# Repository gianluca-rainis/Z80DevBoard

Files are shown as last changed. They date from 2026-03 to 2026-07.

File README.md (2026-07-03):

# Z80DevBoard








The Z80DevBoard is an advanced development board for the Z80 microprocessor, based on the RP2040.

This board is meant to be a practical educational tool, to help students learn how the Z80, one of the first CPUs and the foundation of all modern ones, works, and how to develop software for it.

To the Z80 is combined a modern RP2040, a powerful microcontroller designed by Raspberry Pi.
It allows easy interaction with the board's components: you can load a program for the Z80 into RAM; or establish a serial connection with the computer to perform live operations, such as reading and writing to RAM.

The most educational components of the board are the LED matrices, which provide real-time visual feedback on the Z80's activity.
Thanks to these LEDs, you can see which address of the RAM the Z80 is accessing, the byte it's reading or writing, whether it is answering to a BUSREQ with a BUSACK, and essentially all the operations the Z80 is executing.

The board mounts five buttons: the four on the right allow the student to save a Z80 program to flash, load a custom firmware for the RP2040, reset the Z80, and put the Z80 into a wait state.
The button on the left sends a manual clock signal to the Z80, in fact, the board mounts a *Z84C00* (the *CMOS* version of the Z80) specifically to allow it to work even with a manual clock.

The board can be connected to a computer through a *USB-C* port, which provides both power and data transmission.
On the bottom-right of the board, are mounted two pin sockets, to support expansion boards or to be used in more advanced projects that require additional hardware.

For more advanced debugging, when testing custom firmware, the *SWD* and *SWCLK* pins of the RP2040 are accessible on the top-right of the board.

Front view of the dev board
Front view of the dev board

---

Z80DevBoard Picture

## Author
The author of the whole project is: 
**Gianluca Rainis** - [gianluca-rainis](https://github.com/gianluca-rainis) on GitHub.

## Sponsor
The PCB prototyping for this project is sponsored by **[PCBWay](https://www.pcbway.com)**.

The *boards* were manufactured with **high precision**, faithfully **following the PCB design down to the smallest details**.
The *silkscreen* is **crisp and perfectly readable**, with **no errors or misalignments**.
The *board edges* and corner's holes were **cut cleanly and accurately**.
The *drill holes* **match the component footprints exactly**, making placement and soldering straightforward.
The *SMD pads* are **precise and clean**, even for the most challenging footprints, and solder beautifully.

The *PCBWay website* is **intuitive, even for first-time users**.
**Placing an order is simple**, and before proceeding to payment **the design is reviewed by their technical staff**, who catch and communicate **any potential manufacturing issues** promptly and professionally, avoiding problems before production even begins.

> If you are looking for a reliable, high-quality PCB manufacturer for your own projects, **[PCBWay](https://www.pcbway.com)** is highly recommended!

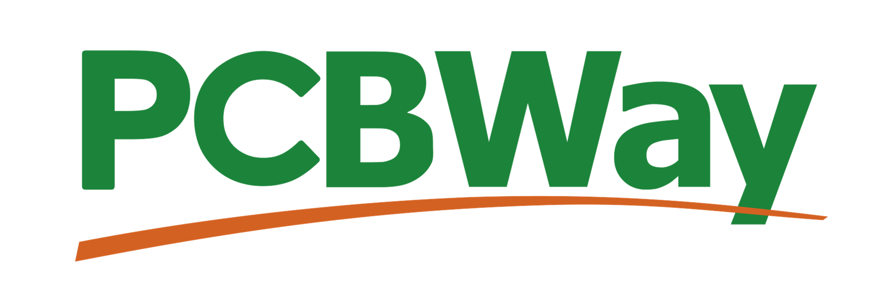
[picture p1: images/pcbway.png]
PCBWay (https://www.pcbway.com)


## License
### Hardware design files (schematics, PCB, BOM):
Licensed under [CERN-OHL-S v2.0](LICENSE-CERN-OHL-S.md)

### Software, firmware and documentation:
Licensed under the [MIT License](LICENSE-MIT.md)

## AI Disclaimer
**No AI was used in the conception, design, engineering, or development of this project**.
Every circuit and every design decision is the original work of the author.

*AI tools* were used solely as a **writing assistant** for **parts of the documentation**, to help refine and organize technical explanations.
**All content has been reviewed, verified, and edited by the author.**

## Documentation
The full documentation is available in the [`docs/`](docs/index.md) folder.

## Development Tools
- **PCB Design:** KiCad
- **Documentation and code:** Visual Studio Code

## PCB Manufacturing
The Gerber files for PCB manufacturing are available in the [`gerber/`](gerber/) directory.

## Project Structure
```
Z80DevBoard/
├── customFootprints.pretty/  # Custom footprints
├── docs/                     # The documentation and the guides
├── firmware/                 # The RP2040 firmware
├── gerber/                   # PCB manufacturing files (Gerber format)
├── images/                   # Documentation images and KiCad symbols
├── .gitattributes            # Gitattributes file
├── .gitignore                # Gitignore file
├── gerber.zip                # Zip folder with all the gerber files
├── Z80DevBoard.kicad_pcb     # PCB layout file
├── Z80DevBoard.kicad_pro     # KiCad project file
├── Z80DevBoard.kicad_sch     # Schematic file
├── Z80DevBoard.step          # 3D model
├── BOM.csv                   # Bill Of Materials
├── CHANGELOG.md              # Change log of the project
├── JOURNAL.md                # Journal of the project
├── LICENSE-CERN-OHL-S.md     # CERN-OHL-S License
├── LICENSE-MIT.md            # MIT License
└── README.md                 # This file
```

## Images
### Schematic Diagrams
#### Complete Schematic (A2 format)
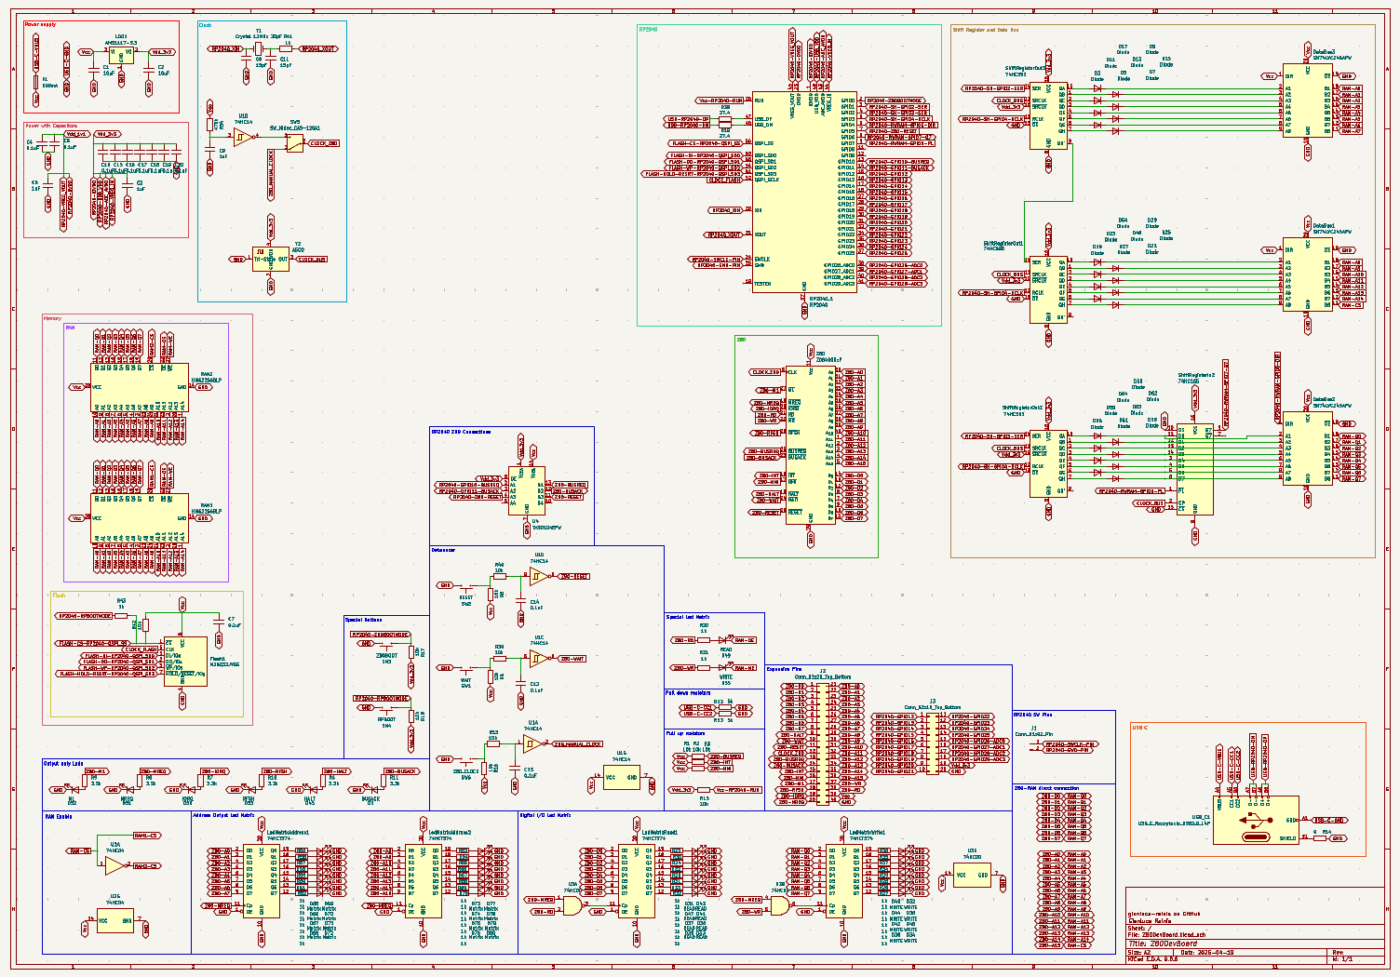
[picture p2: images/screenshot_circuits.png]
Complete schematic


#### Z80 Section
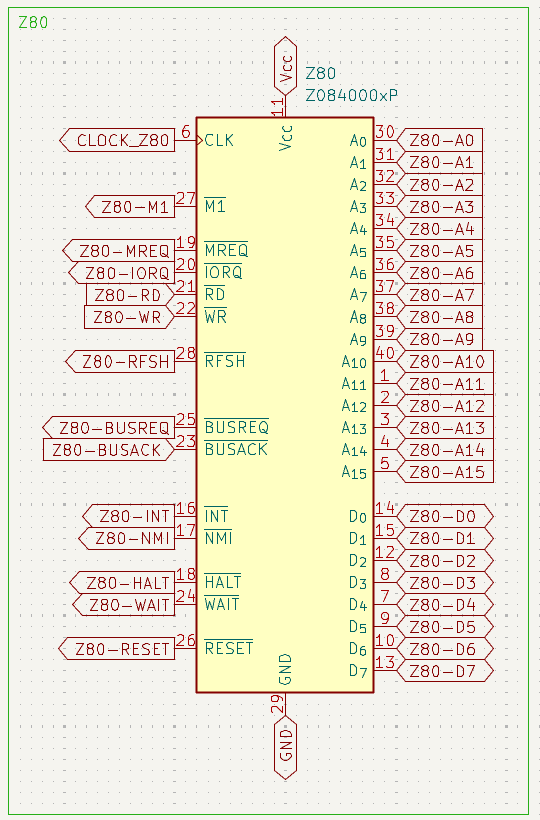
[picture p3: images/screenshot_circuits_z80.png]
Z80 subsystem schematic


#### RP2040 Section
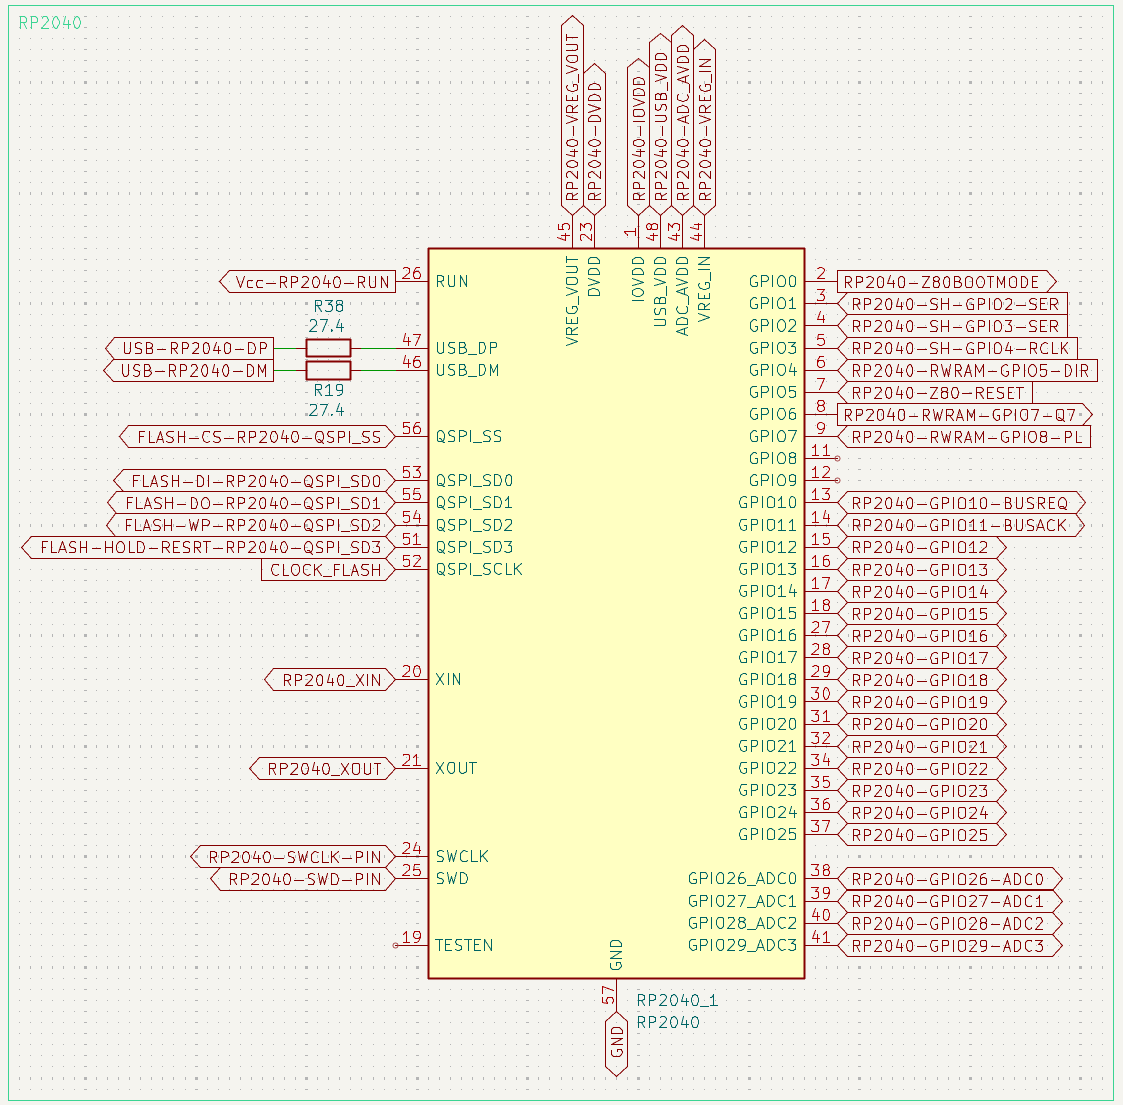
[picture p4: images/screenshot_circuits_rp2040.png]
RP2040 subsystem schematic


### PCB Layout
#### Without Silkscreen
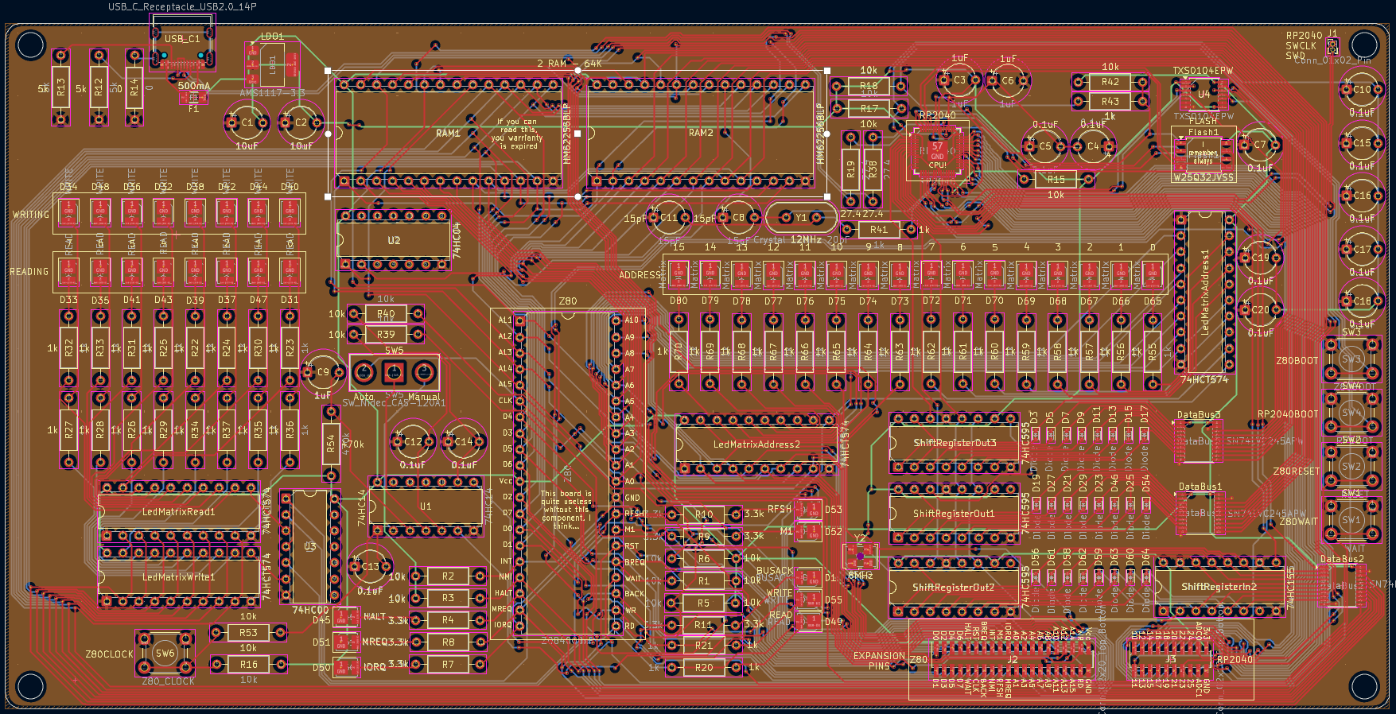
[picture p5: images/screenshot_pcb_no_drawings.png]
PCB layout without silkscreen


#### With Silkscreen
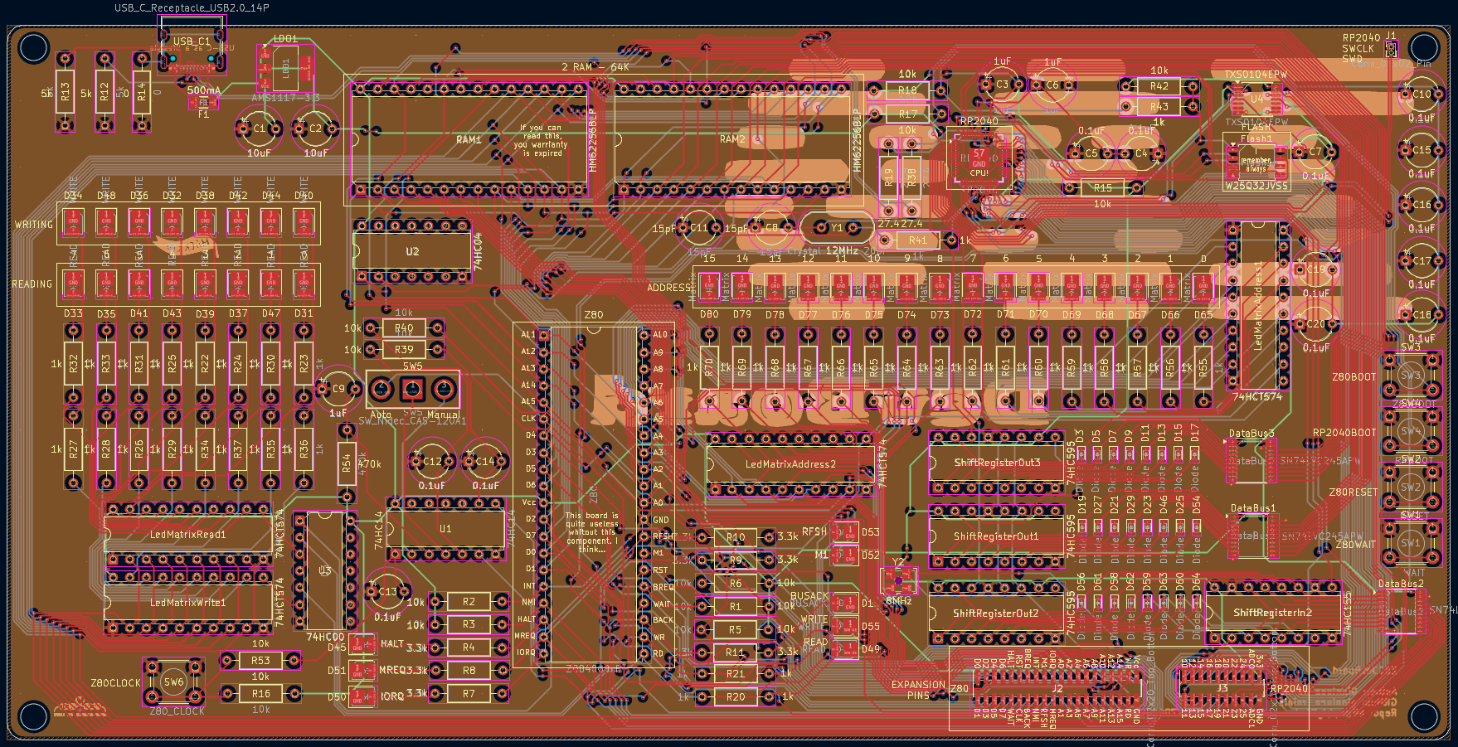
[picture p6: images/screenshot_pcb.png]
PCB layout with silkscreen


### 3D Renders
#### Front View
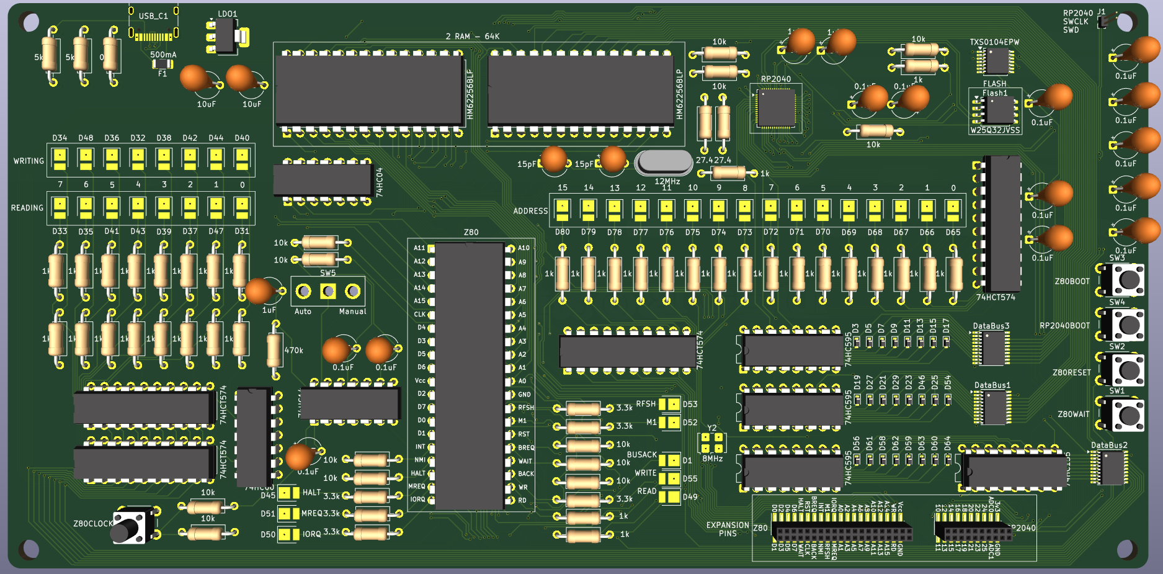
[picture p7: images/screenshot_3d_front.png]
3D render - front view


#### Back View
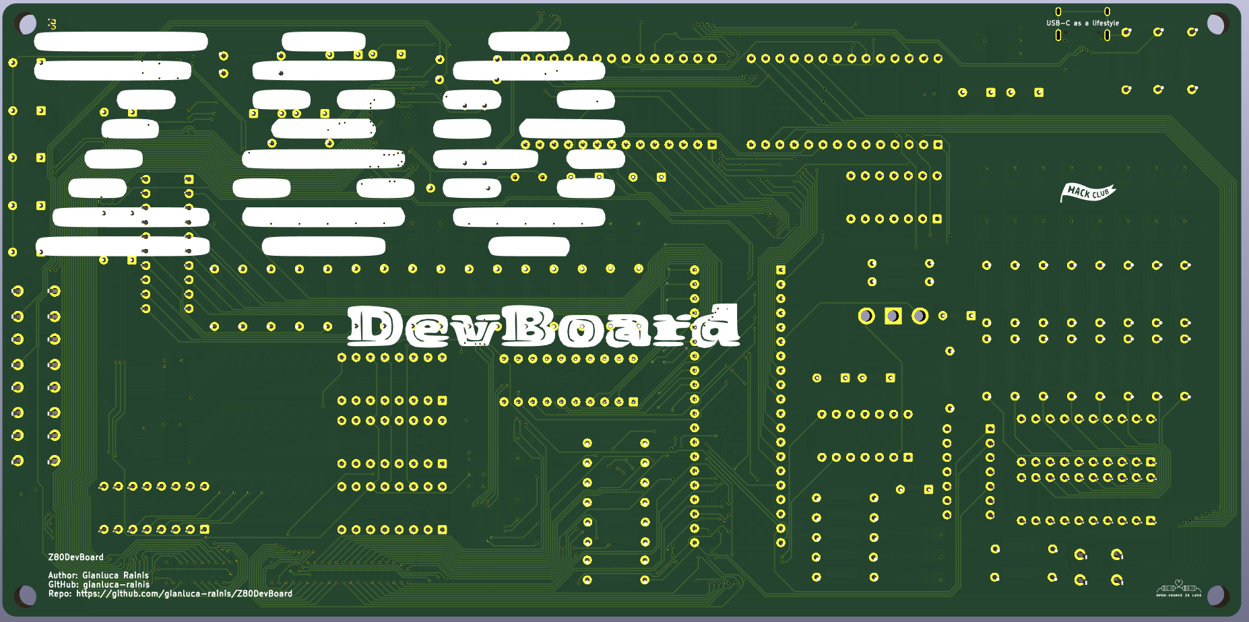
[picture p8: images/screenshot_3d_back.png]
3D render - back view


## Technical Details
- **Size**: 219mm x 108.5mm
- **Layers**: 4
- **Supply Voltage**: 5V, 3v3

## Components Table
|Name|Quantity|Class|Type|
|--|--|--|--|
|Z84C00|1|Microprocessor|Through Holes|
|RP2040|1|Microprocessor|SMD|
|||||
|HM62256BLP|2|Memory|Through Holes|
|W25Q32JVSS|1|Memory|SMD|
|||||
|AMS1117-3.3|1|Power Management|SMD|
|||||
|USB C 2.0 port|1|Data Bus|Through Holes|
|74HC595|3|Data Bus|Through Holes|
|74HC155|1|Data Bus|Through Holes|
|74HCT574|4|Data Bus|Through Holes|
|SN74LVC245APW|3|Data Bus|SMD|
|TXS0104EPW|1|Data Bus|SMD|
|Connector 2 pins|1|Data Bus|Through Holes|
|Connector 2×20 pins|1|Data Bus|Through Holes|
|Connector 2×10 pins|1|Data Bus|Through Holes|
|||||
|Crystal 12MHz 20pF|1|Clock|Through Holes|
|Oscillator 8MHz|1|Clock|SMD|
|||||
|74HC14|1|Support components|Through Holes|
|74HC04|1|Support components|Through Holes|
|74HC00|1|Support components|Through Holes|
|||||
|Resistor 0 ohm|1|Resistor|Through Holes|
|Resistor 27.4 ohm|2|Resistor|Through Holes|
|Resistor 1k ohm|36|Resistor|Through Holes|
|Resistor 3.3k ohm|6|Resistor|Through Holes|
|Resistor 5k ohm|2|Resistor|Through Holes|
|Resistor 10k ohm|13|Resistor|Through Holes|
|Resistor 470k ohm|1|Resistor|Through Holes|
|||||
|Capacitors 15pF|2|Capacitor|Through Holes|
|Capacitors 0.1uF|13|Capacitor|Through Holes|
|Capacitors 1uF|4|Capacitor|Through Holes|
|Capacitors 10uF|2|Capacitor|Through Holes|
|||||
|Button|5|Other|Through Holes|
|Switch|1|Other|Through Holes|
|LED|40|Other|SMD|
|Diodes|24|Other|SMD|
|Fuse 500mA|1|Other|SMD|

## Firmware
### Firmware Video Presentation
https://github.com/user-attachments/assets/ee6d8d69-4003-4e21-8f2b-2f08ad0c8d81

### Build
From the project root, make sure CMake and the ARM GNU toolchain (arm-none-eabi-gcc) are installed.

If the toolchain is not in your PATH, provide it explicitly with PICO_TOOLCHAIN_PATH:

```bash
cmake -S firmware -B firmware/build -DPICO_TOOLCHAIN_PATH=/path/to/arm-gnu-toolchain
cmake --build firmware/build --parallel
```

If the toolchain is already in your PATH, you can omit PICO_TOOLCHAIN_PATH.

#### Output file
The file to load in the RP2040's memory after the build is `Z80DevBoard.uf2`.
You can find it in the `/firmware/build` folder.

> You can find more informations about the firmware, including how to write a custom one, in the [documentation](docs/index.md).

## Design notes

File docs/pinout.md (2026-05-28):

# Chapter 3 - Pinout & Connectors

## 3.1 Z80 Pinout
The *Z84C00* is available in a **40-pin DIP package**.
The pinout below reflects the official Zilog datasheet.

```
              ┌───────────────────┐
       A11 ⬅ │  1             40 │ ⮕ A10
       A12 ⬅ │  2     Z80     39 │ ⮕ A9
       A13 ⬅ │  3             38 │ ⮕ A8
       A14 ⬅ │  4             37 │ ⮕ A7
       A15 ⬅ │  5             36 │ ⮕ A6
       CLK ⮕ │  6             35 │ ⮕ A5
        D4 ⬌ │  7             34 │ ⮕ A4
        D3 ⬌ │  8             33 │ ⮕ A3
        D5 ⬌ │  9             32 │ ⮕ A2
        D6 ⬌ │ 10             31 │ ⮕ A1
       Vcc ⮕ │ 11             30 │ ⮕ A0
        D2 ⬌ │ 12             29 │ ⬅ GND
        D7 ⬌ │ 13             28 │ ⮕ /RFSH
        D0 ⬌ │ 14             27 │ ⮕ /M1
        D1 ⬌ │ 15             26 │ ⬅ /RESET
      /INT ⮕ │ 16             25 │ ⬅ /BUSRQ
      /NMI ⮕ │ 17             24 │ ⬅ /WAIT
     /HALT ⬅ │ 18             23 │ ⮕ /BUSACK
     /MREQ ⬅ │ 19             22 │ ⮕ /WR
     /IORQ ⬅ │ 20             21 │ ⮕ /RD
              └───────────────────┘
```

|Symbol|Pin|Direction|Description|
|---|---|---|---|
|A0–A15|30-40, 1–5|Output|16-bit address bus|
|D0–D7|14, 15, 12, 8, 7, 9, 10, 13|Bidirectional|8-bit data bus|
|CLK|6|Input|System clock|
|/MREQ|19|Output|Memory request (active low)|
|/IORQ|20|Output|I/O request (active low)|
|/RD|21|Output|Read operation indicator (active low)|
|/WR|22|Output|Write operation indicator (active low)|
|/M1|27|Output|With /MREQ indicates opcode fetch cycle, with /IORQ indicates interrupt acknowledge cycle (active low)|
|/RFSH|28|Output|DRAM refresh cycle (active low)|
|/HALT|18|Output|CPU halted (active low)|
|/WAIT|24|Input|Insert wait states (active low)|
|/INT|16|Input|Maskable interrupt request (active low)|
|/NMI|17|Input|Non-maskable interrupt request (active low)|
|/RESET|26|Input|Reset (active low)|
|/BUSRQ|25|Input|Bus request (active low)|
|/BUSACK|23|Output|Bus acknowledge (active low)|
|Vcc|11|Power|+5V supply|
|GND|29|Power|Ground|

## 3.2 RP2040 Pinout
The *RP2040* is available in a **56-pin QFN package**.
The pinout below reflects the official Raspberry Pi datasheet.

```
QSPI_SS_N QSPI_SD1 QSPI_SD2 QSPI_SD0 QSPI_SCLK QSPI_SD3 DVDD IOVDD USB_VDD USB_DP USB_DM VREG_VIN VREG_VOUT ADC_AVDD
       ┌───────────────────────────────────────────────┐
       │   56 55 54 53 52 51 50 49 48 47 46 45 44 43   │
       │                                               │
 IOVDD │  1                                         42 │ IOVDD
 GPIO0 │  2                                         41 │ GPIO29/ADC3
 GPIO1 │  3                                         40 │ GPIO28/ADC2
 GPIO2 │  4                                         39 │ GPIO27/ADC1
 GPIO3 │  5              ┌───────────┐              38 │ GPIO26/ADC0
 GPIO4 │  6              │           │              37 │ GPIO25
 GPIO5 │  7              │    GND    │              36 │ GPIO24
 GPIO6 │  8              │           │              35 │ GPIO23
 GPIO7 │  9              └───────────┘              34 │ GPIO22
 IOVDD │ 10                                         33 │ IOVDD
 GPIO8 │ 11                                         32 │ GPIO21
 GPIO9 │ 12                                         31 │ GPIO20
GPIO10 │ 13                                         30 │ GPIO19
GPIO11 │ 14                                         29 │ GPIO18
       │                                               │
       │   15 16 17 18 19 20 21 22 23 24 25 26 27 28   │
       └───────────────────────────────────────────────┘
GPIO12 GPIO13 GPIO14 GPIO15 TESTEN XIN XOUT IOVDD DVDD SWCLK SWDIO RUN GPIO16 GPIO17
```

|Symbol|Pin|Direction|Description|
|---|---|---|---|
|GPIO0–GPIO25|2-9, 11-18, 27-32, 34-37|Configurable|General purpose I/O|
|GPIO26/ADC0|38|Configurable|GPIO or ADC (Analog to Digital Converter) channel 0|
|GPIO27/ADC1|39|Configurable|GPIO or ADC (Analog to Digital Converter) channel 1|
|GPIO28/ADC2|40|Configurable|GPIO or ADC (Analog to Digital Converter) channel 2|
|GPIO29/ADC3|41|Configurable|GPIO or ADC (Analog to Digital Converter) channel 3|
|XIN|20|Input|Crystal oscillator input (12 MHz)|
|XOUT|21|Output|Crystal oscillator output|
|USB_DP|47|Bidirectional|USB D+ (27Ω resistor required)|
|USB_DM|46|Bidirectional|USB D− (27Ω resistor required)|
|SWCLK|24|Input|SWD clock (debug)|
|SWDIO|25|Bidirectional|SWD data (debug)|
|RUN|26|Input|Reset (active low)|
|VREG_VIN|45|Power|Voltage regulator input (1.8V to 3.3V) (1uF capacitor required)|
|VREG_VOUT|44|Power|Voltage regulator output (1.1V core) (1uF capacitor required)|
|IOVDD|1, 10, 22, 33, 42, 49|Power|GPIO supply (1.8V to 3.3V)|
|DVDD|23, 50|Power|Digital core supply (1.1V)|
|ADC_AVDD|43|Power|ADC analog supply (3.3V)|
|USB_VDD|48|Power|USB PHY supply (3.3V)|
|GND|Center Pad|Power|Ground|
|QSPI_*|51–56|Bidirectional|Interface to a SPI flash (Usable also as GPIO)|

## 3.3 Expansion Connector 2×20 (Z80 Bus)
The *Expansion Connector (Z80 Bus)* is a **2×20 pin connector** located on the bottom-right of the Z80DevBoard.
It exposes all **Z80 bus signals**, providing direct access to the CPU interface for daughter boards and external hardware.

```
 D0 D2 D4 D6 HALT RST BREQ INT M1 IORQ A0 A2 A4 A6 A8 A10 A12 A14 WR Vcc
  1  3  5  7  9 11 13 15 17 19 21 23 25 27 29 31 33 35 37 39
┌────────────────────────────────────────────────────────────┐
│ ●  ●  ●  ●  ●  ●  ●  ●  ●  ●  ●  ●  ●  ●  ●  ●  ●  ●  ●  ● │
│ ●  ●  ●  ●  ●  ●  ●  ●  ●  ●  ●  ●  ●  ●  ●  ●  ●  ●  ●  ● │
└────────────────────────────────────────────────────────────┘
  2  4  6  8 10 12 14 16 18 20 22 24 26 28 30 32 34 36 38 40
 D1 D3 D5 D7 WAIT CLK BACK NMI RFSH MREQ A1 A3 A5 A7 A9 A11 A13 A15 RD GND
```

|Symbol|Pin|Direction|Description|
|---|---|---|---|
|D0–D7|1-8|Bidirectional|8-bit data bus|
|HALT|9|Output|CPU halted (active low)|
|WAIT|10|Input|Insert wait states (active low)|
|RST|11|Input|Reset (active low)|
|CLK|12|Input|System clock|
|BREQ|13|Input|Bus request (active low)|
|BACK|14|Output|Bus acknowledge (active low)|
|INT|15|Input|Maskable interrupt request (active low)|
|NMI|16|Input|Non-maskable interrupt request (active low)|
|M1|17|Output|With MREQ indicates opcode fetch cycle, with IORQ indicates interrupt acknowledge cycle (active low)|
|RFSH|18|Output|DRAM refresh cycle (active low)|
|IORQ|19|Output|I/O request (active low)|
|MREQ|20|Output|Memory request (active low)|
|A0–A15|21-36|Output|16-bit address bus|
|WR|37|Output|Write operation indicator (active low)|
|RD|38|Output|Read operation indicator (active low)|
|Vcc|39|Power|+5V supply|
|GND|40|Power|Ground|

## 3.4 Expansion Connector 2×10 (RP2040)
The *Expansion Connector (RP2040)* is a **2×10 pin connector** located on the bottom-right of the Z80DevBoard.
It exposes GPIO pins 10 through 25, two ADC pins, and the 3v3 power rail, allowing the development of more advanced projects on expansion boards with custom firmware.

```
 GPIO10 GPIO12 GPIO14 GPIO16 GPIO18 GPIO20 GPIO22 GPIO24 ADC0 3v3
  1  3  5  7  9 11 13 15 17 19
┌──────────────────────────────┐
│ ●  ●  ●  ●  ●  ●  ●  ●  ●  ● │
│ ●  ●  ●  ●  ●  ●  ●  ●  ●  ● │
└──────────────────────────────┘
  2  4  6  8 10 12 14 16 18 20
 GPIO11 GPIO13 GPIO15 GPIO17 GPIO19 GPIO21 GPIO23 GPIO25 ADC1 GND
```

|Symbol|Pin|Direction|Description|
|---|---|---|---|
|GPIO10-GPIO25|1-16|Configurable|General purpose I/O|
|ADC0-ADC1|17-18|Configurable|GPIO or ADC (Analog to Digital Converter) channel 0 and 1|
|3v3|19|Power|+3.3V supply|
|GND|20|Power|Ground|

## 3.5 SWD Debug Connector
The SWD (*Serial Wire Debug*) interface is exposed through two dedicated pins located in the top-right corner of the Z80DevBoard.
It provides a direct connection to the RP2040's debug port, allowing firmware to be flashed and debugged using any SWD-compatible adapter, such as a *Raspberry Pi Debug Probe*.

```
 SWCLK
  1
┌───┐
│ ● │
│ ● │
└───┘
  2
 SWD
```

|Symbol|Pin|Direction|Description|
|---|---|---|---|
|SWCLK|1|Input|SWD clock (debug)|
|SWD|2|Bidirectional|SWD data (debug)|

> A ground reference is available on the *GND* pins of the *Expansion connector*.

---

<div>
  <p align="left">
    <em>
      <b>
        <a href="/docs/hardware.md">
          ← Back
        </a>
      </b>
    </em>
  </p>

  <p align="right">
    <em>
      <b>
        <a href="/docs/quickstart.md">
          Next Section →
        </a>
      </b>
    </em>
  </p>
</div>

---

<p align="center">
    <em>Open source, Open Education - Z80DevBoard</em>
</p>

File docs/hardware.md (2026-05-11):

# Chapter 2 - Hardware Architecture

## 2.1 System Overview
The Z80DevBoard is a **4-layer PCB** measuring *219 × 108.5 mm*, designed around two central processing units: the **Z84C00** (Z80) and the **RP2040**.
The board operates at **5V** via USB-C, with an onboard *AMS1117-3.3* regulator supplying the **3.3V** rail to the RP2040 and the supporting logic.

The Z80 is the execution core: it runs assembly programs stored in the two onboard *HM62256BLP* SRAM chips, which together provide **64 KB of addressable memory**.

The RP2040 acts as the interface layer **between the developer and the board**: it reads the compiled program from the *W25Q32JVSS* flash memory and loads it into SRAM before releasing the Z80.

The data bus is managed by a set of *SN74LVC245APW* bus transceivers, which handle the **voltage difference** between the **Z80's 5V logic** and the **RP2040's 3.3V logic**.

Three *74HC595* shift registers allow the RP2040 to drive the bus over a serial interface, while the *74HC165* reads it back. A dedicated oscillator drives the Z80 clock, selectable between manual and automatic mode via an onboard switch; the RP2040 runs off a **12 MHz crystal**.

Forty LEDs, organized in matrices and driven by *74HCT574* buffers, provide **real-time visual feedback** of Z80 bus activity.

Two expansion connectors expose additional signals for daughter boards and custom projects.

## 2.2 The Z80 CPU
The Z80 is an **8-bit microprocessor** designed by ***Zilog*** and first introduced in 1976.
Despite its age, it remains one of the **most studied and documented CPU** architectures ever produced, and its influence can still be traced in modern instruction set designs.

The specific model used on the Z80DevBoard is the *Z84C00*: the ***CMOS* variant** of the original Z80.
Compared to the original *NMOS* version, the *Z84C00* offers several practical advantages: significantly **lower power consumption**, **full static operation** (meaning the clock can be slowed down to DC without losing register contents), and better **noise immunity** thanks to the wider logic voltage margins typical of *CMOS* technology.
It is also considerably easier to source today than original *NMOS* parts.

The *Z84C00* operates with a **5V supply** and communicates with the rest of the board through three buses: a **16-bit address bus**, an **8-bit bidirectional data bus**, and a set of control signals that coordinate every memory and I/O operation.
With 16 address lines, the CPU can directly address **up to 64 KB** of memory: exactly the amount provided by the onboard SRAM.

## 2.3 The RP2040
The RP2040 is a dual-core ARM Cortex-M0+ **microcontroller** developed by ***Raspberry Pi*** and released in 2021.
It runs at up to *133MHz*, integrates *264KB of SRAM*, and includes a rich set of peripherals, among which the most relevant is the *Programmable I/O* (*PIO*): a set of small, deterministic state machines capable of handling **GPIO pins** with cycle-accurate timing.

On the Z80DevBoard, the RP2040 serves as the primary interface between **the developer and the hardware**.
At boot, it **reads the compiled Z80 program** from the onboard flash memory and **transfers it into SRAM**, where the Z80 will execute it.
During execution, it monitors the Z80 control signals in real time, handles I/O bus cycles, and maintains the serial connection with the host computer over USB.

The RP2040 runs at **3.3V**, while the Z80 operates at **5V**.
All signals exchanged between the two pass through *level shifters* and *bus transceivers* that **handle the voltage difference** transparently.
Communication with the *shift registers*, used to **extend the RP2040's effective GPIO count**, happens over a **fast serial interface**, keeping the pin usage manageable without sacrificing bus performance.

The RP2040 also exposes its ***SWD* debug interface** on dedicated pins, allowing firmware to be **developed and debugged with standard tools** such as a ***Raspberry Pi Debug Probe*** or **any compatible SWD adapter**.

## 2.4 The SRAM
The Z80DevBoard mount two *HM62256BLP* chips as its main memory: a classic **32KB × 8-bit Asynchronous Static RAM**.
Mounted **in parallel**, the two chips provide **a combined address space** of *64KB*, which is **the maximum the Z80 can directly address** with its 16-bit address bus.

Unlike Dynamic RAM (*DRAM*), Static RAM **does not require periodic refresh cycles** to retain its contents.
This **simplifies the board design** considerably: there is **no need for a dedicated refresh controller**, and the Z80's `/RFSH` pin, which would normally **trigger DRAM refresh**, is simply **left unused**.
As long as the board is powered, the memory contents remain intact.

The *HM62256BLP* is an **asynchronous device**, meaning **it does not rely on a shared clock** signal to coordinate read and write operations.
Instead, timing is governed entirely by the Z80's control signals: `/MREQ`, `/RD`, and `/WR`, which the SRAM monitors directly.
A **read cycle** completes as soon as **the address has been stable** for the chip's access time; a **write cycle** latches the data **on the rising edge of `/WR`**.

At boot, the **RP2040 takes control of the bus** and **writes the compiled Z80 program** into *SRAM* before releasing the CPU from reset.
From that point on, the Z80 reads instructions and data, and writes results back, to these two chips for the entire duration of program execution.

## 2.5 The Flash Memory
The *W25Q32JVSS* is a *32Mbit* (*4MB*) ***SPI* *NOR* flash memory** chip, used on the Z80DevBoard as **persistent storage for the RP2040 firmware and the Z80 program**.
Unlike *SRAM*, flash memory **retains its contents** when the board is powered off, making it the natural choice for **storing code** that needs to survive **between sessions**.

The RP2040 communicates with the flash chip over **a dedicated *SPI* bus**.
At boot, it **reads the compiled Z80 program from flash** and transfers it into *SRAM* before releasing the Z80 from reset.
The RP2040's own firmware is also stored on the same chip, following the standard *Raspberry Pi Pico* architecture where the **RP2040 boots directly from an *external SPI flash***.

From the Z80's perspective, **the flash memory is completely invisible**: the CPU only ever interacts with the *SRAM*.
The flash is **exclusively managed by the RP2040**, which handles all read and write operations transparently in the background.

## 2.6 The LED Matrices
The Z80DevBoard features ***40 LEDs* organized in matrices**, one of the most distinctive and educationally valuable aspects of the board.
Each LED reflects **the real-time state of a specific signal or data line**, giving an **immediate visual representation** of **what the Z80 is doing** at any given moment, without the need for an oscilloscope or a logic analyzer.

The LEDs are driven by *74HCT574* *octal D-type flip-flop buffers*, which latch the current state of the bus.
Without buffering, the signals on a running Z80 bus change far too rapidly to be perceived directly, at even a modest clock frequency, individual bus cycles last only a few hundred nanoseconds.
The buffers solve this by capturing a snapshot of the bus state and holding it stable until the next update.

This is where the **manual clock mode becomes particularly powerful**: by stepping through the program one clock cycle at a time, **the LEDs update with each step**, allowing you to **follow the execution of every instruction in real time** and **observe exactly how the Z80 reads from and writes to memory**.
Combined with the serial connection to the RP2040, this makes the Z80DevBoard a **genuinely transparent system**: one where **the internal state of the CPU is always visible** and never hidden.

## 2.7 The Expansion Pins
The Z80DevBoard exposes **two expansion connectors** designed to make the board the foundation of a larger system, rather than a closed, self-contained unit.

The first is a *2×20 pin connector* that breaks out **all 40 pins of the Z80**: address bus, data bus, and control signals; giving direct access to the full CPU interface.
This connector is intended for daughter boards that **extend the Z80's environment**: additional memory, custom peripherals, or any hardware that needs to interact directly with the Z80 bus.

The second is a *2×10 pin connector* that exposes **a selection of RP2040** signals: the **3.3V and GND power** rails, the **two *ADC*** inputs (*ADC0* and *ADC1*), and *GPIO10* through *GPIO25*.
This connector is oriented towards **more advanced projects** where the **RP2040 itself needs to interact with external hardware**: sensors, displays, communication modules, or custom firmware **experiments that go beyond the standard board functionality**.

Together, the two connectors cover **both sides of the system**: the **Z80's classic parallel bus interface** and the **RP2040's modern programmable I/O**, making it possible to build virtually **any extension imaginable** on top of the Z80DevBoard.

## 2.8 The USB-C
The board **is powered and connected to the host computer** through a single *USB-C 2.0* connector.
It serves two distinct purposes simultaneously: **delivering the 5V supply voltage to the board**, and **providing a full-speed USB data connection to the RP2040**.

On the power side, the **5V** rail feeds the Z80 directly and passes through the onboard *AMS1117-3.3* regulator to generate the **3.3V** rail for the RP2040 and the supporting logic.
A *500mA* fuse protects the board from overcurrent conditions.

On the data side, the RP2040 enumerates as a *USB CDC* (*Communications Device Class*) serial device, appearing as a virtual *COM* port on the host computer.
This connection is used to **upload compiled Z80 programs** to the board, **interact with the RP2040** firmware, and **read any output the Z80 program produces** at runtime.
No special driver is required on Linux or macOS; on Windows, the board appears as a standard *COM* port in Device Manager.

The choice of *USB-C* makes the board **compatible with modern laptops and workstations** without the need for adapters, while keeping the connector **robust enough for repeated use in an educational environment**.

## 2.9 How It All Connects
The center of the board is the Z80, connected to the two *SRAM* chips through its full *16-bit* address bus and *8-bit* data bus.
Every memory access the Z80 performs (fetching an instruction, reading a variable, writing a result) travels directly across these buses to and from the *SRAM*.

The RP2040 sits **alongside the Z80**, connected to the same data and control buses through a set of *SN74LVC245APW* bus transceivers and *74HC595* - *74HC165* shift registers.
The transceivers **handle the voltage difference** between the Z80's 5V logic and the RP2040's 3.3V logic, while the shift registers allow the RP2040 to **read and drive the bus over a compact serial interface**, keeping GPIO usage under control.
A *TXS0104EPW* level shifter handles the `BUSREQ` and `BUSACK` signals specifically, which coordinate bus ownership between the two chips.

The *W25Q32JVSS* flash memory is connected exclusively to the RP2040 over *SPI*.
The Z80 has no direct access to it, the flash is managed only by the RP2040, which uses it to store firmware and the Z80 program persistently between sessions.

The LED matrices, driven by *74HCT574* buffers, display the state of data and address buses in real time.
The buffers stay between the bus and the LEDs, ensuring that the display logic **never interferes with bus** timing.

The *USB-C* connector provides 5V to the board and connects it directly to the RP2040's USB pins, establishing the serial link with the host computer.
The *AMS1117-3.3* regulator is positioned between the 5V input and the 3.3V rail, supplying the RP2040 and all the 3.3V logic on the board.

Finally, the two expansion connectors provide the Z80 bus and the RP2040 GPIO pins, making every relevant signal accessible to external hardware without interfering with the rest of the board.

The board is laid out on a 4-layer PCB.
The front copper layer (*F.Cu*) and the back copper layer (*B.Cu*) are used for the **general signal routing**.
The inner layer *In1.Cu* is dedicated to the **power distribution network**, carrying **both the 5V and 3.3V rails** across the board.
The inner layer *In2.Cu* is a **solid ground plane**, providing a **clean reference for all signals** and **reducing electromagnetic interference**.

---

<div>
  <p align="left">
    <em>
      <b>
        <a href="/docs/introduction.md">
          ← Back
        </a>
      </b>
    </em>
  </p>

  <p align="right">
    <em>
      <b>
        <a href="/docs/pinout.md">
          Next Section →
        </a>
      </b>
    </em>
  </p>
</div>

---

<p align="center">
    <em>Open source, Open Education - Z80DevBoard</em>
</p>

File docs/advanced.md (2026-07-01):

# Chapter 5 - Advanced Guide

## 5.1 Flashing the Firmware
To flash a new firmware onto the RP2040:
1. Hold the *RP2040BOOT* button while connecting the board to your computer through the USB-C port.
2. The RP2040 will expose a **mass storage device** on your computer: it will appear as a USB drive.
3. Copy your **compiled UF2 firmware** file onto the drive.
4. The RP2040 will reset automatically and boot with the new firmware.

> The latest official firmware for the Z80DevBoard is available in the firmware folder of the repository.

## 5.2 Serial Communication with the RP2040
The RP2040 exposes a **USB CDC (Communications Device Class) serial interface** over the USB-C connector, which appears as a virtual COM port on the host computer.
This interface allows sending commands to the board and receiving output in real time, without any additional hardware.

To connect, open a serial terminal at ***115200* baud, *8N1*** (8 bit of data for each byte, No parity, 1 bit of stop) on the port assigned to the board by your operating system.

### Available Commands
`read <addrstart> [addrend]`

Reads one or more bytes from RAM and returns them as space-separated hexadecimal values.

```
read 0x0000        -> FF
read 0x0000 0x0004 -> FF A1 00 33 00
```

---

`write <addr> <value>`

Writes a single byte to the specified RAM address.
Returns the value read back from that address after the write: if it matches the value sent, the write was successful.

```
write 0x0FFF FF -> FF
```

If the readback differs from the written value, it indicates that an issue happened while writing that memory cell.

### Error Responses
All commands return an error message prefixed with ERROR: if the input is malformed:

```
read              -> ERROR: missing address
read 0xGGGG       -> ERROR: invalid address '0xGGGG'
write 0x0000      -> ERROR: missing value
unknowncmd        -> ERROR: unknown command 'unknowncmd'
```

## 5.3 Writing Custom RP2040 Firmware
The Z80DevBoard's official firmware is open source and built with the **Raspberry Pi Pico SDK**, written in **C**.
This section covers how to set up a development environment, build firmware from source, and extend it with your own functionality.

### 5.3.1 Setting Up the Development Environment
You will need:
- **CMake** (3.13 or later)
- **GCC ARM toolchain** (arm-none-eabi-gcc)
- **Pico SDK** (cloned from the official Raspberry Pi repository)
- **Git**

Clone the Z80DevBoard repository and move in the project's folder:
```bash
git clone https://github.com/gianluca-rainis/Z80DevBoard.git

cd Z80DevBoard
```

---

#### Linux (Debian/Ubuntu-based)
```bash
sudo apt update
sudo apt install cmake gcc-arm-none-eabi libnewlib-arm-none-eabi build-essential git

cd firmware
git clone -b master https://github.com/raspberrypi/pico-sdk.git
cd pico-sdk
git submodule update --init
export PICO_SDK_PATH=$(pwd)
```

#### macOS
```bash
brew install cmake arm-none-eabi-gcc git

cd firmware
git clone -b master https://github.com/raspberrypi/pico-sdk.git
cd pico-sdk
git submodule update --init
export PICO_SDK_PATH=$(pwd)
```

#### Windows
The simplest approach is to use the official **Raspberry Pi Pico Setup Windows installer**, which configures CMake, the ARM toolchain, and the Pico SDK automatically.
Alternatively, install the prerequisites manually via MSYS2 or the ARM GNU Toolchain installer, then clone the Pico SDK as shown above.

On all platforms, make sure the `PICO_SDK_PATH` environment variable points to your Pico SDK directory, this is required by the build system.

### 5.3.2 Building the Firmware
Build the firmware repository with CMake:
```bash
mkdir build
cmake --build build --parallel
```

If the build succeeds, a `.uf2` file will be produced in the `build/` directory, this is the file you flash onto the board.

### 5.3.3 Flashing Custom Firmware
Custom firmware is flashed the same way as official releases, using the *RP2040BOOT* button described in section [5.1 Flashing the Firmware](advanced.md#51-flashing-the-firmware):
1. Hold *RP2040BOOT* while connecting the board via USB-C.
2. The RP2040 exposes itself as a mass storage device.
3. Copy your compiled `.uf2` file onto the drive.
4. The board resets automatically and boots into your custom firmware.

> Always keep a copy of the latest official `.uf2` firmware on hand, so you can restore the board to its default behavior if your custom firmware doesn't work as expected.

> Remember that you can always use the *SWD* and *SWCLK* pins on the board to live debug your firmware.

### 5.3.4 Adding a New UART Command
The UART command parser, implemented in `uart.c`, dispatches incoming commands by comparing the first word of the input line.
Adding a new command means adding a new branch to this dispatch logic and writing a handler function for it.

As an example, here's how to add a `version` command that reports the firmware version:
```c
// In uart.c

#define FIRMWARE_VERSION "1.0.0"

// Handle command: version
static void cmdVersion(char *args) {
    printf("Z80DevBoard firmware v%s\n", FIRMWARE_VERSION);
}

// Dispatch a command string to the appropriate handler.
void uartProcessCommand(const char *cmd) {
    // ... existing code ...

    if (strcmp(verb, "read") == 0) {
        cmdRead(args);
    }
    else if (strcmp(verb, "write") == 0) {
        cmdWrite(args);
    }
    else if (strcmp(verb, "version") == 0) {
        cmdVersion(args);
    }
    else {
        printf("ERROR: unknown command '%s'\n", verb);
    }
}
```

Any handler function follows the same pattern: it receives the remainder of the command line as a string (`args`), parses whatever parameters it needs, performs its operation, and writes a response using `printf`.

### 5.3.5 Using the Expansion GPIO Pins
The expansion pins exposed on the 2×10 connector (`GPIO10-GPIO25`, `ADC0`, `ADC1`) are defined in `firmware.h` but left uninitialised by default, since their use depends entirely on your project.

To use them, uncomment and adapt the relevant `gpio_init` calls in `setup()`:
```c
gpio_init(GPIO_EXPANSION_1);
gpio_set_dir(GPIO_EXPANSION_1, GPIO_OUT);
```

For analog input via the ADC-capable pins, initialise the RP2040 ADC peripheral instead of treating the pin as a digital GPIO:
```c
#include "hardware/adc.h"

adc_init();
adc_gpio_init(GPIO_EXPANSION_ADC0);
adc_select_input(0);

uint16_t result = adc_read();
```

Once initialised, you can read or drive these pins anywhere in your firmware: inside `loop()`, inside a UART command handler, or inside an interrupt handler if you configure one.

### 5.3.6 A Note on the Z80 Bus
Any custom firmware that interacts with the Z80 bus (reading or writing SRAM, monitoring control signals) must respect the bus arbitration protocol.
Always call `sendBusReqAndWaitBusAck()` before accessing the bus directly, and `releaseBusReq()` once finished, to avoid bus contention with the Z80.

## 5.4 Using an Expansion Board
The Z80DevBoard exposes **two expansion connectors** described in detail in [Chapter 3 - Pinout & Connectors](pinout.md).
Both are **dual-row SMD female** connectors with ***1.27 mm* pitch**.

To use a *third-part* or *community-designed* expansion board, check that it has matching **dual-row *1.27 mm* pitch male pin headers** on its **underside** and that it is **designed for the Z80DevBoard pinout**.
Plug it directly into the connectors.
**No soldering required**.

Before powering on, verify the following:
- Check the **voltage levels** of the expansion board. Signals on the 2×20 connector are at *5V* (Z80 bus), while signals on the 2×10 connector are at *3.3V* (RP2040 GPIO). Make sure the expansion board **is designed for the correct voltage** on each connector, and use a **level shifter** if interfacing between the two.
- Check the expansion board's power requirements. The *5V* pin (pin 39 on the 2×20) and the *3.3V* pin (pin 19 on the 2×10) can supply power, but the 3.3V rail is limited by the RP2040's onboard LDO. Power-hungry boards **should be supplied independently**.
- The ADC pins are analog inputs. **Do not exceed 3.3V on these pins**.
- If the expansion board requires custom RP2040 firmware, refer to section [5.3 Writing Custom RP2040 Firmware](advanced.md#53-writing-custom-rp2040-firmware) and **flash it before use**.

## 5.5 Developing an Expansion Board
Designing an expansion board for the Z80DevBoard requires attention to both **mechanical and electrical compatibility**.

### Mechanical Requirements
The two expansion connectors on the Z80DevBoard are **dual-row SMD female** connectors with ***1.27 mm* pitch**.
Your expansion board must use matching **dual-row *1.27 mm* pitch male pin headers on its underside**, aligned to the Z80DevBoard pinout as described in [Chapter 3 - Pinout & Connectors](pinout.md).
When designing the PCB, make sure the connector footprints are **placed on the bottom layer** of the expansion board, so that the board sits flat on top of the Z80DevBoard when plugged in.

### Electrical Considerations
Signals on the 2×20 connector are at **5V** (Z80 bus).
Design any circuit connected to these pins for **5V logic**, or add a **level shifter** if interfacing with **3.3V components**.

Signals on the 2×10 connector are at **3.3V** (RP2040 GPIO).
**Do not exceed 3.3V on any of these pins**.

The *ADC* pins (*ADC0*, *ADC1*) are analog inputs with a **maximum of 3.3V**.
Keep analog signals clean and **away from noisy** digital traces on your PCB.
If your board requires **more power** than the onboard rails can provide, add an **independent power input** rather than relying on the Z80DevBoard's LDO.

### PCB Design in KiCad
The Z80DevBoard is **designed in *KiCad***, and using the same tool for your expansion board ensures **full compatibility**.

The connector footprints to use are **standard *2×20* and *2×10* male pin headers with 1.27 mm pitch**: these are available in the *KiCad standard library*.

To verify alignment, import the Z80DevBoard PCB as a reference layer in your KiCad project and check that the **connector positions match** before ordering.

### RP2040 Firmware
If your expansion board uses GPIO pins from the 2×10 connector, those pins must be initialised in the RP2040 firmware.
The expansion GPIO definitions are already present in `firmware.h`:

```c
#define GPIO_EXPANSION_1  12
#define GPIO_EXPANSION_2  13
// ...
#define GPIO_EXPANSION_ADC1 27
#define GPIO_EXPANSION_ADC2 28
#define GPIO_EXPANSION_ADC3 29
```

**Uncomment** the corresponding `gpio_init` and `gpio_set_dir` calls in `setup()`, then add your logic to `loop()` or dedicated handler functions.
Refer to section [5.3 Writing Custom RP2040 Firmware](advanced.md#53-writing-custom-rp2040-firmware) for further guidance.

## 5.6 Debugging with SWD
The Z80DevBoard exposes the **RP2040's *SWD*** (*Serial Wire Debug*) interface through **two dedicated pins** located in the top-right corner of the board, as described in [Chapter 3 - Pinout & Connectors](pinout.md).

*SWD* allows **full debugging of the RP2040 firmware**: setting breakpoints, stepping through code, inspecting memory and registers, and flashing new firmware: all without pressing the *RP2040BOOT* button.

### What You Need
- A **SWD-compatible debug probe**: the official *Raspberry Pi Debug Probe* is recommended, but any *CMSIS-DAP* compatible adapter works.
- *OpenOCD* or other tools **supporting *CMSIS-DAP*** as the debug backend.
- An *IDE* with **debugging support**: *VS Code* with the *Cortex-Debug* extension is the most common choice for *Pico SDK* projects.

### Connecting the Probe
Connect the debug probe to the **two *SWD* pins** on the board:

|SWD Pin|Signal|
|---|---|
|1|*SWCLK*|
|2|*SWDIO*|

Use a **GND reference** from the **nearest GND pin on the expansion connector**.

### OpenOCD Configuration
A basic *OpenOCD* configuration for the RP2040:

```bash
sudo openocd -f interface/cmsis-dap.cfg -f target/rp2040.cfg
```

Once connected, you can attach *GDB*:

```bash
gdb firmware/build/Z80DevBoard.elf
(gdb) target remote localhost:3333
(gdb) monitor reset init
(gdb) continue
```

For a more comfortable experience, use the *Cortex-Debug* extension in *VS Code*, which wraps *OpenOCD* and *GDB* in a **graphical interface** with breakpoints, variable inspection, and call stack view.

---

<div>
  <p align="left">
    <em>
      <b>
        <a href="/docs/quickstart.md">
          ← Back
        </a>
      </b>
    </em>
  </p>

  <p align="right">
    <em>
      <b>
        <a href="/docs/z80Assembly.md">
          Next Section ->
        </a>
      </b>
    </em>
  </p>
</div>

---

<p align="center">
    <em>Open source, Open Education - Z80DevBoard</em>
</p>

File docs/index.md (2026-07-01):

# Z80DevBoard

## Official Documentation
- **Version:** 1.8.0
- **Author:** Gianluca Rainis
- **License:** *CERN OHL S v2.0*, *MIT License*
- **Repository:** [github.com/gianluca-rainis/Z80DevBoard](https://github.com/gianluca-rainis/Z80DevBoard)
- **Sponsor:** [PCBWay](https://www.pcbway.com/)

---

> *A bridge between the golden age of 8-bit computing and modern embedded systems.*

---

## Table of Contents
1. [Introduction & Project History](introduction.md)
2. [Hardware Architecture](hardware.md)
3. [Pinout & Connectors](pinout.md)
4. [Quick Start Guide](quickstart.md)
5. [Advanced Projects](advanced.md)
6. [Z80 Assembly Programming](z80Assembly.md)
7. [Schematics & KiCad Reference](technicalInfo.md)
8. [Conclusions](conclusions.md)

## About This Document
This documentation is designed for use in educational kits. Each chapter is self-contained and can be read independently, though following the order is recommended for beginners.

The document is structured in two layers:
- **Introductory sections** at the start of each chapter, suitable for anyone with basic electronics curiosity
- **Technical deep-dives** for those who want to understand every signal, register, and timing detail

---

<div>
  <p align="right">
    <em>
      <b>
        <a href="/docs/introduction.md">
          Next Section →
        </a>
      </b>
    </em>
  </p>
</div>

---

<p align="center">
    <em>Open source, Open Education - Z80DevBoard</em>
</p>

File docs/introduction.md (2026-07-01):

# Chapter 1 - Introduction & Project History

## 1.1 What Is the Z80DevBoard?
The **Z80DevBoard** is an open-source single-board computer that pairs a **Zilog Z80 CPU**, one of the most iconic and revolutionary 8-bit processors ever built, with an **RP2040 microcontroller**, the modern dual-core chip designed by *Raspberry Pi* that powers most of the most modern projects.

The idea is simple: the Z80 operates as it would in **its original environment**, while the RP2040 handles all interaction between the developer and the board.
The Z80 still **runs real code**, asserts real signal lines, and *behaves exactly as it did in 1976*, but the world it communicates with is managed by a modern chip running firmware that enables advanced features: loading programs over USB-C, serial communication, real-time RAM access, and the flexibility to deploy custom firmware for more complex projects.

This makes the Z80DevBoard both a **retrocomputing gem** and a **powerful educational tool**: you can study Z80 bus cycles firsthand, write and run real assembly code, and observe authentic hardware behavior, all without the complexity of building the surrounding support circuitry from scratch. Whether you are a *student* exploring **how computers truly work** at the lowest level, or an *enthusiast* who simply appreciates the **elegance of classic 8-bit architecture**, this board was built with you in mind.

## 1.2 Why Z80 + RP2040?
### The Z80: A Processor Worth Knowing
The **Zilog Z80** was developed in 1976 by **Federico Faggin** (the same engineer who designed the *Intel 4004* and *8080*). It later powered the *ZX Spectrum*, the *MSX family*, countless embedded systems, and even the *Game Boy*, which used a specially modified version of the Z80.

Despite being 50 years old, the Z80 remains an **excellent architecture to study**:
- Its instruction set is *rich yet regular*, making it *accessible*.
- Its bus protocol is *well documented* and *easy to observe* with a logic analyzer.
- It has influenced virtually *every modern CPU architecture*, including *x86* and *ARM*.
- Writing Z80 assembly code teaches you exactly *what a processor does*, without layers of abstraction.

In short, the Z80 is a museum piece today, but its impact on the history of computing was profound, and its assembly language remains one of the best windows into the real workings of a CPU.

### The RP2040: a modern microcontroller
The RP2040 is a *dual-core ARM Cortex-M0+* microcontroller developed by **Raspberry Pi** and released in 2021.
Despite its low cost, it packs a number of features that make it exceptionally well suited for this project, most notably its Programmable I/O (*PIO*) subsystem: a set of small, deterministic state machines capable of handling **GPIO** pins with precision.

In the Z80DevBoard, the RP2040 takes on the role of the primary interface between **the developer** and **the hardware**: it stores the assembled program in flash, loads it into the onboard 64K asynchronous *SRAM* at boot, handles I/O bus cycles in real time, and exposes a USB serial interface for communication with the host computer.
The expansion header additionally makes the board ready for more advanced use cases, from custom peripherals to deeper firmware experimentation.

## 1.3 Project Goals
The Z80DevBoard was designed with **three goals** in mind.

### Education first
Every **design decision is documented and explainable**. There are no obscure components: every chip on the board exists for a clear, teachable reason.
The Z80DevBoard was born as an **educational tool first**: the LED matrices and the serial connection with the RP2040 allow you to **observe Z80 operations in real time**, making it possible to **learn**, **debug**, and **truly understand** what your program is doing at every step.
The board is designed to **grow with the student**: starting from basic *Z80 assembly*, which maps directly onto topics covered in *computer architecture* and *systems* courses, all the way up to *writing custom RP2040 firmware* for **more complex, ambitious and independent projects**.

### Real hardware, real behavior
**The Z80 is not simulated.** It receives a real clock, drives real address and data buses, and asserts real control signals. You can watch *your code* execute on a *real processor*, in *real time* and *physically interact* with it.

### Open source
All *KiCad design* files are published under the **CERN OHL S v2.0** license; the *firmware* source code and this *documentation* are published under the **MIT License**.
Anyone can *manufacture the board*, *modify it*, or use it as a *starting point for their own project*, provided derivative works comply with the respective license terms. For **students** who want to *go deeper*, having access to the **full sources**, **schematics**, and **documentation** is itself a **powerful learning resource**.

## 1.4 Project History
The Z80DevBoard started from a simple desire: to **learn Z80 assembly** and **truly understand how a CPU works**.
Existing **emulators were not enough**: while functionally accurate, they could **never replicate the feeling of watching real code execute on real silicon**.
The goal became building a board that would make that possible: not just a personal learning tool, but something that could make the **study of computer architecture** more *tangible*, more *immediate*, and ultimately more *rewarding* for anyone who picks it up.

### Version 0.1.0 (Pre-release)
- Added the main components.
- Started working on the connections.
- Connected the Z80 to the RAM module.
- Created some led matrix to see the live activity of the Z80.
- Added some leds to see the bits the Z80 are writing or reading.
- Added the Wait and the Reset buttons.

### Version 0.9.0 (Pre-release)
- Fixed the connections.
- Finished all the scematics.
- Finished the pcb.
- Added the 2 layers connections on the pcb.
- Added the graphics to the pcb.
- Fixed the pcb for the 3D view.

### Version 1.0.0
- Fixed all the clocks.
- Added the manual clock for the Z80.
- Added the SWCLK and SWD pins for debug.
- Added other 2 layers.
- Added the GND layer.
- Added the Vcc and 3v3 layer.
- Fixed the borders of the board.
- Fixed some connections.

### Version 1.2.0
- Added debouncer.
- Fixed board size.
- Added the info about the leds on the front silkscreen.
- Updated the back silkscreen.
- Changed the capacitors footprint.
- Changed the switch (manual - auto clock selector).
- Fixed SWD and SCLK pins.
- Fixed the crystal and the capacitors for the RP2040 clock.
- Fixed the data bus clock.
- Made a new automatic slow clock generator for the Z80.
- Fixed some connections.

### Version 1.5.0
- Added second SRAM to have 64Kb instead of 32Kb.
- Remade the led matrix.
- Added 74HTC574 as buffers for the led matrix.
- Added one 74HC00.
- Added the components informations in the silkscreen.
- Optimized the space.
- Fixed some DRC rules violations.
- Updated the documentation.
- Updated the CERN license.

### Version 1.6.0
- Added two pin sockets for Expansion boards or more advanced progects.
- Fixed the bus clock.
- Fixed some resistors.
- Added the names of the expansion pins.
- Added the names of the Z80 pins.
- Added the debouncer for the Reset and for the Wait buttons.
- Added a TXS0102DCT for the connections between the RP2040 and the Z80 BUSREQ and BUSACK.
- Fixed some capacitors values.
- Fixed the footprint of the fuse.
- Made a custom footprint for the switch.
- Added some graphics and funny phrases.
- Fixed the sizes of the Expansion pin's names and of the Z80 pin's names.
- Changed the footprint of the capacitors.

### Version 1.7.0
- Fixed the alimentation of the RP2040.
- Fixed the footprints of the two pin extension's sockets.
- Fixed the size of the board.
- Now the project is sponsorized by PCBWay!

### Version 1.8.0 *(current)*
- Wrote the whole documentation.
- Created the CHANGELOG file.
- Created the JOURNAL file.
- Updated the firmware.
- Updated the README file.

## 1.5 What You Can Do With This Board
The Z80DevBoard lets you:
- **Run Z80 assembly programs** loaded over USB from a host computer
- **Study computer architecture** with a real, inspectable system rather than a textbook diagram
- **Observe bus activity** in real time through the onboard LED matrices, watching every read, write, and control signal as it happens
- **Step through your program manually** using the manual clock input, running the Z80 at your own pace, one cycle at a time if needed
- **Read and write RAM** in real time via the serial connection with the RP2040, inspecting and modifying memory while the Z80 is running
- **Expand the board** by connecting your own components to the expansion pin sockets, from simple peripherals to complete daughter boards
- **Write custom RP2040 firmware** to implement advanced features, experiment with the bus protocol, or build projects that go well beyond a standard development board

---

<div>
  <p align="left">
    <em>
      <b>
        <a href="/docs/index.md">
          ← Back
        </a>
      </b>
    </em>
  </p>

  <p align="right">
    <em>
      <b>
        <a href="/docs/hardware.md">
          Next Section →
        </a>
      </b>
    </em>
  </p>
</div>

---

<p align="center">
    <em>Open source, Open Education - Z80DevBoard</em>
</p>

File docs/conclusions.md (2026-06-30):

# Chapter 8 - Conclusions

## 8.1 What You Have Learned
If you have worked through this documentation and run your first programs on the Z80DevBoard, you have touched on a remarkable amount of **fundamental computer science and electronics**, knowledge that goes far beyond the Z80 itself.

### Computer Architecture
The *Z80* sits at the **root of decades of processor design**.

Understanding how it fetches instructions, manages its registers, and communicates over its buses gives you **a foundation that transfers directly to modern CPU architectures**: the same core concepts of instruction cycles, addressing modes, and bus protocols still underpin the processors running in today's computers and embedded systems.
Having worked with a real, observable Z80, you now have the conceptual tools to **understand how any computer actually works** beneath its layers of abstraction.

### Programming at the Lowest Level
You have **written, assembled, and executed real Z80 assembly**: moving data between registers and memory, implementing sorting algorithms, handling interrupts, and controlling I/O directly through hardware ports.
These are **the same fundamental operations every higher-level programming language** ultimately compiles down to: you have seen, firsthand, **what a computer is truly doing** when it runs a program.

### Electronics and PCB Design
By studying the **technical documentation** in depth (the schematics, the PCB layout, the design choices behind every component), you have also **gained insight into how the board itself was engineered**.
Concepts like voltage level shifting, bus arbitration, decoupling, and layer stack-up are not just abstract electronics theory here; they are the real reasons specific components were chosen and specific traces were routed the way they were on the board in front of you.

### The Educational Value of Hands-On Hardware
> *This is what the Z80DevBoard was built for: not just to run code, but to make the invisible visible.*

Watching a real address bus toggle on the LED matrices, stepping through a real clock cycle, and tracing a signal from its schematic symbol to its physical pin on the board **turns abstract textbook concepts into something you can see**, touch, and **understand at a level that no simulator alone could fully provide**.

## 8.2 Where to Go Next
The Z80DevBoard is a starting point, not a destination. Here are some directions worth exploring:

### On the software side:
- Implement a small operating system kernel, even a simple task switcher teaches a great deal
- Write a *BASIC* interpreter in Z80 assembly, the same approach *Microsoft* took for early 8-bit computers
- Write a custom interpreter in Z80 assembly, (more creative than a *BASIC* interpreter)
- Explore the *undocumented Z80 opcodes*, the processor has hidden instructions that most official documentation omits

### On the hardware side:
- Design and build your own expansion board, putting [5.5 Developing an Expansion Board](advanced.md#55-developing-an-expansion-board) into practice
- Write custom *RP2040 firmware* to implement new serial commands or virtual peripherals
- Add a real-time clock, a display, or an SD card interface via the expansion connectors
- Study the *KiCad* files in depth and propose your own improvements to the hardware design

### On the theory side:
- Study the Z80 machine cycle timing diagrams in the official datasheet: every nanosecond is specified
- Read about historical Z80-based systems: the *ZX Spectrum*, the *TRS-80*, the *Amstrad CPC*, the *MSX* standard
- Compare the Z80's architecture to a modern processor and identify what changed, and what didn't

## 8.3 Contributing
The Z80DevBoard is released under open licenses: the hardware under **CERN OHL S v2.0**, and the firmware and documentation under the **MIT License**.

This means:
- You are free to use, study, modify, and manufacture the hardware
- If you distribute modified versions of the hardware, you must release your changes under the same CERN OHL S v2.0 terms
- The firmware and documentation can be freely reused, modified, and redistributed under the MIT License
- Attribution to the original project is appreciated

Contributions are welcome via the GitHub repository:
- **Bug reports and corrections** - open an issue
- **Hardware improvements** - submit a pull request against the KiCad project
- **Firmware features** - submit a pull request against the firmware source
- **Documentation additions** - submit a pull request against the documentation

Repository: [github.com/gianluca-rainis/Z80DevBoard](https://github.com/gianluca-rainis/Z80DevBoard)

## 8.4 Acknowledgements
The Z80DevBoard draws on decades of publicly available documentation, open-source tooling, and community knowledge:

- **Zilog** - for producing and documenting the Z80 so thoroughly
- **Raspberry Pi Ltd** - for the RP2040 and the Pico SDK
- **The KiCad team** - truly excellent open-source PCB design software, free for everyone
- **Hack Club** - for fostering a community of young makers and giving projects like this a place to grow
- **Every student, teacher, and hobbyist** who kept 8-bit computing alive and worth caring about

> *A special thanks goes to* **[PCBWay](https://www.pcbway.com)***, whose sponsorship made the manufacturing of this board possible in the first place.*
> PCBWay (https://www.pcbway.com)
> *Their precision, reliability, and genuinely helpful technical staff turned a KiCad design file into a real, working board. Without them, this project would still be a set of schematics on a screen.*

This documentation, and the board it describes, would not exist in this form without all of the above.

---

<div>
  <p align="left">
    <em>
      <b>
        <a href="/docs/technicalInfo.md">
          ← Back
        </a>
      </b>
    </em>
  </p>
</div>

---

<p align="center">
    <em>Open source, Open Education - Z80DevBoard</em>
</p>

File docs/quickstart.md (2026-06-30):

# Chapter 4 - Quick Start Guide

## 4.1 What You Need
Before getting started, make sure you have the following:
- A fully assembled Z80DevBoard
- A USB-C cable (data-capable, not charge-only)
- A computer running Linux, Windows or macOS
- A Z80 assembler - z80asm is recommended
- A serial terminal - such as PuTTY (Windows), screen or minicom (Linux/macOS)

## 4.2 Powering the Board
Connect the USB-C cable between the board and your computer.
The LEDs light up immediately, confirming the board is receiving power.

The RP2040 initialises, requests the bus via BUSREQ, holds it while loading the program from flash into SRAM.
Once ready, the Z80 is released and begins executing.

## 4.3 Loading a Program
To load a program onto the Z80DevBoard:
1. Hold the *Z80BOOT* button while connecting the board to your computer through the USB-C port.
2. The RP2040 will expose a ***32KB* mass storage** device on your computer: it will look like a USB drive.
3. Copy your **assembled Z80 binary** onto the drive.
4. The RP2040 will **reset automatically**, load the program from flash into SRAM, and the board will be ready for execution.

The program must be a **raw Z80 binary**, not an Intel HEX file or any other format.

**Make sure to assemble your code before loading it onto the board.**

## 4.4 Running Your First Program
Once a program has been loaded, the Z80 begins executing automatically from address `0x0000`.
From this point, the board runs autonomously.
The RP2040 manages the bus in the background while the Z80 fetches instructions from SRAM and executes them in sequence.

The **LED matrices** will **immediately reflect the activity** on the address and data buses, updating in real time with every memory access.

The *Z80RESET* button restarts execution from `0x0000` **without reloading the program**, making it useful for **quick re-runs** during development.

The *Z80WAIT* button stops the execution **without reloading the program**, making it useful for **quick debug** during development.

An **onboard switch** allows toggling between *automatic clock mode* and *manual clock mode*:
- In *automatic mode*, the Z80 runs at a fixed low frequency generated by an onboard capacitors system.
- In *manual mode*, each press of the *Z80CLOCK* button **advances the clock by one cycle**, allowing you to step through your program one clock pulse at a time.

For examples and a complete guide to writing Z80 assembly programs, refer to [Chapter 6 - Z80 Assembly Programming](z80Assembly.md).

## 4.5 Using the Manual Clock
The **manual clock mode** is one of the **most powerful educational features** of the Z80DevBoard.

By stepping through the program one clock cycle at a time, you can observe **exactly what the Z80 is doing** at every stage of execution: **which address it is reading**, **what data is on the bus**, and **which control signals are active**.

To use the manual clock:
- Flip the onboard switch to **manual clock mode** (represented on the board by the label `Manual`).
- (*Optional*) Press *Z80RESET* to restart execution from `0x0000`.
- Press *Z80CLOCK* to **advance the clock by one cycle**.
- **Observe the LED matrices** after each press: the address bus, data bus, and control signals will update with every cycle.

Combined with the LED matrices, manual clock mode turns the Z80DevBoard into a **fully transparent system**: every internal state of the CPU becomes visible and inspectable, one step at a time.

## 4.6 Reading the LED Matrices
The Z80DevBoard features ***40 LEDs* organized in matrices** that display the **real-time state** of the Z80 buses.
Each LED corresponds to a specific signal line.

> When the LED is on, the line is *HIGH*; when it is off, the line is *LOW*.

The matrices are organized as follows:
|Matrix|Signals|Description|
|---|---|---|
|Address Bus|A0–A15|The *16-bit* memory address the Z80 is currently accessing|
|Data Bus (*WRITING*)|D0–D7|The *8-bit* value being written|
|Data Bus (*READING*)|D0–D7|The *8-bit* value being read|
|HALT|HALT|The CPU has executed a *HALT* instruction|
|MREQ|MREQ|The Z80 is performing a memory access|
|IORQ|IORQ|The Z80 is performing an I/O port access|
|RFSH|RFSH|The Z80 is performing a *DRAM* refresh cycle|
|M1|M1|The Z80 is fetching an opcode (with *MREQ*) or is acknowledging an interrupt (with *IORQ*)|
|BUSACK|BACK|The Z80 has released the bus in response to a BUSREQ|
|WRITE|WR|The Z80 is writing data to memory or an I/O port|
|READ|RD|The Z80 is reading data from memory or an I/O port|

The LEDs are most readable in *manual clock mode*: since the bus changes faster than the human eye can follow at normal clock speeds, stepping one cycle at a time allows you to read each matrix clearly after every press of *Z80CLOCK*.

In *automatic clock mode*, the low frequency of the onboard oscillator still makes the matrices partially readable, giving a general sense of program activity even without stepping manually.

---

<div>
  <p align="left">
    <em>
      <b>
        <a href="/docs/pinout.md">
          ← Back
        </a>
      </b>
    </em>
  </p>

  <p align="right">
    <em>
      <b>
        <a href="/docs/advanced.md">
          Next Section →
        </a>
      </b>
    </em>
  </p>
</div>

---

<p align="center">
    <em>Open source, Open Education - Z80DevBoard</em>
</p>

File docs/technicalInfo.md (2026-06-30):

# Chapter 7 - Schematics & KiCad Reference

## 7.1 PCB Overview
The Z80DevBoard is a **4-layer PCB** measuring *219 × 108.5 mm*, designed to be both functional and readable.

Component placement follows a logical layout: the Z80 occupies the center of the board, the RP2040 module sits to the top-right, and the two SRAM chips are placed directly above the Z80.
The USB-C connector is located in the top-left corner.
The LED matrices are distributed around the Z80: the data bus matrices (read and write) are to the left, the address bus matrices run along the right side, and the control signal LEDs (such as MREQ, M1, and HALT) are placed close to their respective Z80 pins for clarity.
The expansion connectors are located on the bottom-right, keeping them accessible for daughter boards.

Top view of the Z80DevBoard  
*Top view of the Z80DevBoard*

The silkscreen includes labels for every Z80 pin, every expansion pin, and all the onboard buttons and switches, making the board self-documenting and easy to use without referring to this manual.

Bottom view of the Z80DevBoard  
*Bottom view of the Z80DevBoard*

## 7.2 Schematic
The full schematic is available in `Z80DevBoard.kicad_sch` and can be opened with KiCad 10.0 or later.
The images below show the main sections of the schematic for reference.

Full schematic  
*Full schematic*

Z80 CPU  
*Z80 CPU*

RP2040  
*RP2040*

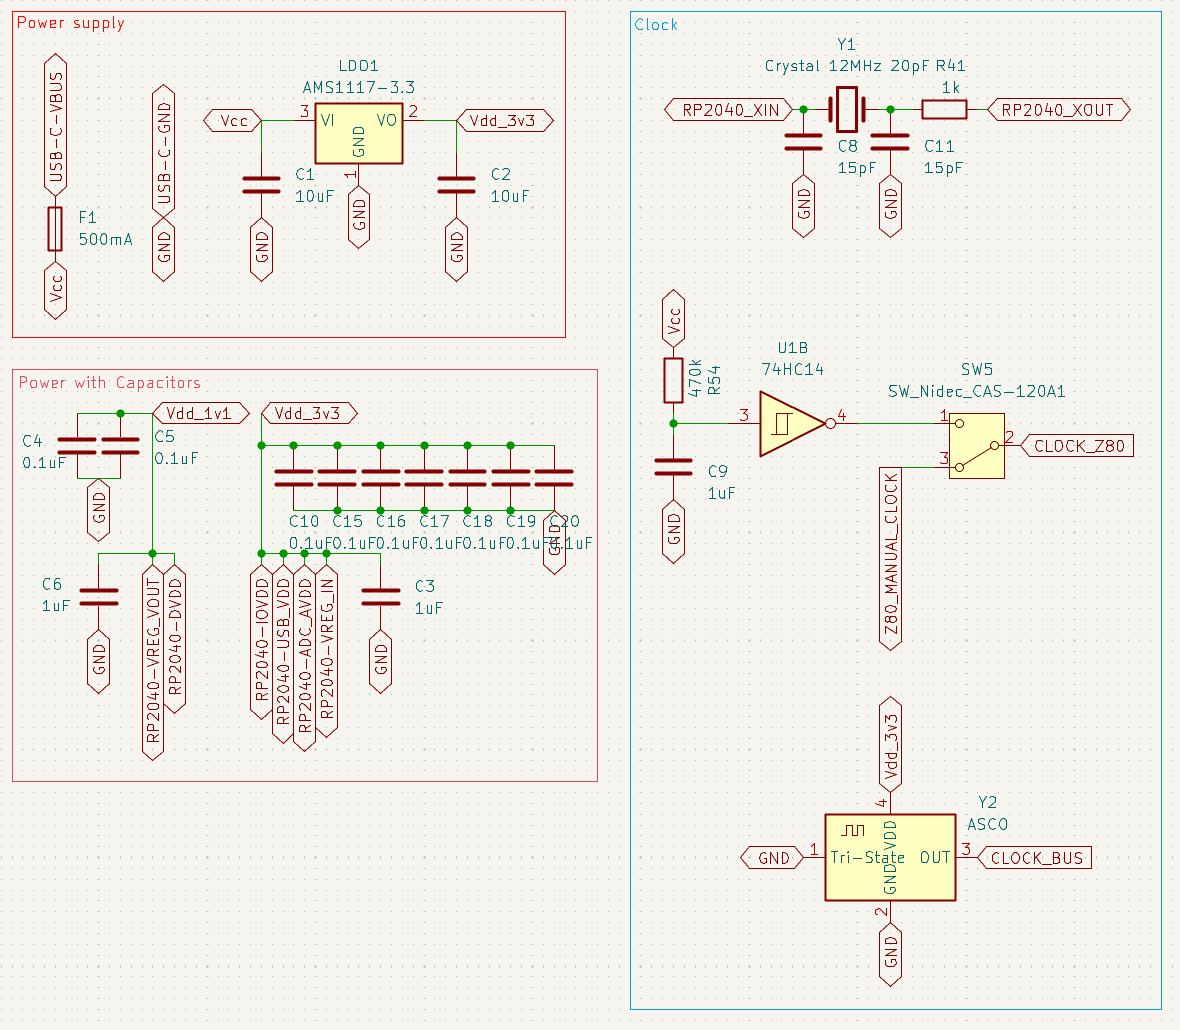
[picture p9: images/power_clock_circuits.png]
Power supply and clock
  
*Power supply and clock*

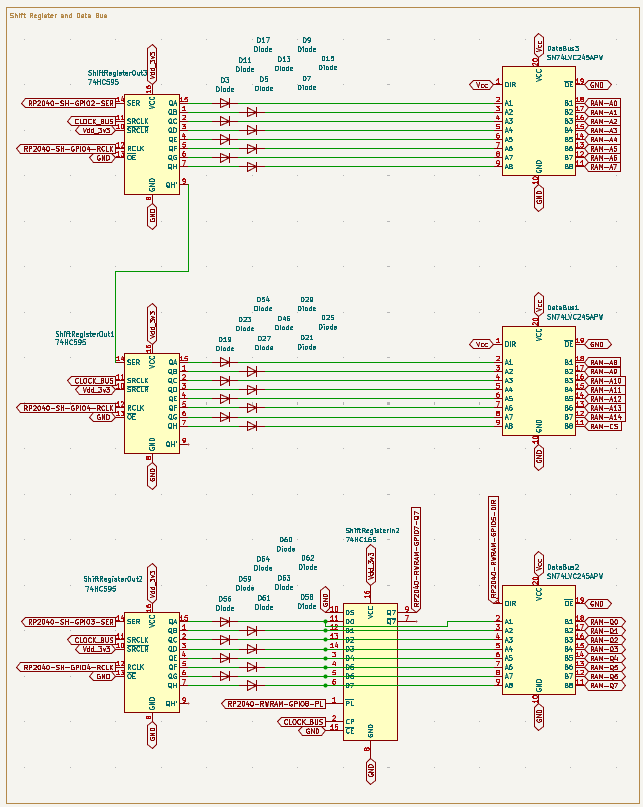
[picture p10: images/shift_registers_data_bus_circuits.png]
Shift registers and Data bus
  
*Shift registers and Data bus*

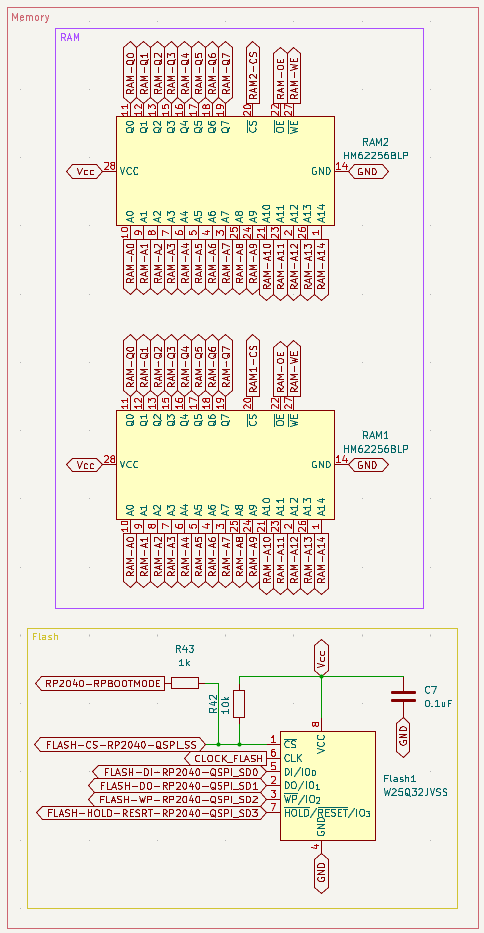
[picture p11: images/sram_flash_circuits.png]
SRAM and flash
  
*SRAM and flash*

## 7.3 PCB Layout
The PCB layout was designed in KiCad with attention to **signal integrity**, **routing clarity**, and **ease of hand-assembly**.
The board uses **4 layers**: *F.Cu* and *B.Cu* for general signal routing, *In1.Cu* for the power distribution network (5V and 3.3V), and *In2.Cu* as a solid ground plane.

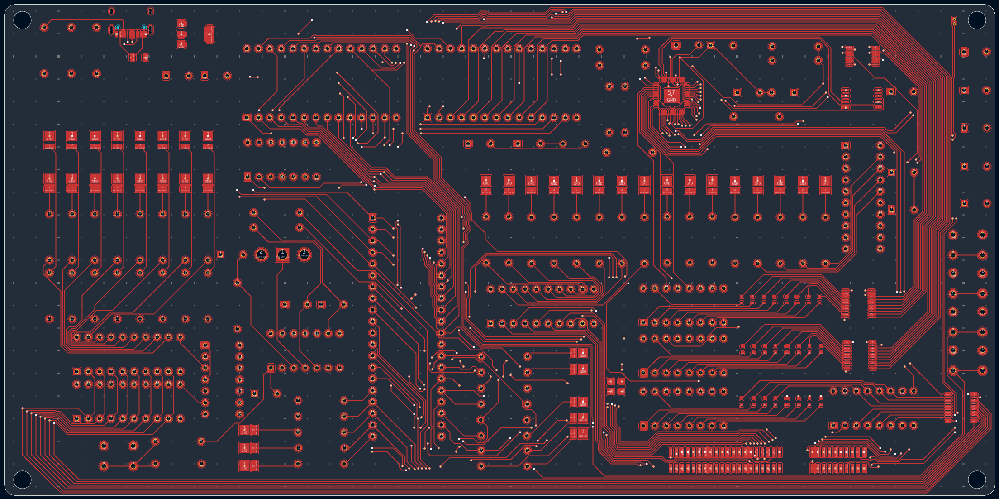
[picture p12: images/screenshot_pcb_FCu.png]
Front copper layer (F.Cu)
  
*Front copper layer (F.Cu)*

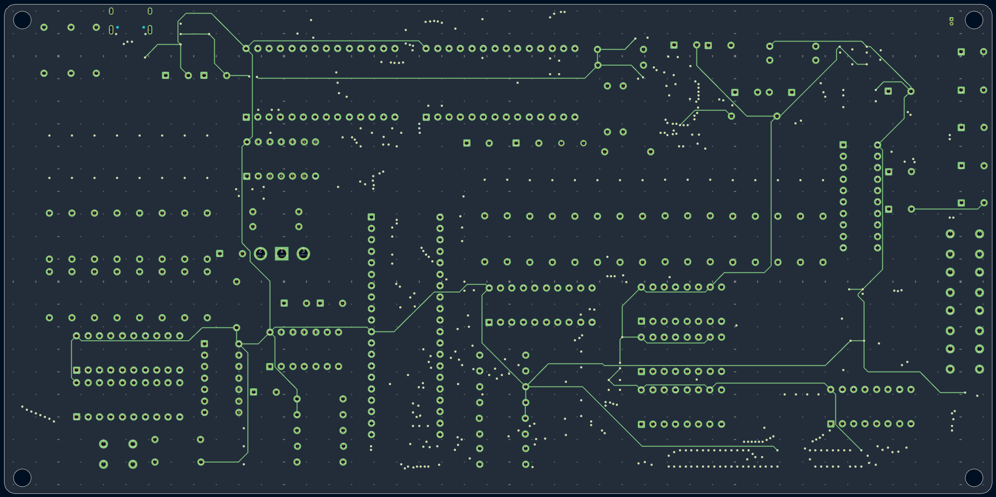
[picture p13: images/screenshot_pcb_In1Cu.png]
Inner layer In1.Cu
  
*Inner layer In1.Cu*

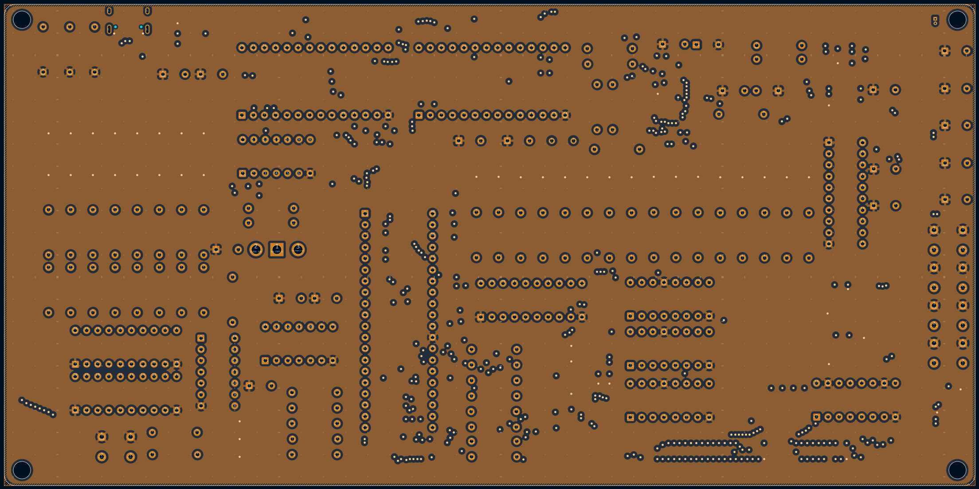
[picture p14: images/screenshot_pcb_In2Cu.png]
Inner layer In2.Cu
  
*Inner layer In2.Cu*

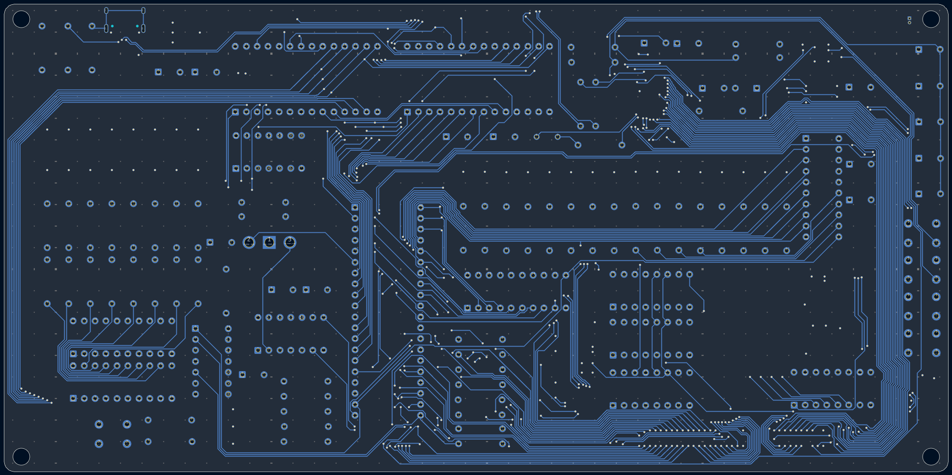
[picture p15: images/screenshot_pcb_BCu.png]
Back copper layer (B.Cu)
  
*Back copper layer (B.Cu)*

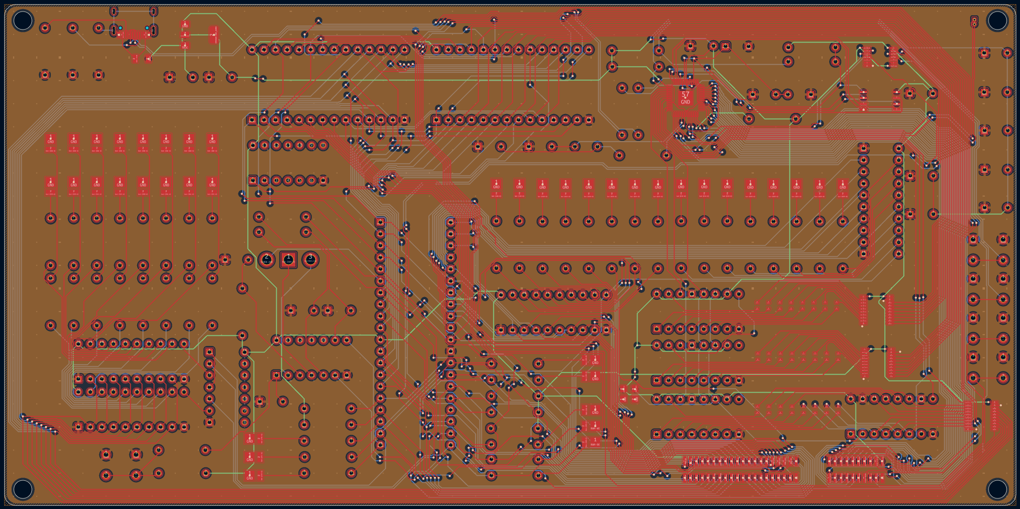
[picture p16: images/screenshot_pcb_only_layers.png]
All layers combined
  
*All layers combined*

## 7.4 3D Render
KiCad's built-in 3D viewer was used to generate a render of the assembled board, useful for previewing component placement before manufacturing and for visualizing the board without needing a physical unit on hand.

3D render - top view  
*3D render - top view*

3D render - bottom view  
*3D render - bottom view*

## 7.5 The Real Board
Photos of the assembled, manufactured Z80DevBoard, shown here for reference alongside the 3D render and schematics.

Assembled Z80DevBoard - top view  
*Assembled Z80DevBoard - top view*

Assembled Z80DevBoard - bottom view  
*Assembled Z80DevBoard - bottom view*

## 7.6 Design Choices
This section explains the reasoning behind some of the key hardware decisions made on the Z80DevBoard.

### Why the Z84C00?
The *CMOS* variant of the Z80 was chosen specifically because **it supports full static operation**, meaning **the clock can be slowed down** to DC without losing register state.
This is **what makes manual clocking possible**: stepping through a program one cycle at a time would simply **not work with the original *NMOS Z80***, which requires a **minimum clock frequency to function** correctly.

### Why asynchronous SRAM?
Asynchronous *SRAM* was chosen for **simpler, more direct memory access from both the Z80 and the RP2040**.
Since it doesn't rely on a shared clock to coordinate read and write operations, both processors can access it independently, each governed by its own timing: the Z80 through its native bus protocol, and the RP2040 through the shift registers.

### Why the RP2040?
The RP2040 was chosen as a **modern microcontroller** that offers a **rich set of advanced features** (PIO, dual cores, ample SRAM, USB) at a low cost, making it an ideal companion processor for managing the Z80 environment without requiring custom ASICs or excessive support circuitry.

### Why shift registers and bus transceivers?
**Shift registers** allow the RP2040 to control the full Z80 address bus and data bus **using only a handful of GPIO pins**, instead of dedicating 24 pins directly to bus signals.
**Bus transceivers** handle the **voltage difference between the Z80's *5V* logic and the RP2040's *3.3V* logic**, allowing the two to communicate safely.

### Why the LED matrices?
The LED matrices let you **observe the Z80's bus activity in real time**, without needing a computer, an oscilloscope, or a logic analyzer connected.
This was a deliberate choice to **keep the board self-contained and immediately readable**.

### Why the buttons?
- *Z80BOOT* - Enters mass storage mode to load a new Z80 program.
- *RP2040BOOT* - Enters mass storage mode to flash custom RP2040 firmware.
- *Z80RESET* - Manually resets the CPU without need to reload the program.
- *Z80WAIT* - Halts the Z80 mid-execution, useful when running on the automatic clock.
- *Z80CLOCK* - Manually advances the clock by one cycle, used in manual clock mode.

### Why SWD and SWCLK?
The ***SWD* debug interface** enables **advanced debugging of the RP2040** like setting breakpoints, inspecting memory and stepping through code, which becomes **essential for custom firmware development**.

### Why expansion pins?
The expansion connectors are there to **support advanced projects** beyond the board's default functionality: custom I/O handling, hardware actions triggered by interrupts, or entirely new peripherals built on top of the existing platform.

### Why USB-C?
USB-C is the modern standard, present on virtually every laptop and workstation today, eliminating the need for adapters or legacy cables.

---

<div>
  <p align="left">
    <em>
      <b>
        <a href="/docs/z80Assembly.md">
          ← Back
        </a>
      </b>
    </em>
  </p>

  <p align="right">
    <em>
      <b>
        <a href="/docs/conclusions.md">
          Next Section →
        </a>
      </b>
    </em>
  </p>
</div>

---

<p align="center">
    <em>Open source, Open Education - Z80DevBoard</em>
</p>

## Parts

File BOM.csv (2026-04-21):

Item | Quantity | Price | Link
Z84C00 | 1 | 5.44€ | https://it.aliexpress.com/item/1005009333955800.html
RP2040 | 1 | 4.05€ | https://www.melopero.com/shop/boards/pico/raspberrypirp2040lotto5pezzi/
HM62256BLP | 2 | 5.48€ | https://www.ebay.it/itm/404413365170
W25Q32JVSS | 1 | 4.93€ | https://it.aliexpress.com/item/1005007710572639.html
AMS1117-3.3 | 1 | 1.67€ | https://it.aliexpress.com/item/1005009941982629.html
USB C 2.0 port | 1 | 3.07€ | https://it.aliexpress.com/item/1005008805157100.html
74HC595 | 3 | 2.36€ | https://it.aliexpress.com/item/1005010401959630.html
74HC155 | 1 | 14.69€ | https://it.aliexpress.com/item/1005009894977656.html
74HCT574 | 4 | 2.49€ | https://it.aliexpress.com/item/1005007229463668.html
SN74LVC245APW | 3 | 1.05€ | https://it.aliexpress.com/item/1005008696175075.html
TXS0104EPW | 1 | 1.46€ | https://it.aliexpress.com/item/1005004668468003.html
Connector 2 pins | 1 | 1.59€ | https://it.aliexpress.com/item/4000979931385.html
Connector 2x20 pins | 1 | 8.07€ | https://it.aliexpress.com/item/1005007017658956.html
Connector 2x10 pins | 1 | 6.25€ | https://it.aliexpress.com/item/1005007017658956.html
Crystal 12MHz 20pF | 1 | 1.22€ | https://www.ebay.it/itm/263567429638
Oscillator 8MHz | 1 | 1.98€ | https://www.ebay.com/itm/364037958378
74HC14 | 1 | 5.05€ | https://it.aliexpress.com/item/1005007408238420.html
74HC04 | 1 | 2.27€ | https://it.aliexpress.com/item/1005008029271455.html
74HC00 | 1 | 3.65€ | https://it.aliexpress.com/item/1005007018312570.html
Resistor 0 ohm | 1 | 3.17€ | https://it.aliexpress.com/item/1005008084460988.html
Resistor 27.4 ohm | 2 | 2.74€ | https://it.aliexpress.com/item/1005007345052730.html
Resistor 1k ohm | 36 | 2.82€ | https://it.aliexpress.com/item/1005007345052730.html
Resistor 3.3k ohm | 6 | 2.70€ | https://it.aliexpress.com/item/1005007345052730.html
Resistor 5k ohm | 2 | 2.78€ | https://it.aliexpress.com/item/1005007345052730.html
Resistor 10k ohm | 13 | 2.73€ | https://it.aliexpress.com/item/1005007345052730.html
Resistor 470k ohm | 1 | 2.78€ | https://it.aliexpress.com/item/1005007345052730.html
Capacitors 15pF | 2 | 0.88€ | https://it.aliexpress.com/item/1005008596894135.html
Capacitors 0.1uF | 13 | 1.23€ | https://it.aliexpress.com/item/1005006925643424.html
Capacitors 1uF | 4 | 1.36€ | https://it.aliexpress.com/item/1005006925643424.html
Capacitors 10uF | 2 | 1.53€ | https://it.aliexpress.com/item/1005006925643424.html
Button | 5 | 1.46€ | https://it.aliexpress.com/item/1005007838995217.html
Switch | 1 | 3.94€ | https://it.aliexpress.com/item/1005010660243402.html
LED | 40 | 2.01€ | https://it.aliexpress.com/item/1005006235139318.html
Diodes | 24 | 1.23€ | https://it.aliexpress.com/item/1005003394917074.html
Fuse 500mA | 1 | 2.51€ | https://it.aliexpress.com/item/1005005406783769.html

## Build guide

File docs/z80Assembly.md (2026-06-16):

# Chapter 6 - Z80 Assembly Programming

## 6.1 Introduction to Z80 Assembly
**Assembly language** is the human-readable form of a **processor's machine code**.
Each line corresponds directly to **one instruction the CPU executes**, without compiler; runtime; or framework between you and the hardware.

Writing Z80 assembly means writing exactly **what the processor will do**, one operation at a time: load a value into a register, add two numbers, jump to a different part of the program.
There is **no abstraction**, **no hidden behavior**, and **no overhead**.

> *What you write is what runs.*

This directness is what makes assembly both **challenging** and deeply **educational**.
Understanding Z80 assembly means understanding **how any CPU works** at its most fundamental level: how instructions are fetched and decoded, how memory is addressed, how control flow is implemented in hardware.

These concepts underlie **every programming language** and **every processor architecture** in use today.
The Z80 is one of the **best architectures to learn assembly** on: its **instruction set is rich but regular**, its **documentation is thorough**, and its **behavior is entirely predictable**.

> *Once you understand the Z80, the principles transfer directly to other architectures.*

## 6.2 The Z80 Register Set
The *Z80 CPU* contains *208 bits* of **read/write memory**, configured as **eighteen *8-bit* registers** and **four *16-bit* registers**.
There are **two sets of six general-purpose registers**, **two sets of Accumulator and Flag registers**, and **six special-purpose registers**.

### Main Register Set
|Accumulator|Flags|
|---|---|
|A|F|
|B|C|
|D|E|
|H|L|

### Alternate Register Set
|Accumulator|Flags|
|---|---|
|A'|F'|
|B'|C'|
|D'|E'|
|H'|L'|

### Special Purpose Registers
|Use|Register|
|---|---|
|Interrupt Vector|I|
|Memory Refresh|R|
|||
|Index Register|IX|
|Index Register|IY|
|Stack Pointer|SP|
|Program Counter|PC|

## 6.3 The Flag Register
The **Flag Registers** (**F** and **F'**) are two *8-bit* registers automatically updated by the CPU after arithmetic and logic operations.
Each bit represents a specific condition, used by conditional instructions to decide whether to jump, call, or return.

|Bit|Flag|Name|Set when|
|---|---|---|---|
|7|S|Sign|Result is negative (bit 7 of result = 1)|
|6|Z|Zero|Result is zero|
|5|X|Not used|-|
|4|H|Half Carry|Carry from bit 3 to bit 4 (used by DAA)|
|3|X|Not used|-|
|2|P/V|Parity / Overflow|Even parity (logic ops) or signed overflow (> +128 or < -128)|
|1|N|Add / Subtract|Last operation was a subtraction (N = 1) or an addition (N = 0)|
|0|C|Carry|Result produced a carry or borrow|

The Flag Register cannot be written directly, it is only modified as a side effect of instructions.
It can however be saved and restored via the stack using `PUSH AF` and `POP AF`, or via the alternate register with `EX AF, AF'`.

## 6.4 Addressing Modes
Addressing modes define how an instruction locates its operands.
The Z80 supports the following addressing modes.

### Immediate
The byte immediately following the opcode in memory contains the operand.

```asm
LD A, 42          ; A <- 42
```

### Immediate Extended
The two bytes following the opcode are the operand, forming a 16-bit value.

```asm
LD HL, 0x8000     ; HL <- 0x8000
```

### Modified Page Zero
A single-byte `RST` instruction calls one of eight fixed locations in *Page 0* of memory, saving memory space for commonly-used subroutines.

```asm
RST 0x08          ; Call subroutine at 0x0008
```

### Relative
A signed 8-bit displacement is added to the address of the following instruction to form a jump target.
Allows relocatable code and saves memory space compared to extended jumps.

```asm
JR Z, LABEL       ; Relative jump to LABEL if Zero flag set
```

### Extended
Two bytes of address are included in the instruction, used as a pointer to a memory location or as a jump destination.

```asm
LD A, (0x4000)    ; A <- memory[0x4000]
JP 0x0100         ; Jump to 0x0100
```

### Indexed
A signed 8-bit displacement is added to an index register (IX or IY) to form a pointer to memory.
The index register itself is not modified.

```asm
LD A, (IX+5)      ; A <- memory[IX + 5]
LD (IY-2), B      ; Memory[IY - 2] <- B
```

### Register
The operand is a CPU register, specified by bits in the opcode.

```asm
LD A, B           ; A <- B
ADD A, C          ; A <- A + C
```

### Implied
The operand is implicitly defined by the opcode, no explicit address is needed.

```asm
RLCA              ; Rotate A left (A is implied)
DAA               ; Decimal adjust A (A is implied)
```

### Register Indirect
A 16-bit register pair is used as a pointer to a memory location.

```asm
LD A, (HL)      ; A <- memory[HL]
LD (HL), B      ; Memory[HL] <- B
```

### Bit Addressing
Used by bit set, reset, and test instructions.
Three bits in the opcode specify which of the eight bits to manipulate, while the operand is addressed via register, register indirect, or indexed modes.

```asm
BIT 3, A        ; Test bit 3 of A
SET 7, (HL)     ; Set bit 7 of memory[HL]
```

## 6.5 Instruction Set
### 6.5.1 Data Transfer
Data transfer instructions move data between registers, memory, and I/O ports.

```asm
; Register to register
LD A, B           ; A <- B
LD H, L           ; H <- L

; Immediate to register
LD A, 0x42        ; A <- 0x42
LD HL, 0x4000     ; HL <- 0x4000

; Register to memory
LD (HL), A        ; memory[HL] <- A
LD (0x4000), A    ; memory[0x4000] <- A

; Memory to register
LD A, (HL)        ; A <- memory[HL]
LD A, (0x4000)    ; A <- memory[0x4000]

; Stack
PUSH BC           ; Push BC onto stack (SP -= 2)
POP HL            ; Pop stack into HL (SP += 2)

; Exchange
EX DE, HL         ; Swap DE <-> HL
EX AF, AF'        ; Swap A,F <-> A',F'
EXX               ; Swap BC,DE,HL <-> BC',DE',HL'
```

### 6.5.2 Arithmetic
```asm
; 8-bit
ADD A, B          ; A <- A + B
ADD A, 0x10       ; A <- A + 0x10
ADC A, B          ; A <- A + B + Carry
SUB B             ; A <- A - B
SBC A, B          ; A <- A - B - Carry
INC A             ; A <- A + 1 (Carry not affected)
DEC B             ; B <- B - 1 (Carry not affected)

; 16-bit
ADD HL, BC        ; HL <- HL + BC
ADC HL, DE        ; HL <- HL + DE + Carry
SBC HL, DE        ; HL <- HL - DE - Carry
INC HL            ; HL <- HL + 1
DEC DE            ; DE <- DE - 1
```

### 6.5.3 Logic
```asm
AND B             ; A <- A AND B  (P/V = parity)
OR C              ; A <- A OR  C
XOR D             ; A <- A XOR D
CP E              ; Flags <- (A - E), A unchanged
CPL               ; A <- NOT A  (complement)
NEG               ; A <- 0 - A  (two's complement negate)
```

### 6.5.4 Bit Manipulation
```asm
BIT 3, A          ; Test bit 3 of A  -> sets Z flag
SET 7, B          ; Set bit 7 of B to 1
RES 0, C          ; Reset bit 0 of C to 0

; Rotate and shift
RLCA              ; Rotate A left  (bit 7 -> Carry -> bit 0)
RRCA              ; Rotate A right (bit 0 -> Carry -> bit 7)
RLA               ; Rotate A left  through Carry
RRA               ; Rotate A right through Carry
RLC r             ; Rotate register r left
RRC r             ; Rotate register r right
SLA r             ; Shift r left  arithmetic (LSB <- 0)
SRA r             ; Shift r right arithmetic (MSB preserved)
SRL r             ; Shift r right logical    (MSB <- 0)
RL r              ; Rotate register r left through Carry
RR r              ; Rotate register r right through Carry
RLD               ; Rotate left digit: high nibble of (HL) <-> low nibble of A
RRD               ; Rotate right digit: low nibble of A <-> high nibble of (HL)
```

### 6.5.5 Control Flow
```asm
; Unconditional
JP 0x0100         ; Jump to 0x0100
JR LABEL          ; Relative jump (-128 to +127 bytes)
DJNZ LABEL        ; B--; jump if B != 0 (loop counter)

; Conditional jumps (cc = Z, NZ, C, NC, PE, PO, M, P)
JP Z, LABEL       ; Jump if Zero flag set
JP NZ, LABEL      ; Jump if Zero flag clear
JP C, LABEL       ; Jump if Carry set
JP NC, LABEL      ; Jump if Carry clear
JR Z, LABEL       ; Relative jump if Zero
JR NZ, LABEL      ; Relative jump if Zero clear
JR C, LABEL       ; Relative jump if Carry
JR NC, LABEL      ; Relative jump if Carry clear

; Restart (Modified Page Zero)
RST 0x08          ; Call subroutine at 0x0008
```

### 6.5.6 Subroutines and the Stack
The Z80 uses a **descending stack**: it grows toward lower addresses.
`SP` always points to the last byte pushed.

`CALL` pushes the return address onto the stack and jumps to the subroutine.
`RET` pops the return address and jumps back.

```asm
    LD SP, 0xFFFF   ; Initialize stack pointer to top of RAM

MAIN:
    LD A, 0x41      ; 'A' in ASCII
    CALL PRINT      ; Call subroutine
    HALT

PRINT:
    OUT (0x00), A   ; Send character to UART TX
    RET             ; Return to caller
```

Conditional calls and returns are also supported:

```asm
CALL Z,  LABEL    ; Call if Zero flag set
CALL NZ, LABEL    ; Call if Zero flag clear
RET Z             ; Return if Zero flag set
RET C             ; Return if Carry set
```

### 6.5.7 Block Instructions
Block instructions operate on ranges of memory or I/O ports in a single instruction, replacing multi-instruction loops.

```asm
LDIR    ; Copy (HL)->(DE), HL++, DE++, BC--; repeat until BC=0
LDDR    ; Same but HL--, DE-- (copy backward)
CPIR    ; Compare A with (HL), HL++, BC--; stop on match or BC=0
CPDR    ; Same but HL-- (search backward)
INIR    ; Input from port C to (HL), HL++, B--; repeat until B=0
OTIR    ; Output (HL) to port C, HL++, B--; repeat until B=0
LDI     ; Copy (HL)->(DE), HL++, DE++, BC-- (single step, no repeat)
LDD     ; Copy (HL)->(DE), HL--, DE--, BC-- (single step, no repeat)
CPI     ; Compare A with (HL), HL++, BC-- (single step, no repeat)
CPD     ; Compare A with (HL), HL--, BC-- (single step, no repeat)
INI     ; Input from port C to (HL), HL++, B-- (single step)
IND     ; Input from port C to (HL), HL--, B-- (single step)
INDR    ; Same as IND but repeat until B=0
OUTI    ; Output (HL) to port C, HL++, B-- (single step)
OUTD    ; Output (HL) to port C, HL--, B-- (single step)
```

### 6.5.8 I/O Instructions
The Z80 has a dedicated I/O space of 256 ports, accessed with `IN` and `OUT` instructions, separate from the memory address space.

```asm
OUT (0x00), A     ; Output A to I/O port 0x00
IN A, (0x01)      ; Read I/O port 0x01 into A
OUT (C), B        ; Output B to port number in C
IN B, (C)         ; Read port in C into B
```

> On the Z80DevBoard, port `0x00` is the **UART TX** virtual peripheral.
> Writing to it sends a character to the USB serial console.

### 6.5.9 Interrupts
The Z80 supports two types of interrupt: **maskable** (`/INT`) and **non-maskable** (`/NMI`).

```asm
EI          ; Enable maskable interrupts
DI          ; Disable maskable interrupts
```

**Non-maskable interrupts** (`/NMI`) are always serviced, regardless of the `EI`/`DI` state.
The CPU saves the current PC on the stack and jumps to the fixed address `0x0066`.

**Maskable interrupts** (`/INT`) are only serviced when interrupts are enabled (`EI`).

The Z80 supports three interrupt modes:

| Mode | Instruction | Behaviour |
|---|---|---|
| 0 | `IM 0` | External device places an opcode on the data bus |
| 1 | `IM 1` | CPU always jumps to fixed address `0x0038` |
| 2 | `IM 2` | Vectored: address = `(I << 8) \| (data bus byte)` |

**IM 1** is the simplest and recommended for beginners:
```asm
    LD SP, 0xFFFF
    IM 1            ; Use interrupt mode 1
    EI              ; Enable maskable interrupts
    ; ... main code ...
    HALT

    ORG 0x0038      ; IM 1 interrupt service routine
ISR:
    ; Handle interrupt here
    EI              ; Re-enable interrupts
    RETI            ; Return from interrupt (restores IFF flags)
```

Return instructions for interrupts:
```asm
RETI    ; Return from maskable interrupt (signals I/O devices)
RETN    ; Return from non-maskable interrupt (restores IFF1 from IFF2)
```

### 6.5.10 Miscellaneous
```asm
NOP     ; No operation (4 cycles)
HALT    ; Stop execution, wait for interrupt
SCF     ; Set Carry flag
CCF     ; Complement Carry flag
DAA     ; Decimal adjust A after BCD arithmetic
```

## 6.6 Assembler Directives
Assembler directives are not Z80 instructions, they are commands to the assembler itself, controlling how the source code is translated into machine code.

Remember that the assembler directives may be different between different assemblers.

|Directive|Example|Description|
|---|---|---|
|`ORG`|`ORG 0x0000`|Set the address|
|`DEFB` / `DB`|`DEFB 0xFF, 0x00`|Emit one or more literal bytes|
|`DEFW` / `DW`|`DEFW 0x1234`|Emit a 16-bit word|
|`DEFS` / `DS`|`DEFS 16`|Reserve N zero-filled bytes|
|`DEFM` / `DM`|`DEFM "Hello"`|Emit a string as raw bytes|
|`EQU`|`UART_TX EQU 0x00`|Define a symbolic constant|
|`INCLUDE`|`INCLUDE "utils.asm"`|Include another source file|
|`END`|`END`|Mark the end of the source file|

## 6.7 Your First Program
### 6.7.1 Hello World
This program prints a greeting message over the UART, demonstrating basic data movement, the indirect addressing mode, and a simple loop with a string terminator.

```asm
ORG 0x0000

UART_TX EQU 0x00

START:
    LD HL, MSG          ; HL points to the start of the message

LOOP:
    LD A, (HL)          ; Load the next character into A
    OR A                ; Check if A is zero (string terminator)
    JR Z, DONE          ; If zero, the string is finished

    OUT (UART_TX), A    ; Send the character to the UART
    INC HL              ; Move to the next character
    JR LOOP             ; Repeat

DONE:
    HALT                ; Stop execution

MSG:    DEFM "Hello, World!", 0x0D, 0x0A, 0x00

    END
```

The program uses `HL` as a pointer that walks through the `MSG` string, one byte at a time.

Each character is loaded into `A` with `LD A, (HL)`, this is register indirect addressing: the address to read from is held inside `HL`, not written literally in the instruction.

The `OR A` instruction is a common check: ORing a register with itself doesn't change its value, but it updates the flags based on that value.
If `A` is `0x00`, the *Zero flag* is set, and `JR Z, DONE` jumps to the end of the program.

If the character isn't the terminator, it's sent to the *UART* with `OUT (UART_TX), A`, `HL` is incremented to point at the next character, and the loop repeats with `JR LOOP`.

The message itself is defined with `DEFM`, which emits each character as a raw byte, followed by `0x0D` (carriage return), `0x0A` (line feed), and `0x00` (the null terminator for the loop check).

### 6.7.2 Bubble Sort
This program sorts an array of bytes in ascending order using the bubble sort algorithm.
It repeatedly scans the array, swapping adjacent elements that are out of order, until a full pass produces no swaps.

```asm
ORG 0x0000

START:
    LD HL, TABLE          ; HL <- address of the first element
    LD A, TABLE_END - TABLE
    DEC A                 ; A <- number of comparisons per pass
    LD B, A

PASS:
    LD C, 0               ; C <- swap flag, 0 = no swaps this pass
    LD D, B               ; D <- save comparison count for this pass
    LD HL, TABLE          ; Reset HL to the start of the array

COMPARE:
    LD A, (HL)            ; A <- current element
    INC HL                ; HL -> next element
    CP (HL)               ; Compare A with next element

    JP C, NEXT            ; If A < next element, already in order

    CALL SWAP             ; Otherwise, swap the two elements
    LD C, 1               ; Mark that a swap occurred

NEXT:
    DEC D                 ; One comparison done
    JP NZ, COMPARE        ; Repeat until D = 0

    LD A, C
    OR A                  ; Check if any swap occurred this pass
    JP NZ, PASS           ; If yes, do another pass

    HALT                  ; Array is sorted

; --- Subroutine: swap (HL) with the element before it ---
SWAP:
    LD C, (HL)            ; C <- next element
    LD (HL), A            ; next element <- A (current element)
    DEC HL
    LD (HL), C            ; current element <- C (next element)
    INC HL
    RET

TABLE:      DEFB 10, 9, 8, 7, 6, 5, 4, 3, 2, 1
TABLE_END:

END
```

The algorithm performs repeated **passes** over the array.
In each pass, `HL` walks through the array comparing each element with the one immediately after it.
If the current element is greater than the next one, detected with `CP (HL)` (which sets the *Carry flag* if `A < (HL)`), the two are out of order and `SWAP` exchanges them.

The flag `C` tracks whether any swap happened during the current pass.
If a full pass completes with `C = 0`, the array is fully sorted and the program halts.
Otherwise, `PASS` resets `HL` and the comparison counter `D`, and runs another pass.

The number of comparisons per pass is computed as `TABLE_END - TABLE`, the size of the array in bytes, minus one, since comparing the last element with anything beyond it is meaningless.
Using labels instead of a hardcoded constant means the table size updates automatically if the array changes.

The `SWAP` subroutine exchanges `(HL)` with the byte before it, using `C` as a temporary register.
Note that `A` still holds the original value of `(HL-1)` at this point, which is why `LD (HL), A` writes it into the new position.

### 6.7.3 Selection Sort
This program sorts an array of bytes in ascending order using the selection sort algorithm.
For each position in the array, it finds the smallest element in the remaining unsorted portion and swaps it into place.

```asm
ORG 0x0000

START:
    LD SP, 0x01FF           ; Initialize stack pointer

    LD A, TABLE_END - TABLE
    DEC A                   ; A <- array length - 1
    LD B, A                 ; B <- outer loop counter

    LD IX, TABLE            ; IX <- outer pointer

OUTER:
    PUSH IX
    POP HL                  ; HL <- minimum pointer (starts at outer position)

    PUSH IX
    POP IY
    INC IY                  ; IY <- inner pointer (IX + 1)

    LD A, B                 ; Inner iterations = remaining outer passes
    PUSH BC                 ; Save outer counter
    LD B, A                 ; B <- inner loop counter

INNER:
    LD A, (IY+0)            ; A <- inner element
    CP (HL)                 ; Compare with current minimum
    JP NC, NEXT             ; If A >= minimum, skip

    PUSH IY
    POP HL                  ; HL <- new minimum pointer

NEXT:
    INC IY                  ; Advance inner pointer
    DJNZ INNER              ; Repeat inner loop

    ; Swap outer element with minimum
    LD A, (IX+0)            ; A <- outer element
    LD E, (HL)              ; E <- minimum element
    LD (IX+0), E            ; outer position <- minimum
    LD (HL), A              ; minimum position <- outer element

    POP BC                  ; Restore outer counter
    INC IX                  ; Advance outer pointer
    DJNZ OUTER              ; Repeat outer loop

    HALT                    ; Array is sorted

TABLE:      DEFB 10, 9, 8, 7, 6, 5, 4, 3, 2, 1
TABLE_END:

END
```

The algorithm uses two nested loops.
The **outer loop** advances a pointer `IX` through the array from the first element to the second-to-last.
At each position, `HL` is set to point to the current outer element, which is initially assumed to be the minimum of the unsorted portion.

The **inner loop** scans from the current outer position to the end of the array.
For each element, `CP (HL)` compares it against the current minimum: if a smaller value is found, `HL` is updated to point to it.
When the inner loop completes, `HL` holds the address of the true minimum of the unsorted portion.

The minimum is then swapped into the outer position using `IX` and `HL`: the outer element goes to the minimum's address and the minimum goes to the outer position.
After the swap, `IX` advances by one and `DJNZ` decrements `B`, repeating the outer loop until all positions have been processed.

The `IX` index register is used here instead of `HL` for the outer pointer, freeing `HL` to track the minimum position throughout the inner loop.

### 6.7.4 Interrupt-Driven Input
This program waits for characters sent by the host over the UART and echoes them back, using interrupt mode 1.
Instead of continuously polling the UART status in a loop, the Z80 halts and resumes only when the RP2040 asserts /INT, signaling that a character is available.

```asm
ORG 0x0000

UART_RX EQU 0x01            ; UART RX port
UART_TX EQU 0x00            ; UART TX port

START:
    LD SP, 0x01FF           ; Initialize stack pointer
    IM 1                    ; Set interrupt mode 1
    EI                      ; Enable maskable interrupts

WAIT:
    HALT                    ; Wait for interrupt
    JP WAIT                 ; Loop back after returning from ISR

; --- Interrupt Service Routine (IM 1) ---
ORG 0x0038

ISR:
    IN A, (UART_RX)         ; Read character from UART RX
    OUT (UART_TX), A        ; Echo it back to UART TX
    EI                      ; Re-enable interrupts
    RETI                    ; Return from interrupt

END
```

After initialising the stack and setting interrupt mode 1 with `IM 1`, the program enables maskable interrupts with `EI` and enters a `HALT` instruction.
`HALT` suspends execution and puts the Z80 into a low-power wait state: the CPU stops fetching instructions, but remains fully operational and ready to respond to interrupts.

When the host sends a character over the UART, the RP2040 asserts the `/INT` signal.
The Z80 detects the interrupt, pushes the current `PC` (Program Counter) onto the stack, disables interrupts, and jumps to the fixed address `0x0038`: the **IM 1 interrupt vector**.

The ISR reads the incoming character from the UART RX port with `IN A, (UART_RX)` and immediately sends it back with `OUT (UART_TX), A`.
`EI` re-enables interrupts before `RETI` returns, restoring the program counter from the stack and resuming execution at `HALT`.

Note that **interrupts are automatically disabled** when the Z80 enters an ISR, this prevents a second interrupt from interrupting the handler itself.
`EI` before `RETI` re-enables them, but the effect is delayed by one instruction, so RETI always executes before any new interrupt is serviced.

## 6.8 Recommended Resources
### Official Documentation
- [Z80 CPU User Manual](https://www.zilog.com/docs/z80/um0080.pdf) - Zilog Inc. (official reference, freely available as PDF at zilog.com)
- [Z84C00 Product Specification](https://www.zilog.com/docs/z80/ps0178.pdf) - Zilog Inc. (datasheet for the CMOS variant used on this board)

### Books
- [Z80 Assembly Language Programming](https://acpc.me/ACME/LITTERATURE/LIVRES/%5BENG%5DENGLISH/OSBORNE/Z80_Assembly_Language_programming(Lance_LEVENTHAL_1979).pdf) - Lance A. Leventhal (classic textbook, covers the instruction set in depth with practical examples)
- [The Undocumented Z80 Documented](http://www.z80.info/zip/z80-documented.pdf) - Sean Young (covers undocumented opcodes, flag behavior edge cases, and internal CPU behavior not described in the official manual)

### Online Resources
- [ClrHome Z80 Reference](https://clrhome.org/table/) - (interactive opcode table with cycle counts and flag effects)

### Tools
- [z80asm](https://www.nongnu.org/z80asm/) - assembler used in the examples in this chapter
- [Z80 Simulator IDE](https://www.oshonsoft.com/z80.php) - a cool simulator by *OshonSoft* that can be used to test the programs

---

<div>
  <p align="left">
    <em>
      <b>
        <a href="/docs/advanced.md">
          ← Back
        </a>
      </b>
    </em>
  </p>

  <p align="right">
    <em>
      <b>
        <a href="/docs/technicalInfo.md">
          Next Section →
        </a>
      </b>
    </em>
  </p>
</div>

---

<p align="center">
    <em>Open source, Open Education - Z80DevBoard</em>
</p>

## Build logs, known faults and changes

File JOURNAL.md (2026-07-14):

---
title: "Z80DevBoard"
author: "Gianluca Rainis"
description: "An advanced development board for the Z80 microprocessor, powered by an RP2040."
created_at: "2025-11-27"
---

# November 27th 2025: Project start
First commit.
Added the Z80 (Z84C00) to the schematic, the RAM, the first LEDs and some buttons.
Started thinking about how the Z80 would interact with a modern companion chip for program loading and debugging.

**Total time spent: ~3h**

# November 28th-29th 2025: Schematic progresses
Added the RP2040 and the flash memory.
Designed the first version of the LED matrix to visualize live bus activity.
Added shift registers (74HC595, 74HC165, SN74LVC245APW) to handle the large number of signals.
Started the footprints and the connections between components.

**Total time spent: ~12h**

# December 1st-5th 2025: First PCB layout
Finished the schematic connections and moved to the PCB layout.
Routed all connections on 2 layers, defined the board borders, added the Z80DevBoard logo and graphics to the silkscreen, and generated the first Gerber files.

Added component values to the silkscreen, button labels, author and GitHub info to the back.
Updated the README with the component list.

**Total time spent: ~10h**

# December 15th-16th 2025: License update
Updated the USB-C connector.
Fixed the board borders.
Updated the LICENSE to CERN OHL W.
Updated the README and regenerated the Gerber files.

**Total time spent: ~2h**

# December 19th 2025: Added two new layers
Upgraded the board from 2 to 4 layers.
Adding dedicated Vcc + 3v3, and GND layers.
This simplify power distribution and reduced the noise.

Fixed the oscillators, the crystal, and the connections between the RP2040 and the Flash.

**Total time spent: ~6h**

# December 21st-24th 2025: Clock, Debouncer and other generic fixes
Added the manual clock button for the Z80 and fixed all the components.
Replaced the old Z80 crystal oscillator with a new automatic slow clock generator, making it easier to switch between manual and automatic clocking.

Added a hardware debouncer to clean up button signals.
Updated the SWD and SCLK debug pins.
Fixed the RP2040 crystal capacitors, the data bus clock, and the GND layer.
Changed the capacitor footprints and updated the back silkscreen.
Fixed the size of the board.

**Total time spent: ~14h**

# February 6th 2026: Second SRAM
Added a second SRAM chip, doubling the available memory from 32KB to 64KB (the maximum amount the Z80 can directly index).
Fixed the connections to the first RAM and routed the connections to the second one.

**Total time spent: ~7h**

# March 1st-4th 2026: New LED matrix
Remade the LED matrix.
Added two 74HCT574 as output buffers and one 74HC00 NAND to solve signal issues, causing incorrect LED readings.
Finished all the address LED matrix connections and optimized the board space.

Fixed several DRC rule violations, updated the CERN license (CERN OHL S), regenerated the Gerber files.

**Total time spent: ~12h**

# March 5th 2026: Expansion Pins
Added two pin socket headers to support expansion boards and external devices.
Prepared the RP2040 pins for the socket connections.

**Total time spent: ~8h**

# March 10th 2026: Expansion pins completed
Finished the connections between the expansion pins and the Z80.
The board now exposes the Z80 bus signals on two pin headers, making it possible to connect external devices and future expansion boards, allowing also support to more advanced projects.

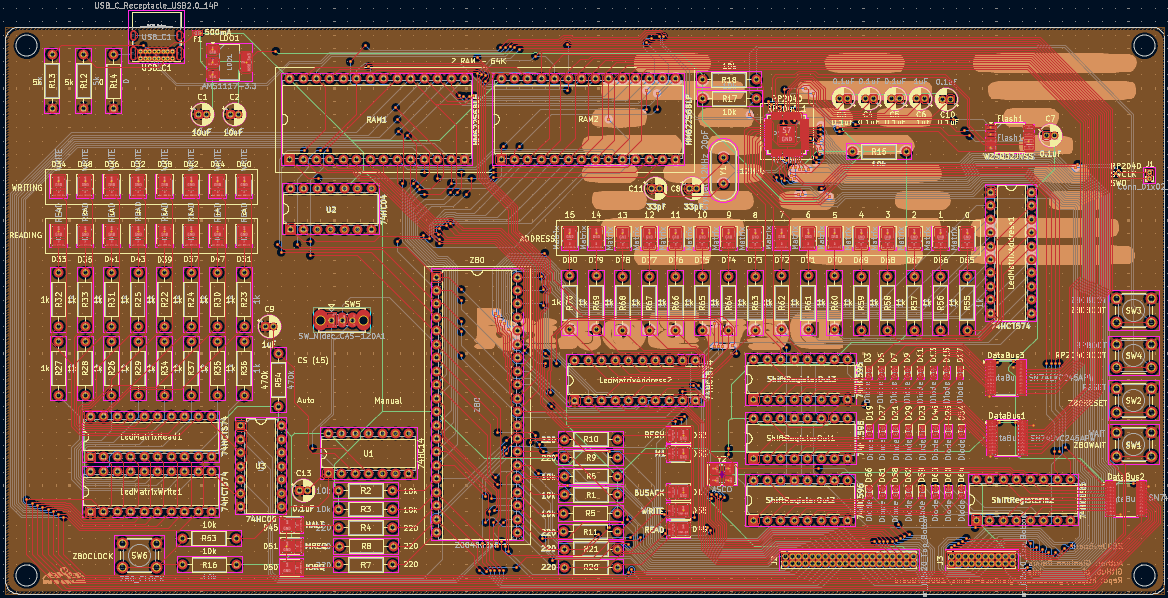
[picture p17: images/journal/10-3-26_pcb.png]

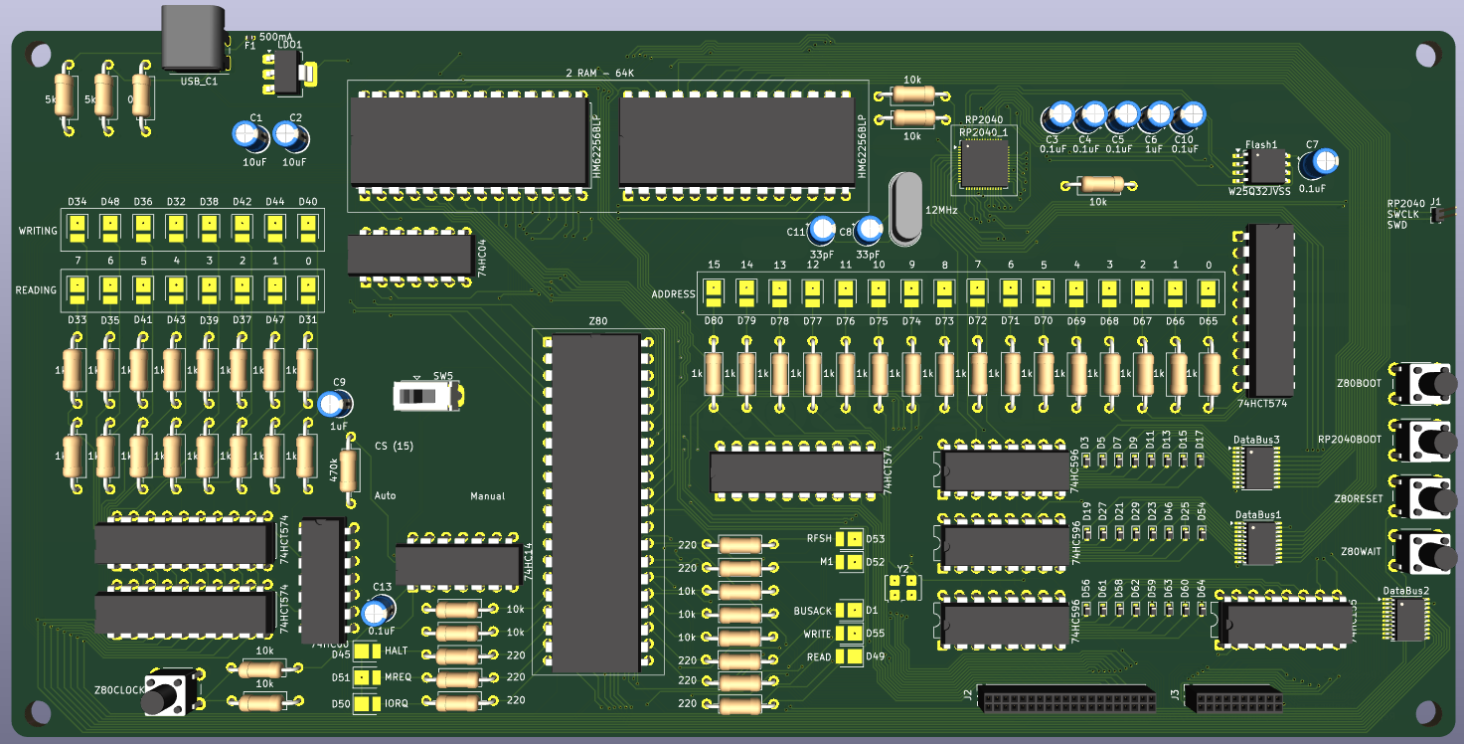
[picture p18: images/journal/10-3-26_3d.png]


**Total time spent: ~2h**

# March 11th 2026: Expansion pin labels and silkscreen
Added pin name labels to the expansion connector in the front silkscreen. Fixed several small details on the PCB.

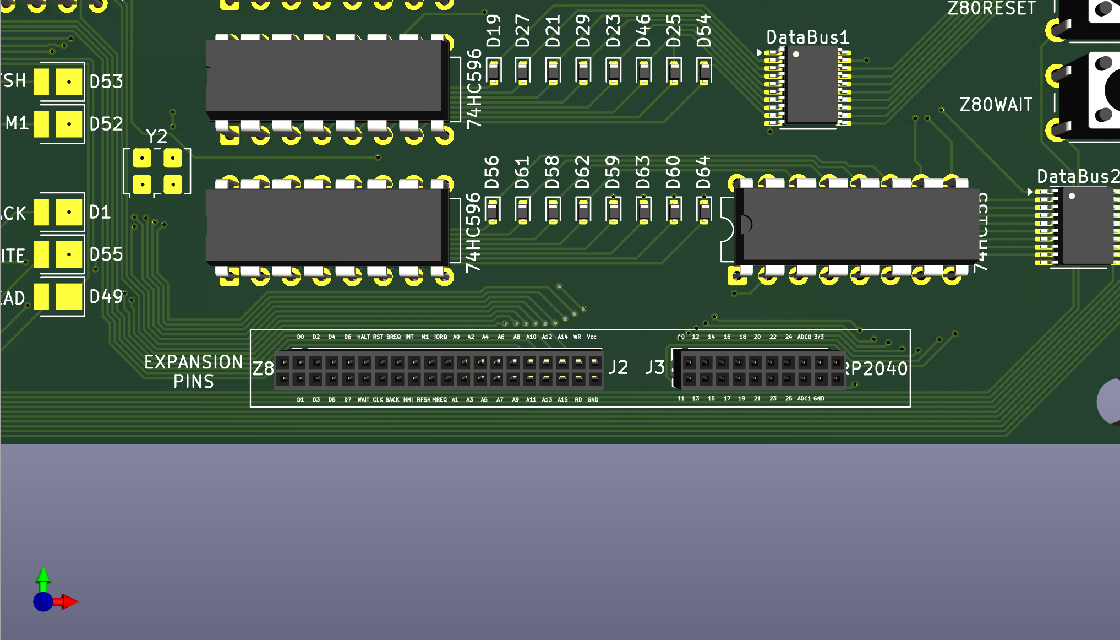
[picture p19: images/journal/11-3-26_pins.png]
expansion_pins


**Total time spent: ~1h**

# March 24th-26th 2026: Clock fix and generic updates
Fixed the RP2040 crystal load capacitors from 33pF to 15pF, following the RP2040 datasheet.
Added 27.4Ω resistors on the XIN and XOUT pins, as recommended by the official documentation.
Updated the bus clock frequency from 2MHz to 8MHz.
Fixed some resistors values, now the board hasn't resistors of 220 ohm anymore.
Added Z80 pin labels to the silkscreen.
Fixed expansion pin labels that were hidden under traces.
Added debouncers for the Reset and Wait buttons.
Added a TXS0102DCT 2-bit bidirectional level shifter between the RP2040 and the Z80 to handle BUSREQ and BUSACK.

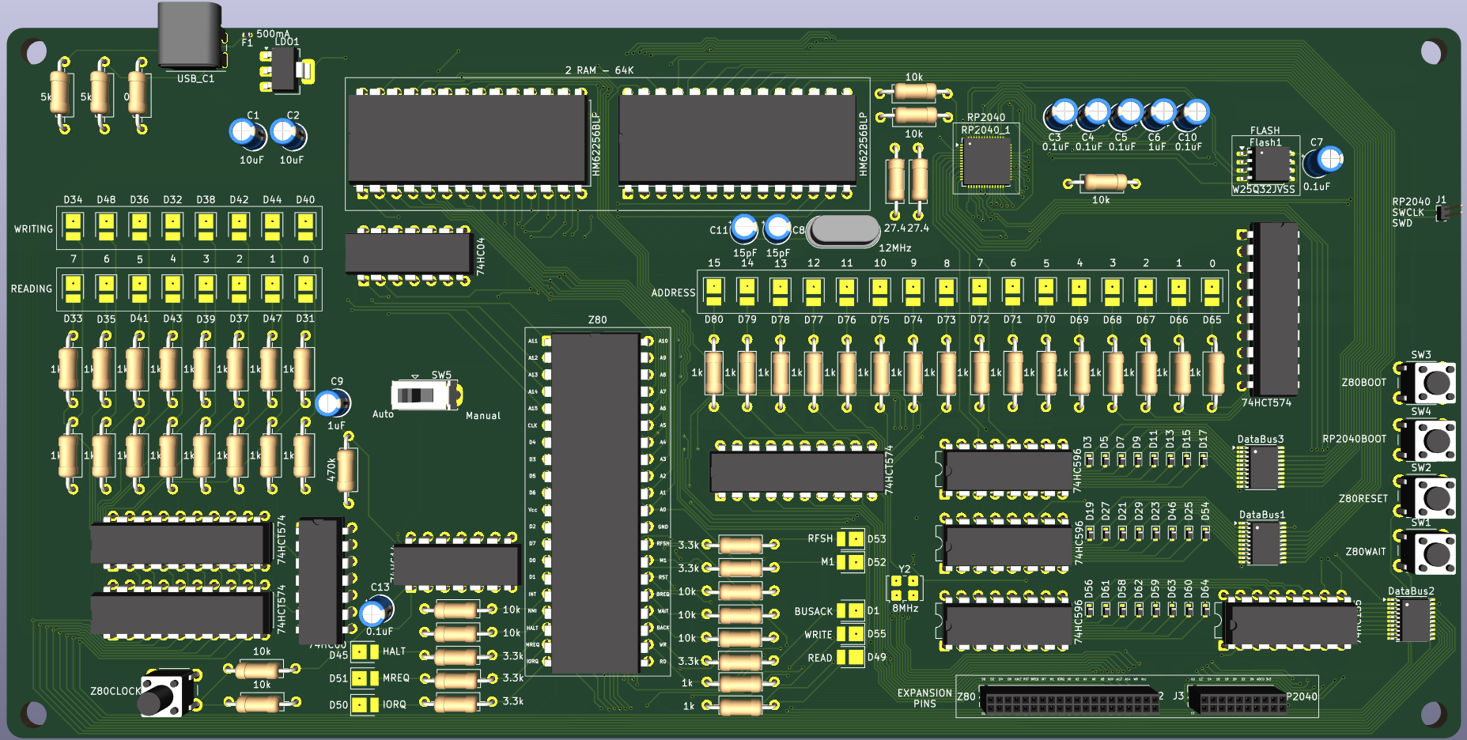
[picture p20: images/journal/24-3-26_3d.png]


**Total time spent: ~5h**

# March 30th 2026: Finished the TXS0102DCT connections
Added the Hack Club flag to the back silkscreen and some fun phrases to the front.
Created a custom footprint for the manual clock switch.
Fixed capacitor sizes and the fuse footprint.

Finished the connections between the TXS0102DCT, the RP2040, and the Z80.

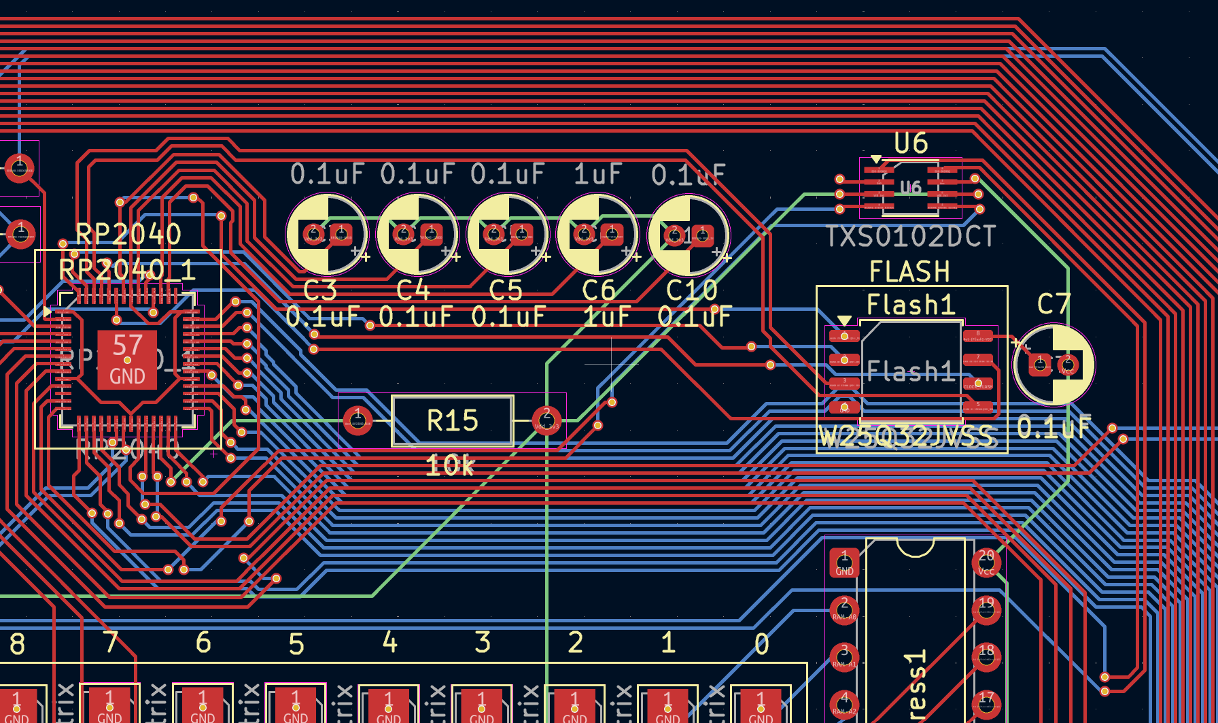
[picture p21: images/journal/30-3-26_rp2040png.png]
rp2040_flash_txs0102dct


**Total time spent: ~2h**

# March 31st 2026: Fixed the size of the text, started the firmware and prepaded the gerber files
Set minimum text height/width to 0.8mm and minimum line thickness to 0.15mm.
Fixed the Z80 and expansion pin label boxes dimensions.
Rotated the expansion pin names.
Fixed the distance between the four buttons.
Fixed capacitor and switch footprints.

Made the Bill Of Materials (BOM).
Updated the USB-C connector footprint.
Replaced the TXS0102DCT with a TXS0104EPW (4 pins).

Started writing the first version of the RP2040 firmware.

Prepared the STEP file.
Prepared the GERBER files.

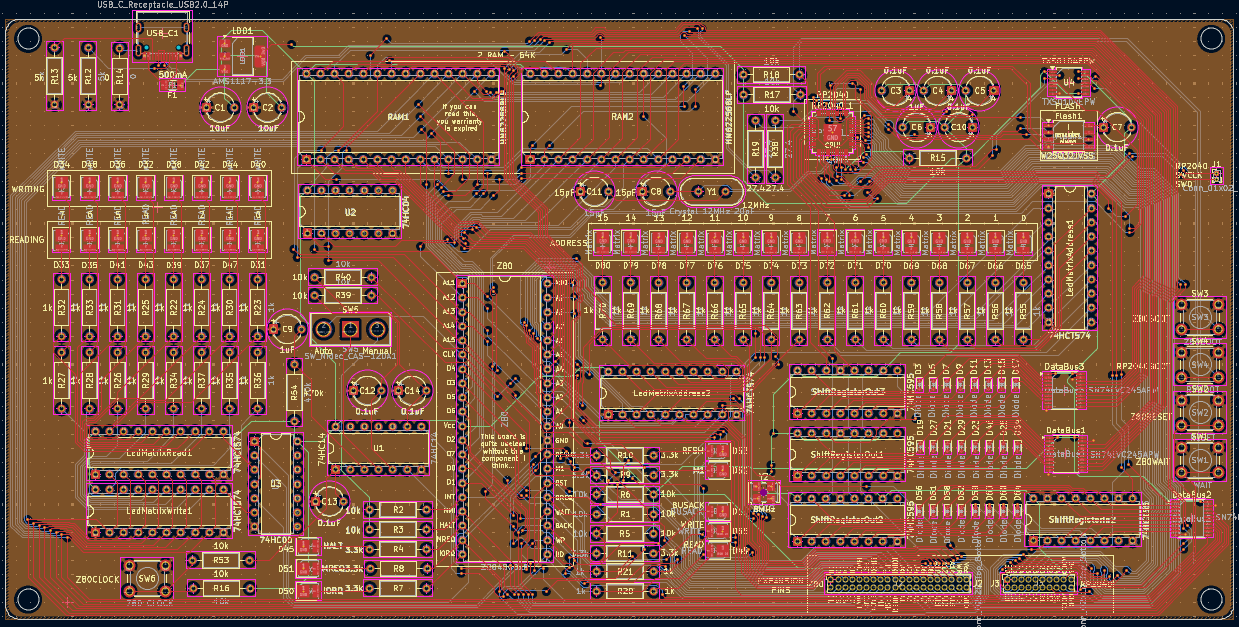
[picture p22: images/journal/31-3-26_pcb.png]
screenshot_pcb_no_drawings


**Total time spent: ~7h**

# April 13th-19th 2026: Hardware revision and PCB conclusions
Fixed the RP2040 power supply, the Flash alimentation, the firmware loading connections, and the crystal.
Updated the expansion pin footprints to be SMD.
Reconnected the RP2040, cleaned up all traces, and placed the remaining resistors and capacitors.

Finished all component placement and connections.
Updated the Gerber files.

**Total time spent: ~9h**

# April 21st 2026: PCBWay sponsorship
Updated the BOM prices and links.
Added the sponsor section to the README.

**[PCBWay](https://www.pcbway.com) became the official sponsor of the Z80DevBoard project!**

screenshot_pcb

pcbway (https://www.pcbway.com)

**Total time spent: ~5h**

# April 27th 2026: First firmware version
Wrote the firmware functions to access the RAM and the Flash from the RP2040.
Compiled the project successfully for the first time.

**Total time spent: ~3h**

# May 5th-8th 2026: Started the official documentation
Created the file structure for the official documentation.
Added navigation between pages.
Wrote the introduction.

**Total time spent: ~6h**

# May 11th-14th 2026: Hardware architecture and Quickstart guide
Finished the Z80 and RP2040 pinout chapters, including a full pinout scheme for the RP2040.
Wrote the Z80 and RP2040 expansion pins chapters and the SWD connector chapter.

Started the quickstart guide: wrote the first chapters covering board setup, loading a program, running it, using the manual clock, and reading the LED matrices.

Added an advanced guide structure with chapter titles.

**Total time spent: ~10h**

# May 19th-26th 2026: Quickstart, Advanced guide and serial communication
Finished the quickstart guide and wrote the "Flashing the firmware" chapter for the advanced guide.
Wrote the expansion board and "developing an expansion board" chapters.

Added serial communication support to the firmware.
Wrote the serial communication chapter in the documentation.

**Total time spent: ~7h**

# May 28th-29th 2026: Z80 assembly documentation
Started the Z80 assembly chapter.
Wrote the introduction to Z80 assembly, the Z80 register set chapter, and the flag register chapter.

**Total time spent: ~4h**

# June 7th 2026: Addressing modes chapter, changelog and journal
Wrote the addressing modes chapter for the Z80 assembly guide.

Created the `CHANGELOG.md` file.
Created the `JOURNAL.md` file.

**Total time spent: ~2h**

# June 8th-30th: Wrote the documentation
Finished the full documentation for the Z80DevBoard, structured as a multi-chapter book designed for educational kits.

Finished the *Chapter 6 - Z80 Assembly Programming*.
Wrote the *Chapter 7 - Schematics & KiCad Reference*.
Wrote the *Chapter 8 - Conclusions*.

Added Chapter *5.3 Writing Custom RP2040 Firmware*.

Implemented `uart.c` and `uart.h` for the firmware: *USB CDC* serial interface, *command parser*, `read` and `write` handlers.

**Total time spent: ~15h**

# July 9-13: Intensive Debugging and issue diagnostic
Created a pdf of the whole documentation in A5 format.

Added the option to force the execution of a command from serial.
Fixed several bugs in the firmware, like the somethimes never released BUSREQ.
Remade the whole send BUSREQ / await BUSACK / release BUSREQ logics.
Removed the force option from the serial commands.
Reorganized some comments.

Discovered some hardware issues after a lot of hardware debug, like the flash connected to 5V instead to 3v3, the wrong footprint for the switch and the misconnected manual clock for the Z80.
Also, most some of these with temporary connections and signal bypasses.

Created the `TODO.md` file to have a list of the fixes to do for the *Z80DevBoard v2.0.0*.

**Total time spent: ~20h**

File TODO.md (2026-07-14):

# TODO
Things to fix for the **Z80DevBoard *v2.0.0***

## Critical fixes
- [ ] Fix the Clock Switch footprint
- [ ] The flash must be connected to 3v3, not Vcc

## Hardware improvements
- [ ] RP2040 alimentation capacitors close to the RP2040's pins
- [ ] RP2040 USB resistors close to the RP2040's pins
- [ ] Add more than one via for the RP2040's GND
- [ ] Improve automatic clock generator
- [ ] Made the expansion pins socket footprint bigger
- [ ] Made the SWD and SWCLK pins footprint bigger
- [ ] Add a connection between a GPIO of the RP2040 and the CLK of the Z80

## Firmware improvements
- [ ] Add a log buffer to print all the previous logs once the board is connected (TO VERIFY SIZE OF THE BUFFER - RISK TOO BIG BUFFER OR BUFFER OVERFLOW)

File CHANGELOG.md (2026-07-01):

# Changelog
All notable changes to this project will be documented in this file.

## Unreleased
### Added
- Added the pdf file of the Schematics.
- Added the pdf file of the PCB Layout.
- Created a video presentation for the Official Firmware Demo.
- Added the help command in the firmware.

### Fixed

### Changed

### Removed

## v1.8.0 - 2026-07-01
### Added
- Wrote the whole documentation.
- Created the CHANGELOG file.
- Created the JOURNAL file.

### Changed
- Updated the firmware.
- Updated the README file.

## v1.7.0 - 2026-04-22
### Added
- Now the project is sponsorized by [PCBWay](https://www.pcbway.com/)!

### Fixed
- Fixed the alimentation of the RP2040.
- Fixed the footprints of the two pin extension's sockets.
- Fixed the size of the board.

## v1.6.0 - 2026-03-31
### Added
- Added two pin sockets for Expansion boards or more advanced progects.
- Added the names of the expansion pins.
- Added the names of the Z80 pins.
- Added the debouncer for the Reset and for the Wait buttons.
- Added a TXS0102DCT for the connections between the RP2040 and the Z80 BUSREQ and BUSACK.
- Added some graphics and funny phrases.

### Fixed
- Fixed the bus clock.
- Fixed some resistors.
- Fixed some capacitors values.
- Fixed the footprint of the fuse.
- Fixed the sizes of the Expansion pin's names and of the Z80 pin's names.

### Changed
- Made a custom footprint for the switch.
- Changed the footprint of the capacitors.

## v1.5.0 - 2026-03-04
### Added
- Added second SRAM to have 64Kb instead of 32Kb.
- Added 74HTC574 as buffers for the led matrix.
- Added one 74HC00.
- Added the components informations in the silkscreen.
- Updated the documentation.

### Fixed
- Optimized the space.
- Fixed some DRC rules violations.

### Changed
- Remade the led matrix.
- Updated the CERN license.

## v1.2.0 - 2025-12-24
### Added
- Added debouncer.
- Added the info about the leds on the front silkscreen.
- Made a new automatic slow clock generator for the Z80.

### Fixed
- Fixed the board size.
- Fixed SWD and SCLK pins.
- Fixed the crystal and the capacitors for the RP2040 clock.
- Fixed the data bus clock.
- Fixed some connections.

### Changed
- Updated the back silkscreen.
- Changed the capacitors footprint.
- Changed the switch (manual - auto clock selector).

### Removed
- Removed the old crystal for the Z80's clock.

## v1.0.0 - 2025-12-22
### Added
- Added the manual clock for the Z80.
- Added the SWCLK and SWD pins for debug.
- Added other 2 layers.
- Added the GND layer.
- Added the Vcc and 3v3 layer.

### Fixed
- Fixed all the clocks.
- Fixed the borders of the board.
- Fixed some connections.

## v0.9.0 (Pre-release) - 2025-12-05
### Added
- Added the connections on 2 layers.
- Added the graphics to the pcb.

### Fixed
- Fixed some connections.
- Fixed the pcb for the 3D view.

### Changed
- Finished all the scematics.
- Finished the pcb.

## v0.1.0 (Pre-release) - 2025-11-29
### Added
- Added the main components.
- Started the connections.
- Connected the Z80 to the RAM module.
- Created some led matrix to see the live activity of the Z80.
- Added some leds to see the bits the Z80 are writing or reading.
- Added the Wait and the Reset buttons.

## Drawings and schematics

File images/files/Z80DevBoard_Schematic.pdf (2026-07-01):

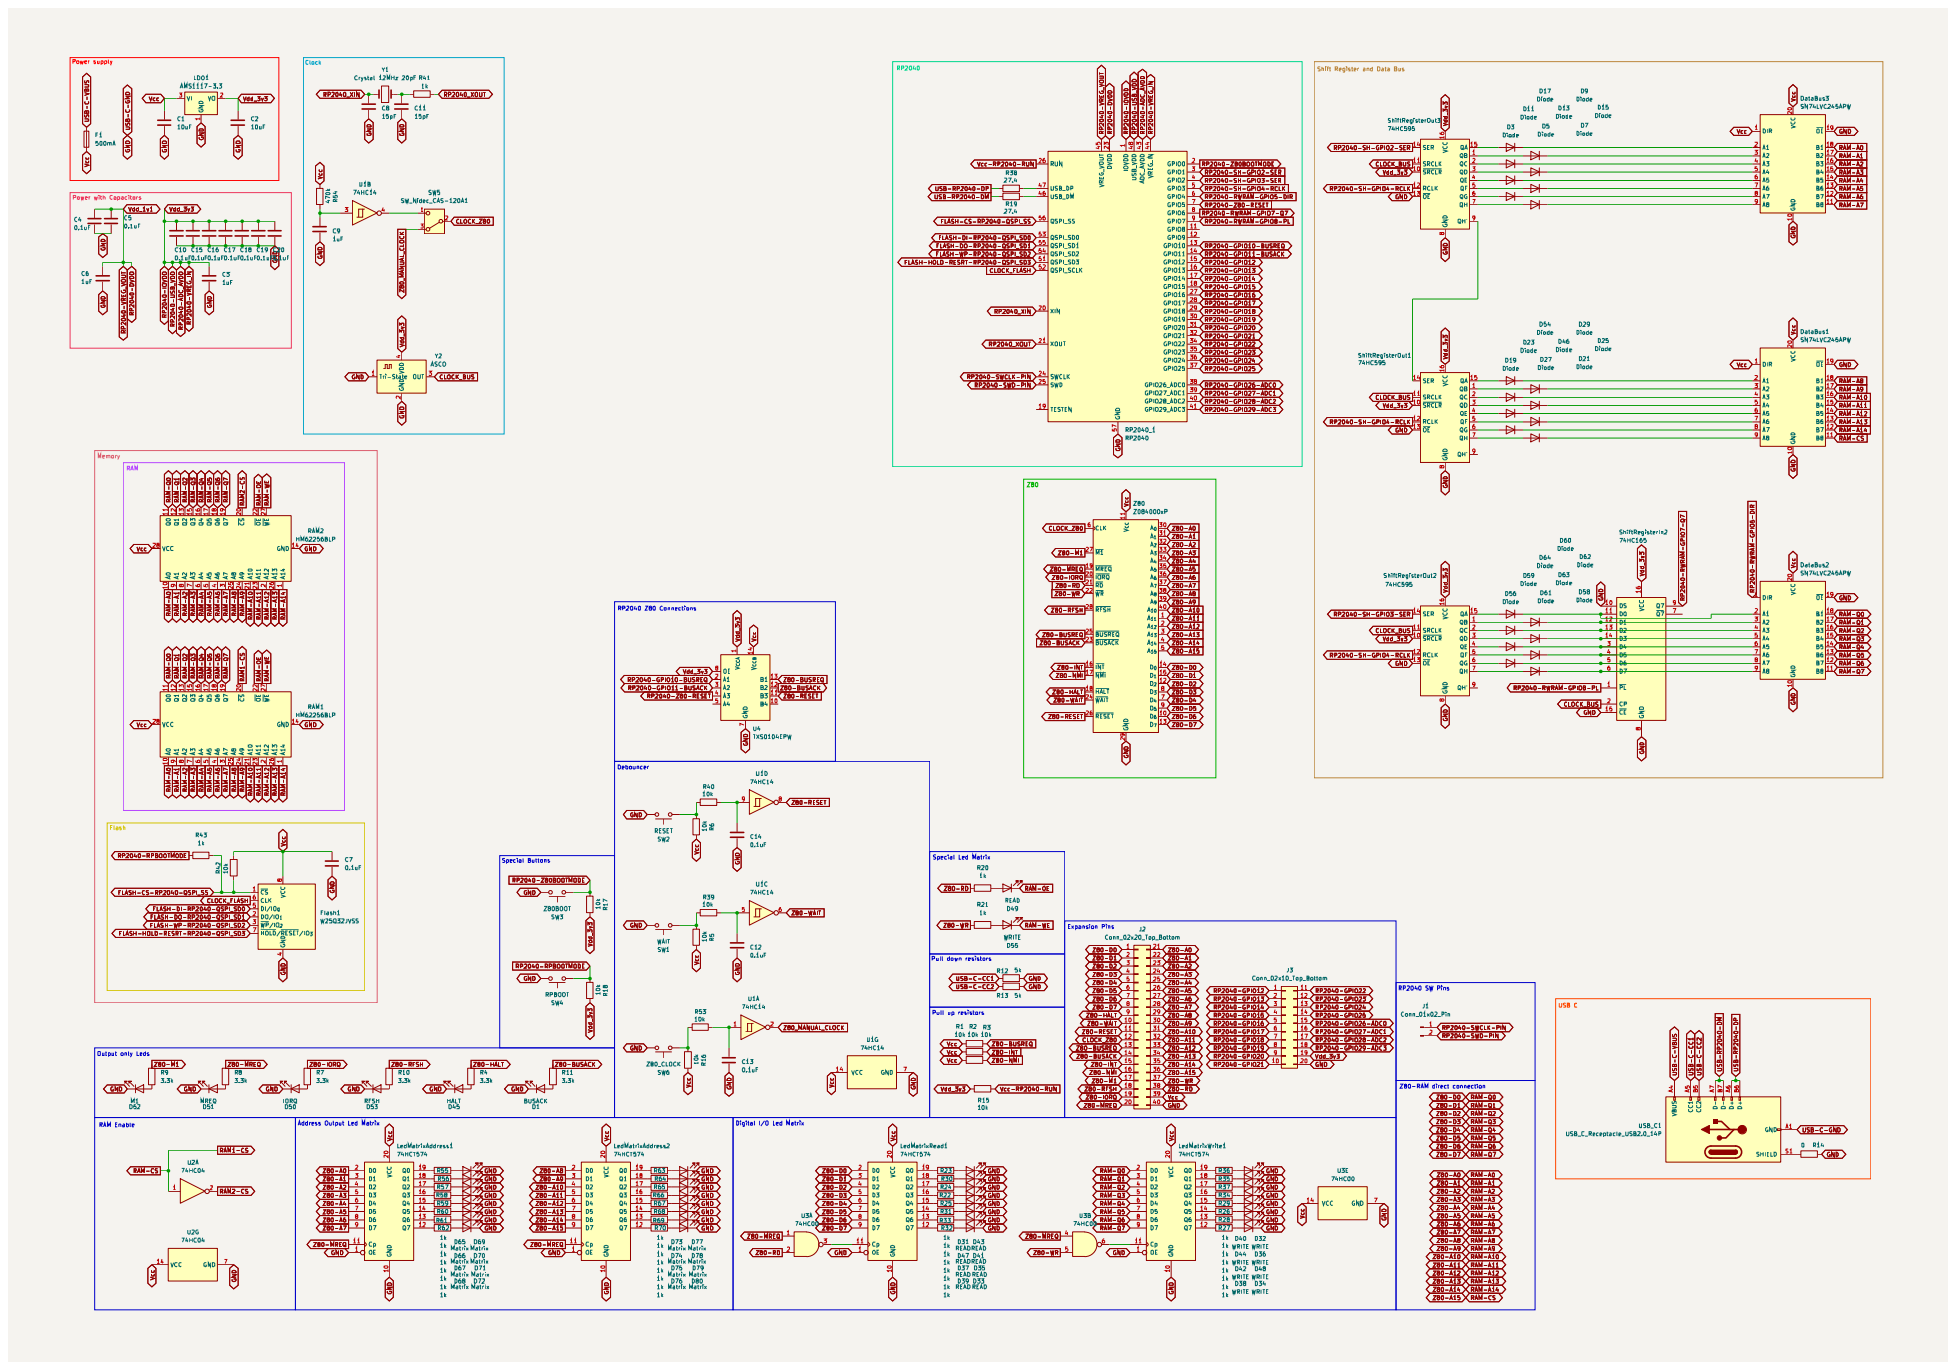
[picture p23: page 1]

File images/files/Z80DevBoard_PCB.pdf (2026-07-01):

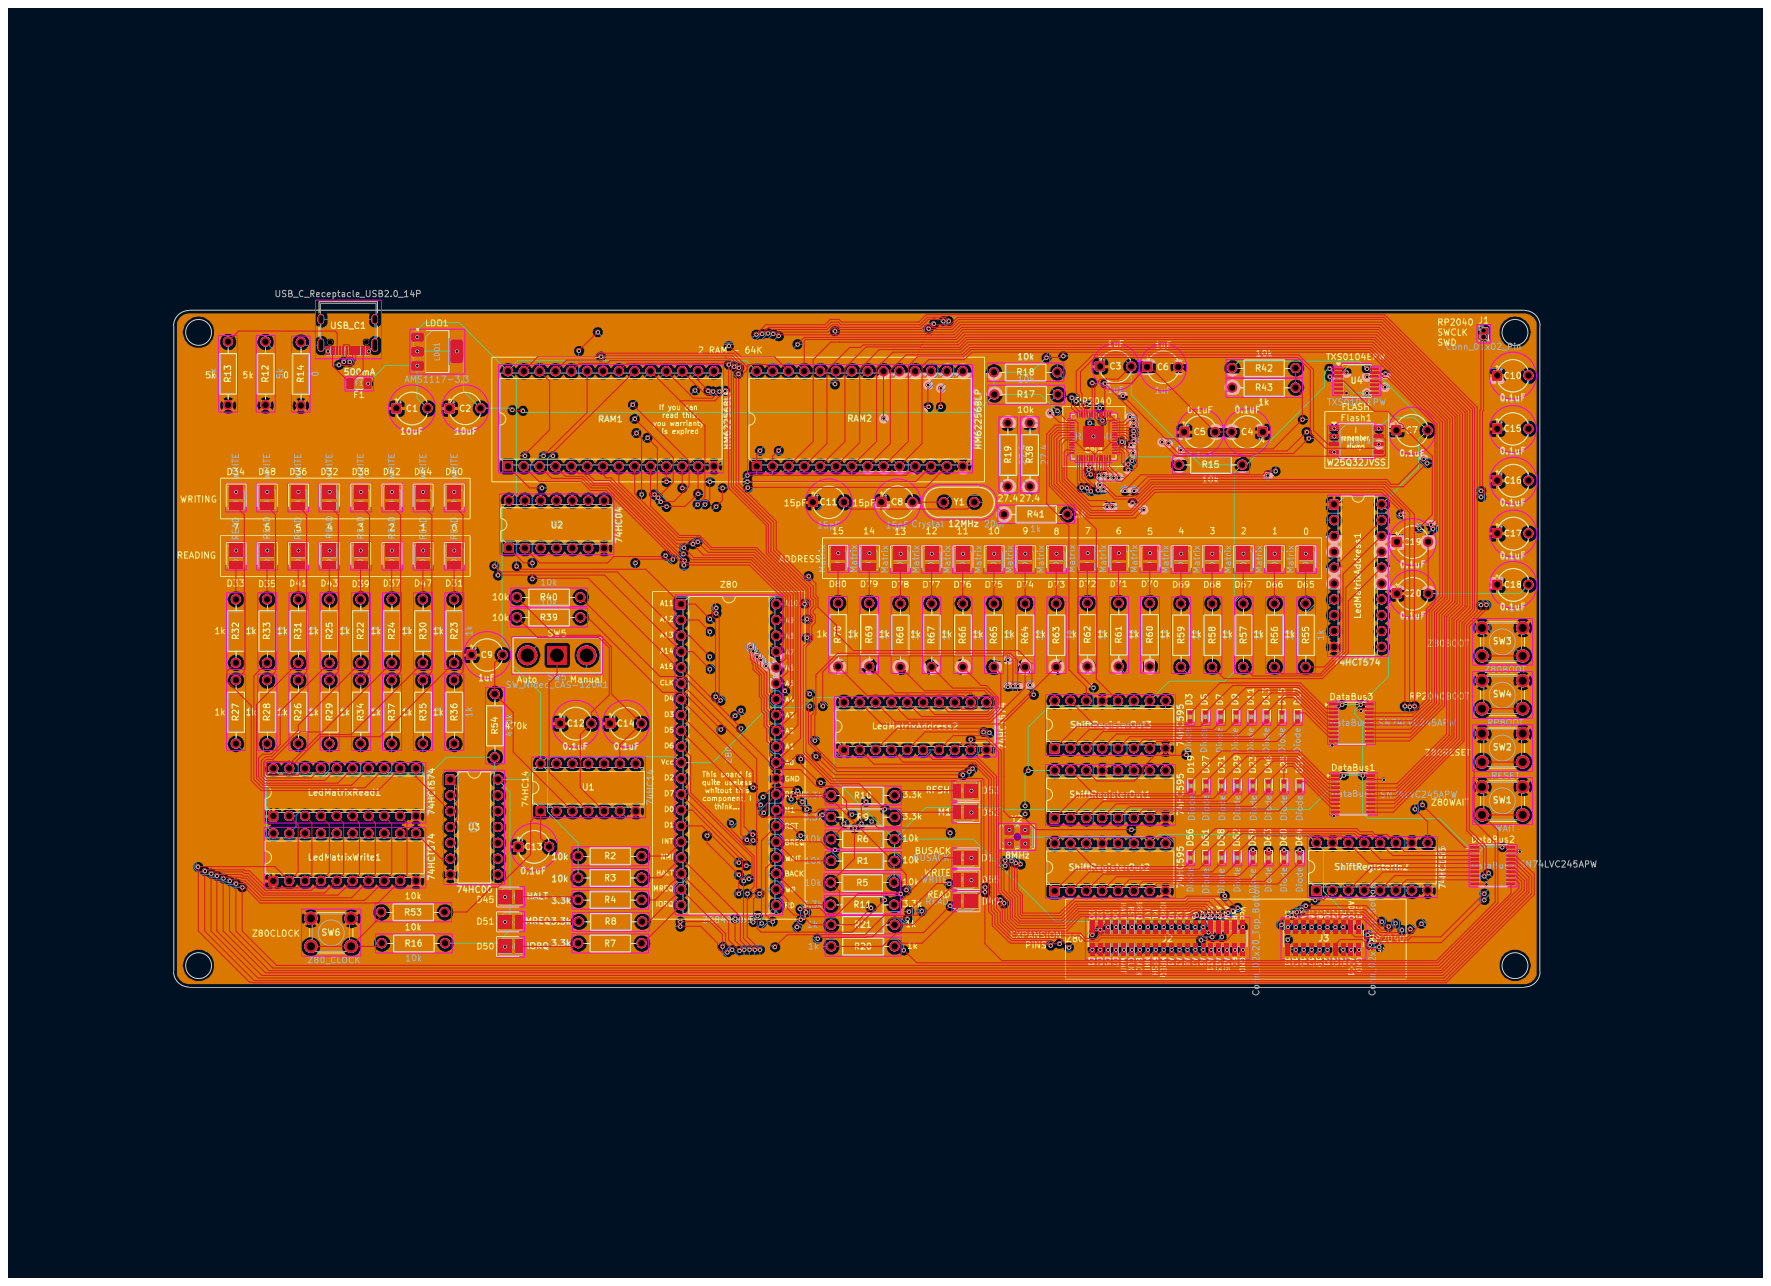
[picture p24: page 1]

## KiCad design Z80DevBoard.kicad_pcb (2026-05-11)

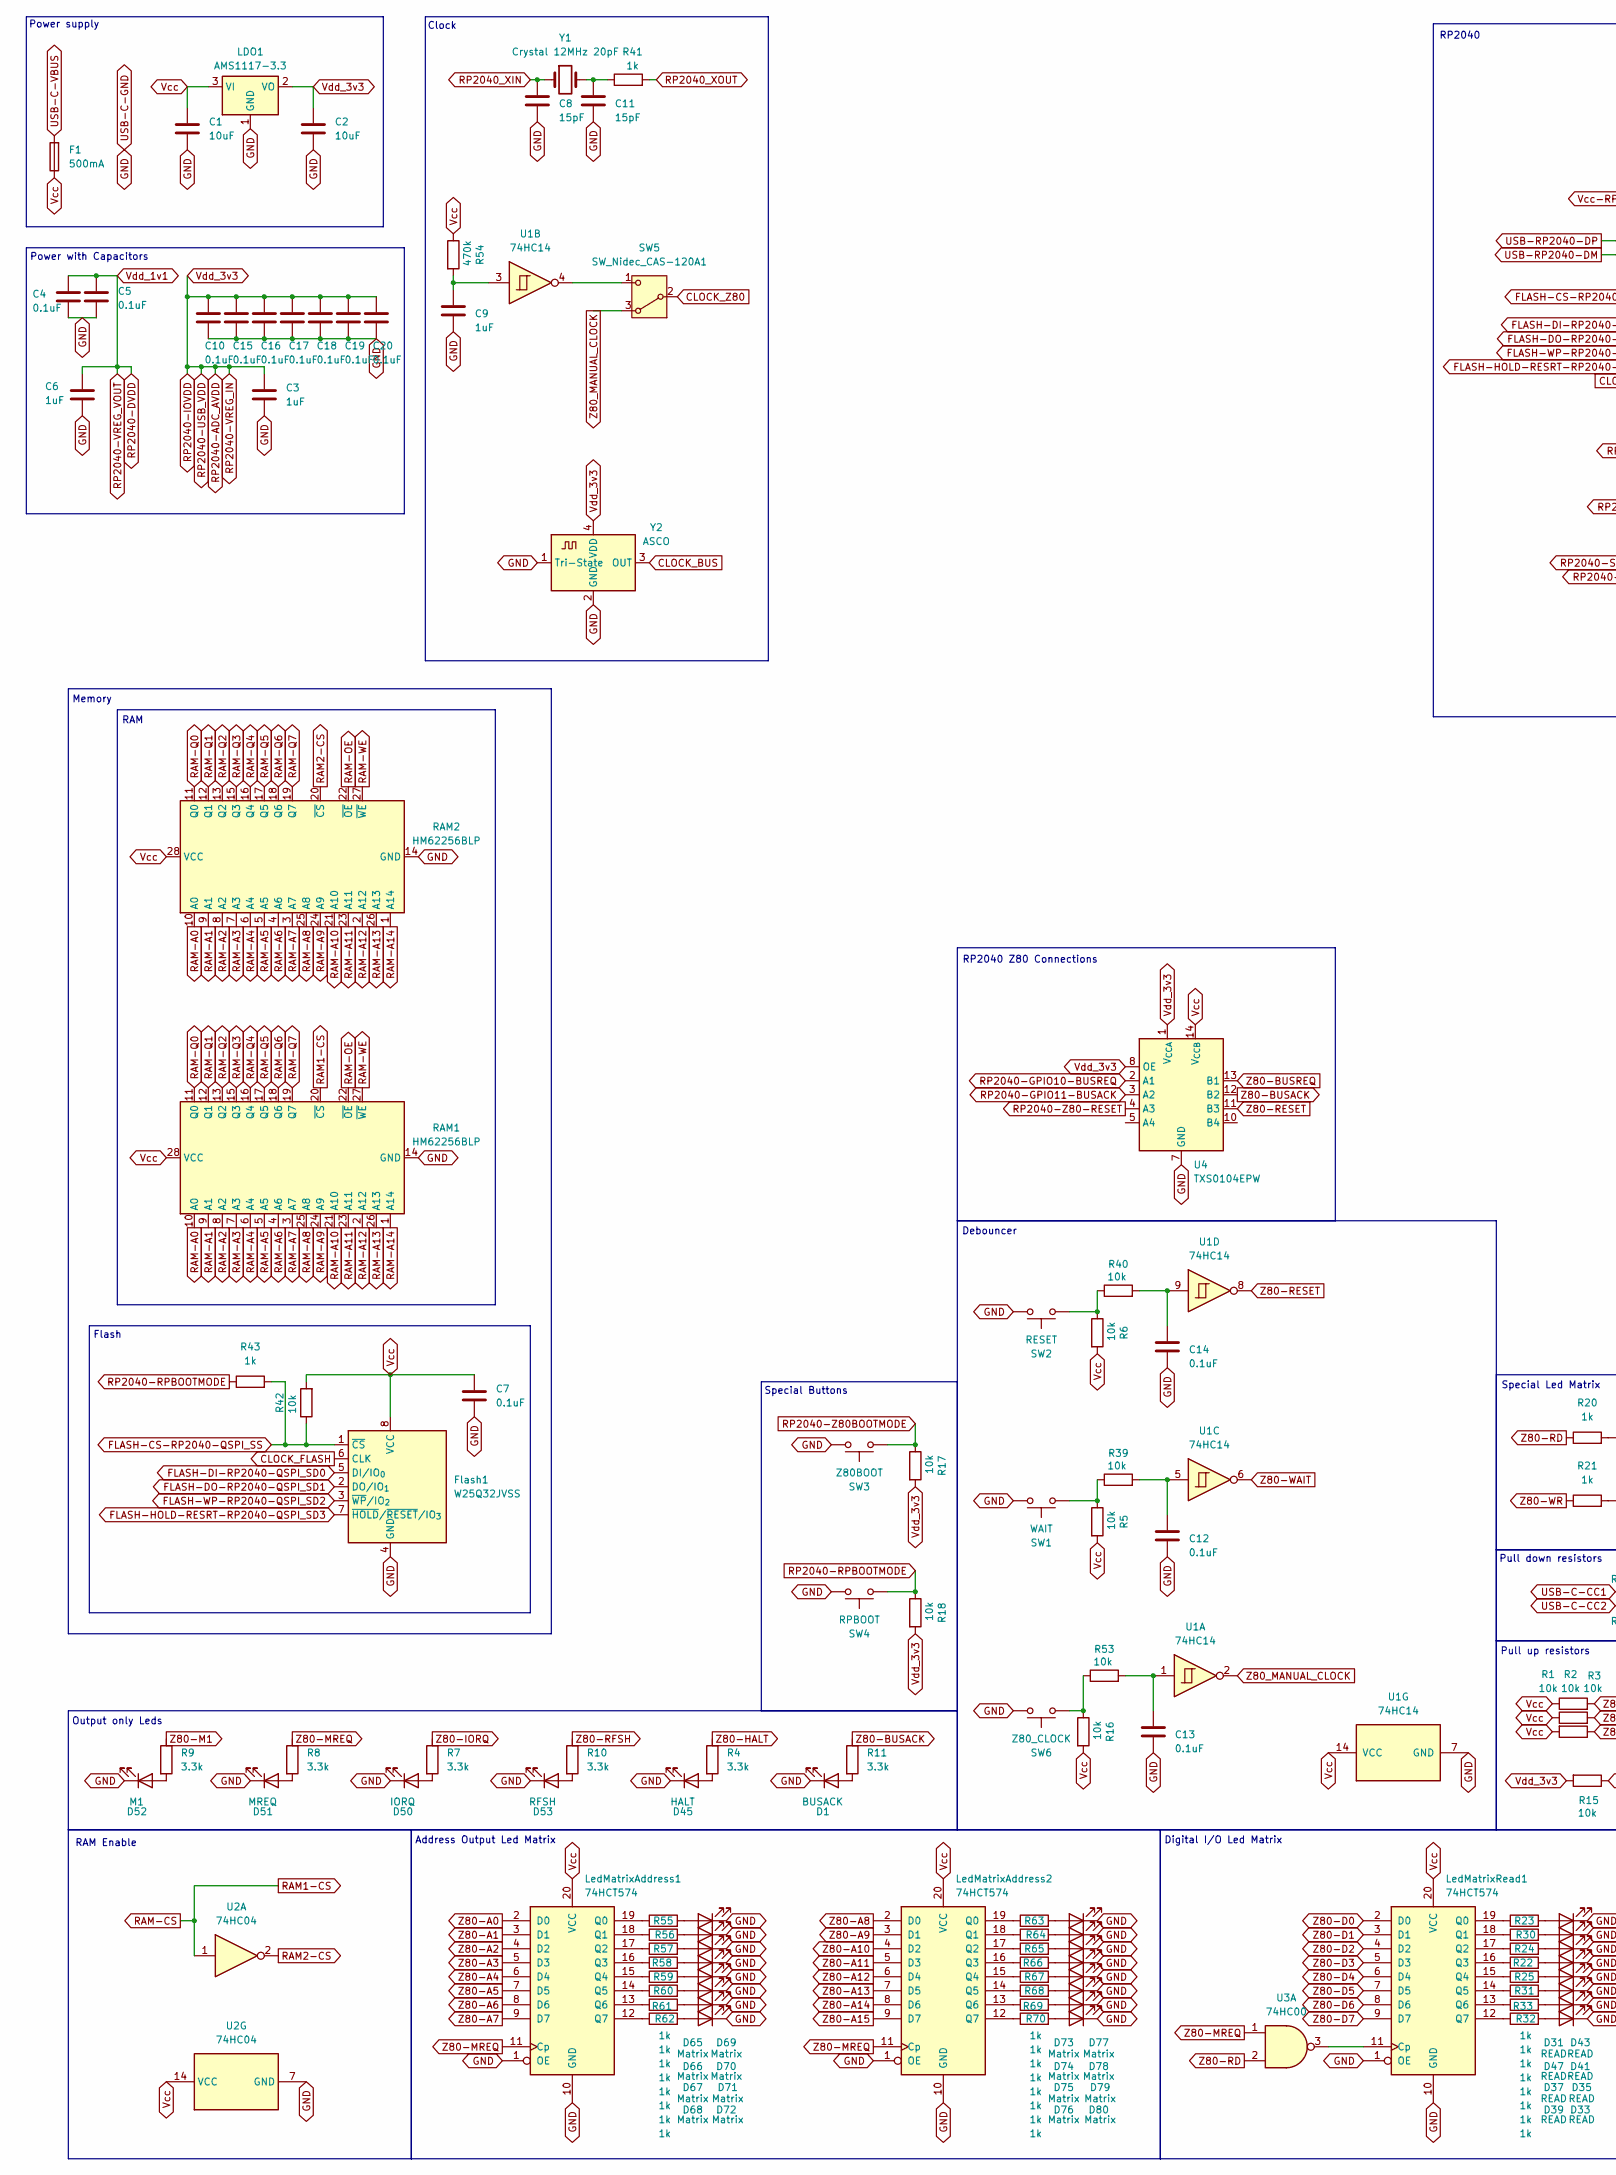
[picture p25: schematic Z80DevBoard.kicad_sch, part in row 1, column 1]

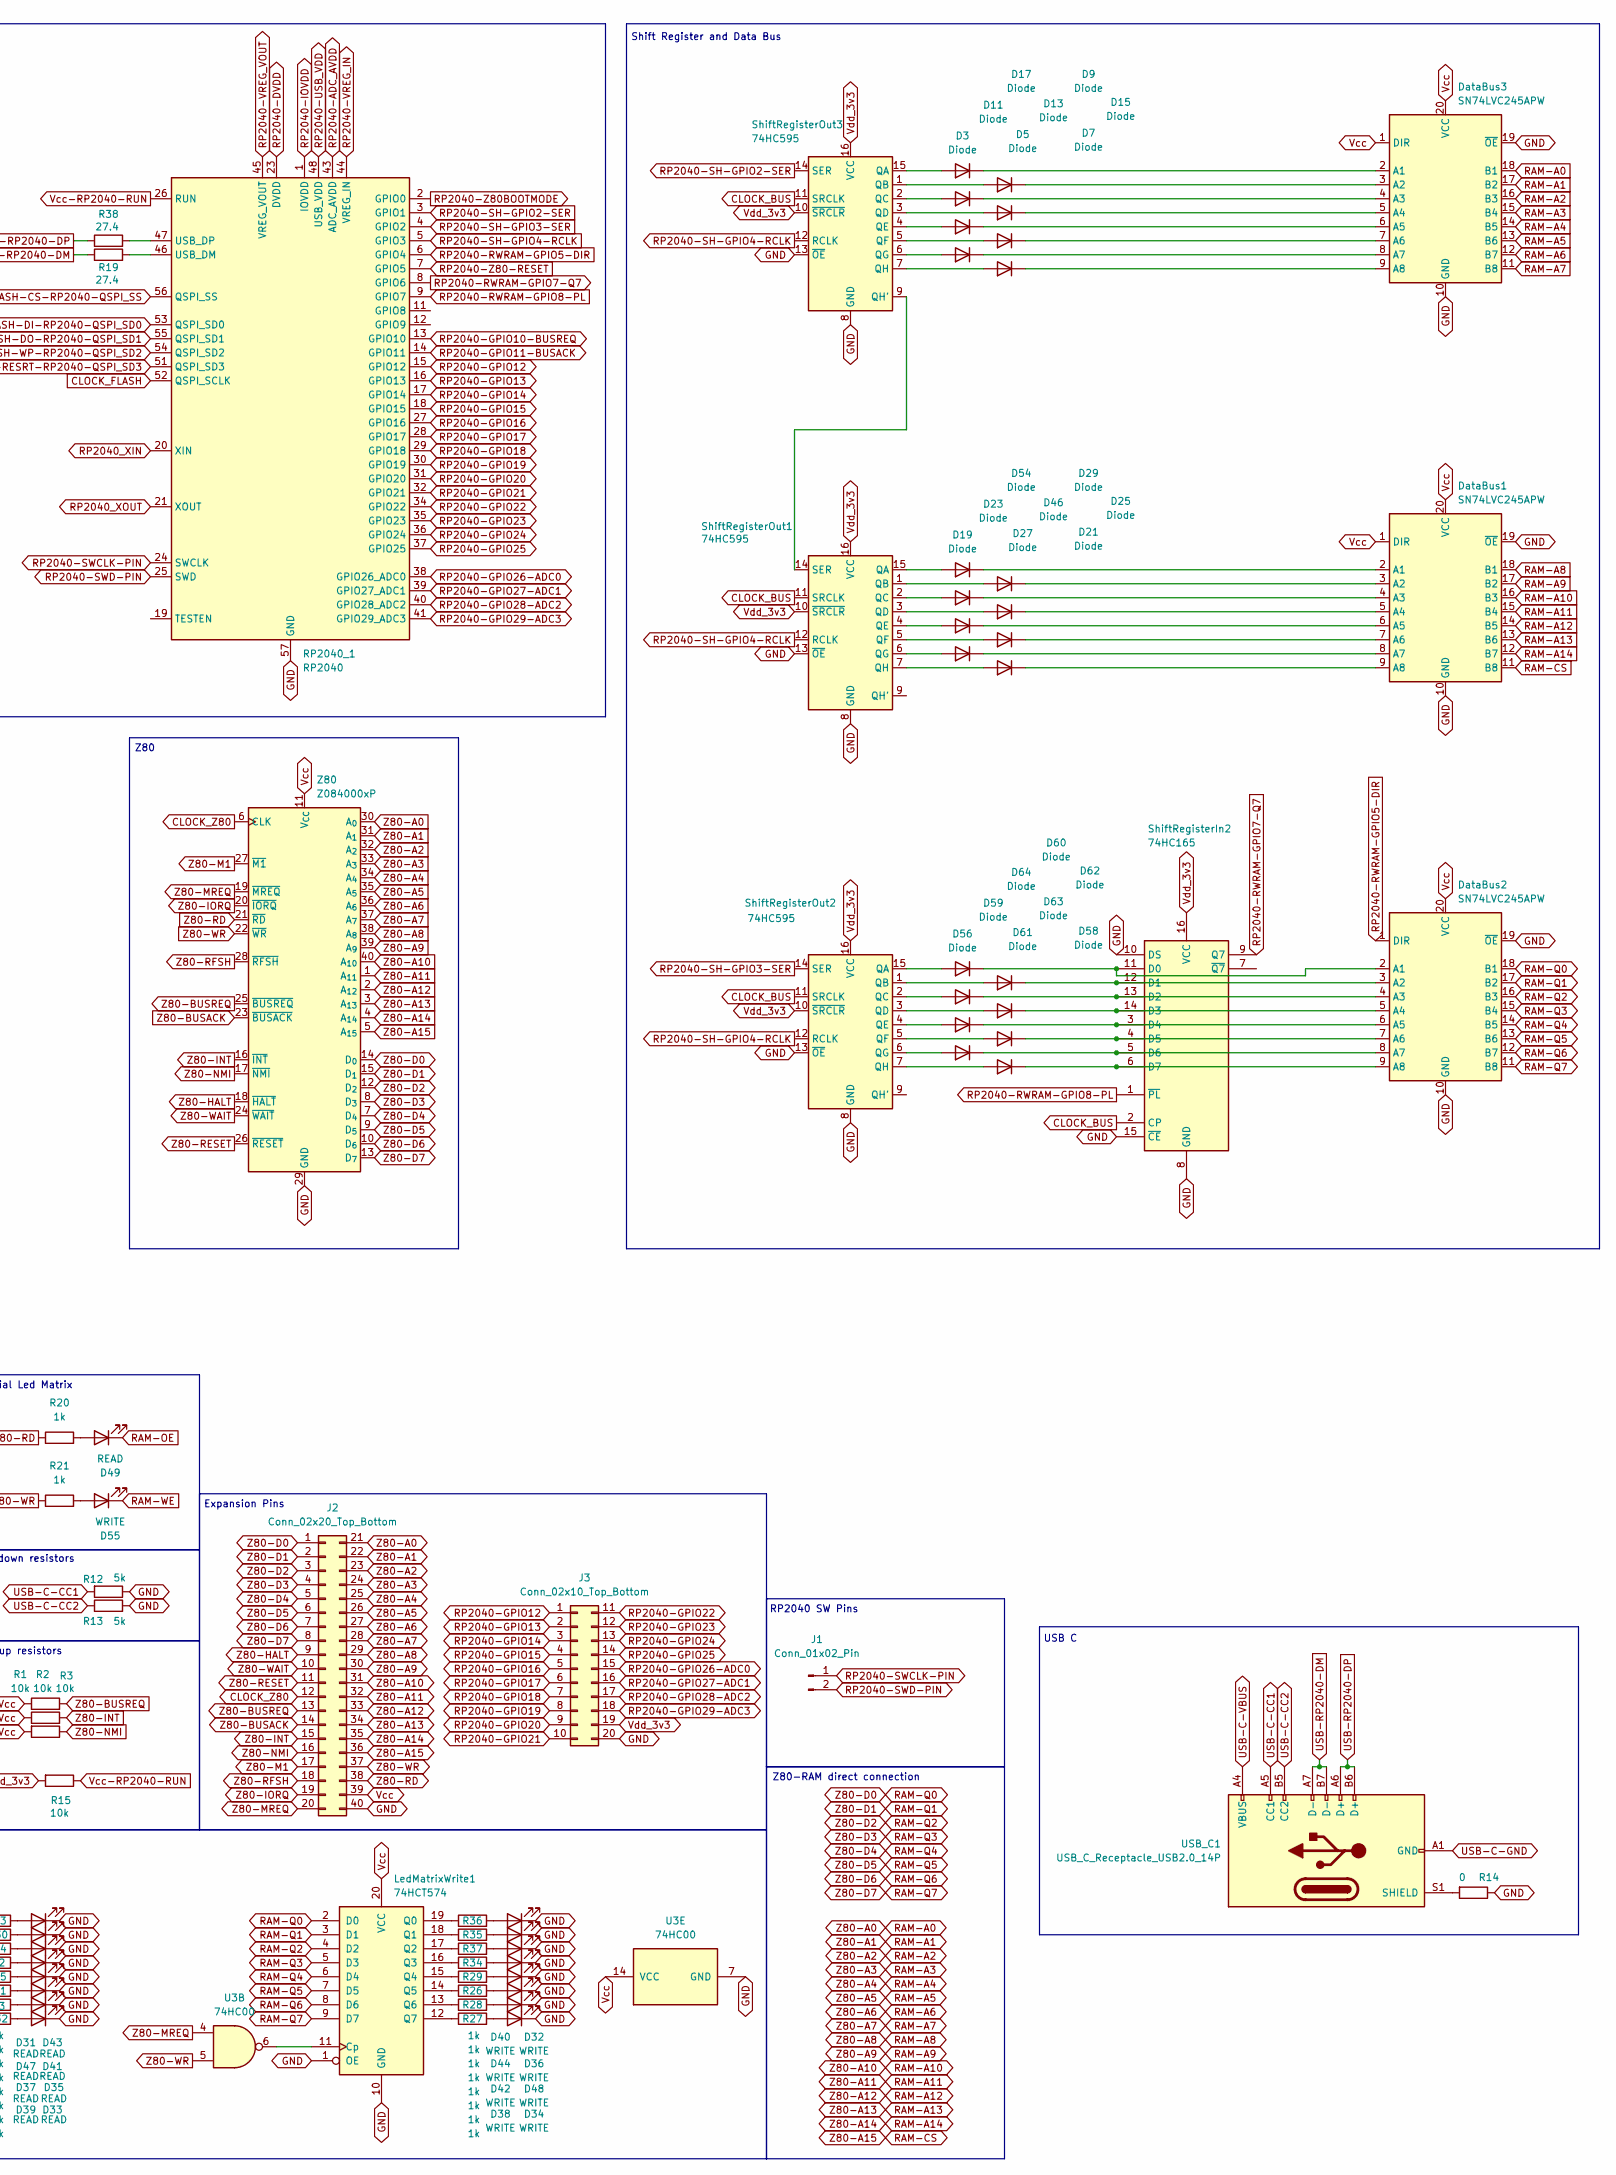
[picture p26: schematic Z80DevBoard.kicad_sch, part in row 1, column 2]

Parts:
C1, C2: 10uF; CP_Radial_Tantal_D5.0mm_P5.00mm
C3, C6, C9: 1uF; CP_Radial_Tantal_D5.0mm_P5.00mm
C4, C5, C7, C10, C12, C13, C14, C15, C16, C17, C18, C19, C20: 0.1uF; CP_Radial_Tantal_D5.0mm_P5.00mm
C8, C11: 15pF; CP_Radial_Tantal_D5.0mm_P5.00mm
D1: BUSACK; LED_PLCC_2835
D3, D5, D7, D9, D11, D13, D15, D17, D19, D21, D23, D25, D27, D29, D46, D54, D56, D58, D59, D60, D61, D62, D63, D64: Diode; D_SOD-523
D31, D33, D35, D37, D39, D41, D43, D47, D49: READ; LED_PLCC_2835
D32, D34, D36, D38, D40, D42, D44, D48, D55: WRITE; LED_PLCC_2835
D45: HALT; LED_PLCC_2835
D50: IORQ; LED_PLCC_2835
D51: MREQ; LED_PLCC_2835
D52: M1; LED_PLCC_2835
D53: RFSH; LED_PLCC_2835
D65, D66, D67, D68, D69, D70, D71, D72, D73, D74, D75, D76, D77, D78, D79, D80: Matrix; LED_PLCC_2835
DataBus1, DataBus2, DataBus3: SN74LVC245APW; TSSOP-20_4.4x6.5mm_P0.65mm
F1: 500mA; Fuse_1206_3216Metric
Flash1: W25Q32JVSS; SOIC-8_5.3x5.3mm_P1.27mm
J1: Conn_01x02_Pin; PinHeader_1x02_P1.00mm_Vertical
J2: Conn_02x20_Top_Bottom; PinSocket_2x20_P1.27mm_Vertical_SMD
J3: Conn_02x10_Top_Bottom; PinSocket_2x10_P1.27mm_Vertical_SMD
LDO1: AMS1117-3.3; SOT-223-3_TabPin2
LedMatrixAddress1, LedMatrixAddress2: 74HCT574; DIP-20_W7.62mm
LedMatrixRead1: 74HCT574; DIP-20_W7.62mm
LedMatrixWrite1: 74HCT574; DIP-20_W7.62mm
R1, R2, R3, R5, R6, R15, R16, R17, R18, R39, R40, R42, R53: 10k; R_Axial_DIN0207_L6.3mm_D2.5mm_P10.16mm_Horizontal
R4, R7, R8, R9, R10, R11: 3.3k; R_Axial_DIN0207_L6.3mm_D2.5mm_P10.16mm_Horizontal
R12, R13: 5k; R_Axial_DIN0207_L6.3mm_D2.5mm_P10.16mm_Horizontal
R14: 0; R_Axial_DIN0207_L6.3mm_D2.5mm_P10.16mm_Horizontal
R19, R38: 27.4; R_Axial_DIN0207_L6.3mm_D2.5mm_P10.16mm_Horizontal
R20, R21, R22, R23, R24, R25, R26, R27, R28, R29, R30, R31, R32, R33, R34, R35, R36, R37, R41, R43, R55, R56, R57, R58, R59, R60, R61, R62, R63, R64, R65, R66, R67, R68, R69, R70: 1k; R_Axial_DIN0207_L6.3mm_D2.5mm_P10.16mm_Horizontal
R54: 470k; R_Axial_DIN0207_L6.3mm_D2.5mm_P10.16mm_Horizontal
RAM1, RAM2: HM62256BLP; DIP-28_W15.24mm
RP2040_1: RP2040; QFN-56-1EP_7x7mm_P0.4mm_EP3.2x3.2mm
SW1: WAIT; SW_PUSH_6mm
SW2: RESET; SW_PUSH_6mm
SW3: Z80BOOT; SW_PUSH_6mm
SW4: RPBOOT; SW_PUSH_6mm
SW5: SW_Nidec_CAS-120A1; SW_Slide-03_Wuerth-WS-SLTV
SW6: Z80_CLOCK; SW_PUSH_6mm_H7.3mm
ShiftRegisterIn2: 74HC165; DIP-16_W7.62mm
ShiftRegisterOut1, ShiftRegisterOut2, ShiftRegisterOut3: 74HC595; DIP-16_W7.62mm
U1: 74HC14; DIP-14_W7.62mm
U2: 74HC04; DIP-14_W7.62mm
U3: 74HC00; DIP-14_W7.62mm
U4: TXS0104EPW; TSSOP-14_4.4x5mm_P0.65mm
USB_C1: USB_C_Receptacle_USB2.0_14P; USB_C_Receptacle_HRO_TYPE-C-31-M-12
Y1: Crystal 12MHz 20pF; Crystal_HC49-4H_Vertical
Y2: ASCO; Oscillator_SMD_SiT_PQFN-4Pin_5.0x3.2mm
Z80: Z084000xP; DIP-40_W15.24mm

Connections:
CLOCK_BUS: ShiftRegisterIn2.2 (CP), ShiftRegisterOut1.11 (SRCLK), ShiftRegisterOut2.11 (SRCLK), ShiftRegisterOut3.11 (SRCLK), Y2.3 (OUT)
CLOCK_FLASH: Flash1.6 (CLK), RP2040_1.52 (QSPI_SCLK); also elsewhere on the board
CLOCK_Z80: J2.12, SW5.2 (B), Z80.6 (CLK)
FLASH-CS-RP2040-QSPI_SS: Flash1.1 (~CS), R42.1, R43.2, RP2040_1.56 (QSPI_SS); also elsewhere on the board
FLASH-DI-RP2040-QSPI_SD0: Flash1.5 (DI/IO_{0}), RP2040_1.53 (QSPI_SD0); also elsewhere on the board
FLASH-DO-RP2040-QSPI_SD1: Flash1.2 (DO/IO_{1}), RP2040_1.55 (QSPI_SD1); also elsewhere on the board
FLASH-HOLD-RESRT-RP2040-QSPI_SD3: Flash1.7 (~HOLD/~RESET/IO_{3}), RP2040_1.51 (QSPI_SD3); also elsewhere on the board
FLASH-WP-RP2040-QSPI_SD2: Flash1.3 (~WP/IO_{2}), RP2040_1.54 (QSPI_SD2); also elsewhere on the board
GND: C1.1, C2.1, C3.1, C4.1, C5.1, C6.2, C7.1, C8.1, C9.1, C10.1, C11.1, C12.1, C13.1, C14.1, C15.1, C16.1, C17.1, C18.1, C19.1, C20.1, D1.1 (K), D31.1 (K), D32.1 (K), D33.1 (K), D34.1 (K), D35.1 (K), D36.1 (K), D37.1 (K), D38.1 (K), D39.1 (K), D40.1 (K), D41.1 (K), D42.1 (K), D43.1 (K), D44.1 (K), D45.1 (K), D47.1 (K), D48.1 (K), D50.1 (K), D51.1 (K), D52.1 (K), D53.1 (K), D65.1 (K), D66.1 (K), D67.1 (K), D68.1 (K), D69.1 (K), D70.1 (K), D71.1 (K), D72.1 (K), D73.1 (K), D74.1 (K), D75.1 (K), D76.1 (K), D77.1 (K), D78.1 (K), D79.1 (K), D80.1 (K), DataBus1.10 (GND), DataBus1.19 (~OE), DataBus2.10 (GND), DataBus2.19 (~OE), DataBus3.10 (GND), DataBus3.19 (~OE), Flash1.4 (GND), J2.40, J3.20, LDO1.1 (GND), LedMatrixAddress1.1 (OE), LedMatrixAddress1.10 (GND), LedMatrixAddress2.1 (OE), LedMatrixAddress2.10 (GND), LedMatrixRead1.1 (OE), LedMatrixRead1.10 (GND), LedMatrixWrite1.1 (OE), LedMatrixWrite1.10 (GND), R12.1, R13.2, R14.1, RAM1.14 (GND), RAM2.14 (GND), RP2040_1.57 (GND), SW1.1, SW2.1, SW3.1, SW4.1, SW6.1, ShiftRegisterIn2.8 (GND), ShiftRegisterIn2.10 (DS), ShiftRegisterIn2.15 (~CE), ShiftRegisterOut1.8 (GND), ShiftRegisterOut1.13 (~OE), ShiftRegisterOut2.8 (GND), ShiftRegisterOut2.13 (~OE), ShiftRegisterOut3.8 (GND), ShiftRegisterOut3.13 (~OE), U1.7 (GND), U2.7 (GND), U3.7 (GND), U4.7 (GND), USB_C1.A1 (GND), USB_C1.A12 (GND), USB_C1.B1 (GND), USB_C1.B12 (GND), Y2.1 (Tri-State), Y2.2 (GND), Z80.29 (GND); also elsewhere on the board
unnamed: C9.2, R54.2, U1.3
unnamed: C11.2, R41.1, Y1.2
unnamed: C12.2, R39.2, U1.5
unnamed: C13.2, R53.2, U1.1
unnamed: C14.2, R40.2, U1.9
unnamed: D1.2 (A), R11.2
unnamed: D3.2 (A), ShiftRegisterOut3.15 (QA)
unnamed: D3.1 (K), DataBus3.2 (A1)
unnamed: D5.2 (A), ShiftRegisterOut3.1 (QB)
unnamed: D5.1 (K), DataBus3.3 (A2)
unnamed: D7.2 (A), ShiftRegisterOut3.2 (QC)
unnamed: D7.1 (K), DataBus3.4 (A3)
unnamed: D9.2 (A), ShiftRegisterOut3.3 (QD)
unnamed: D9.1 (K), DataBus3.5 (A4)
unnamed: D11.2 (A), ShiftRegisterOut3.4 (QE)
unnamed: D11.1 (K), DataBus3.6 (A5)
unnamed: D13.2 (A), ShiftRegisterOut3.5 (QF)
unnamed: D13.1 (K), DataBus3.7 (A6)
unnamed: D15.2 (A), ShiftRegisterOut3.6 (QG)
unnamed: D15.1 (K), DataBus3.8 (A7)
unnamed: D17.2 (A), ShiftRegisterOut3.7 (QH)
unnamed: D17.1 (K), DataBus3.9 (A8)
unnamed: D19.2 (A), ShiftRegisterOut1.15 (QA)
unnamed: D19.1 (K), DataBus1.2 (A1)
unnamed: D21.2 (A), ShiftRegisterOut1.2 (QC)
unnamed: D21.1 (K), DataBus1.4 (A3)
unnamed: D23.2 (A), ShiftRegisterOut1.4 (QE)
unnamed: D23.1 (K), DataBus1.6 (A5)
unnamed: D25.2 (A), ShiftRegisterOut1.6 (QG)
unnamed: D25.1 (K), DataBus1.8 (A7)
unnamed: D27.2 (A), ShiftRegisterOut1.1 (QB)
unnamed: D27.1 (K), DataBus1.3 (A2)
unnamed: D29.2 (A), ShiftRegisterOut1.3 (QD)
unnamed: D29.1 (K), DataBus1.5 (A4)
unnamed: D31.2 (A), R23.2
unnamed: D32.2 (A), R29.2
unnamed: D33.2 (A), R32.2
unnamed: D34.2 (A), R27.2
unnamed: D35.2 (A), R33.2
unnamed: D36.2 (A), R26.2
unnamed: D37.2 (A), R24.2
unnamed: D38.2 (A), R34.2
unnamed: D39.2 (A), R22.2
unnamed: D40.2 (A), R36.2
unnamed: D41.2 (A), R31.2
unnamed: D42.2 (A), R37.2
unnamed: D43.2 (A), R25.2
unnamed: D44.2 (A), R35.2
unnamed: D45.2 (A), R4.2
unnamed: D46.2 (A), ShiftRegisterOut1.5 (QF)
unnamed: D46.1 (K), DataBus1.7 (A6)
unnamed: D47.2 (A), R30.2
unnamed: D48.2 (A), R28.2
unnamed: D49.2 (A), R20.2
unnamed: D50.2 (A), R7.2
unnamed: D51.2 (A), R8.2
unnamed: D52.2 (A), R9.2
unnamed: D53.2 (A), R10.2
unnamed: D54.2 (A), ShiftRegisterOut1.7 (QH)
unnamed: D54.1 (K), DataBus1.9 (A8)
unnamed: D55.2 (A), R21.2
unnamed: D56.2 (A), ShiftRegisterOut2.15 (QA)
unnamed: D56.1 (K), DataBus2.2 (A1), ShiftRegisterIn2.11 (D0)
unnamed: D58.2 (A), ShiftRegisterOut2.2 (QC)
unnamed: D58.1 (K), DataBus2.4 (A3), ShiftRegisterIn2.13 (D2)
unnamed: D59.2 (A), ShiftRegisterOut2.4 (QE)
unnamed: D59.1 (K), DataBus2.6 (A5), ShiftRegisterIn2.3 (D4)
unnamed: D60.2 (A), ShiftRegisterOut2.6 (QG)
unnamed: D60.1 (K), DataBus2.8 (A7), ShiftRegisterIn2.5 (D6)
unnamed: D61.2 (A), ShiftRegisterOut2.1 (QB)
unnamed: D61.1 (K), DataBus2.3 (A2), ShiftRegisterIn2.12 (D1)
unnamed: D62.2 (A), ShiftRegisterOut2.3 (QD)
unnamed: D62.1 (K), DataBus2.5 (A4), ShiftRegisterIn2.14 (D3)
unnamed: D63.2 (A), ShiftRegisterOut2.5 (QF)
unnamed: D63.1 (K), DataBus2.7 (A6), ShiftRegisterIn2.4 (D5)
unnamed: D64.2 (A), ShiftRegisterOut2.7 (QH)
unnamed: D64.1 (K), DataBus2.9 (A8), ShiftRegisterIn2.6 (D7)
unnamed: D65.2 (A), R55.2
unnamed: D66.2 (A), R56.2
unnamed: D67.2 (A), R57.2
unnamed: D68.2 (A), R58.2
unnamed: D69.2 (A), R59.2
unnamed: D70.2 (A), R60.2
unnamed: D71.2 (A), R61.2
unnamed: D72.2 (A), R62.2
unnamed: D73.2 (A), R63.2
unnamed: D74.2 (A), R64.2
unnamed: D75.2 (A), R65.2
unnamed: D76.2 (A), R66.2
unnamed: D77.2 (A), R67.2
unnamed: D78.2 (A), R68.2
unnamed: D79.2 (A), R69.2
unnamed: D80.2 (A), R70.2
unnamed: LedMatrixAddress1.19 (Q0), R55.1
unnamed: LedMatrixAddress1.18 (Q1), R56.1
unnamed: LedMatrixAddress1.17 (Q2), R57.1
unnamed: LedMatrixAddress1.16 (Q3), R58.1
unnamed: LedMatrixAddress1.15 (Q4), R59.1
unnamed: LedMatrixAddress1.14 (Q5), R60.1
unnamed: LedMatrixAddress1.13 (Q6), R61.1
unnamed: LedMatrixAddress1.12 (Q7), R62.1
unnamed: LedMatrixAddress2.19 (Q0), R63.1
unnamed: LedMatrixAddress2.18 (Q1), R64.1
unnamed: LedMatrixAddress2.17 (Q2), R65.1
unnamed: LedMatrixAddress2.16 (Q3), R66.1
unnamed: LedMatrixAddress2.15 (Q4), R67.1
unnamed: LedMatrixAddress2.14 (Q5), R68.1
unnamed: LedMatrixAddress2.13 (Q6), R69.1
unnamed: LedMatrixAddress2.12 (Q7), R70.1
unnamed: LedMatrixRead1.11 (Cp), U3.3
unnamed: LedMatrixRead1.19 (Q0), R23.1
unnamed: LedMatrixRead1.18 (Q1), R30.1
unnamed: LedMatrixRead1.17 (Q2), R24.1
unnamed: LedMatrixRead1.16 (Q3), R22.1
unnamed: LedMatrixRead1.15 (Q4), R25.1
unnamed: LedMatrixRead1.14 (Q5), R31.1
unnamed: LedMatrixRead1.13 (Q6), R33.1
unnamed: LedMatrixRead1.12 (Q7), R32.1
unnamed: LedMatrixWrite1.11 (Cp), U3.6
unnamed: LedMatrixWrite1.19 (Q0), R36.1
unnamed: LedMatrixWrite1.18 (Q1), R35.1
unnamed: LedMatrixWrite1.17 (Q2), R37.1
unnamed: LedMatrixWrite1.16 (Q3), R34.1
unnamed: LedMatrixWrite1.15 (Q4), R29.1
unnamed: LedMatrixWrite1.14 (Q5), R26.1
unnamed: LedMatrixWrite1.13 (Q6), R28.1
unnamed: LedMatrixWrite1.12 (Q7), R27.1
unnamed: R16.1, R53.1, SW6.2
unnamed: R5.1, R39.1, SW1.2
unnamed: R6.1, R40.1, SW2.2
unnamed 139: R19.2, RP2040_1.46 (USB_DM); also elsewhere on the board
unnamed 140: R38.2, RP2040_1.47 (USB_DP); also elsewhere on the board
unnamed: SW5.1 (C), U1.4
unnamed: ShiftRegisterOut1.14 (SER), ShiftRegisterOut3.9 (QH')
unnamed: R14.2, USB_C1.S1 (SHIELD)
RAM2-CS: RAM2.20 (~CS), U2.2
RAM-A0: DataBus3.18 (B1), J2.21, LedMatrixAddress1.2 (D0), RAM1.10 (A0), RAM2.10 (A0), Z80.30 (A_{0})
RAM-A1: DataBus3.17 (B2), J2.22, LedMatrixAddress1.3 (D1), RAM1.9 (A1), RAM2.9 (A1), Z80.31 (A_{1})
RAM-A2: DataBus3.16 (B3), J2.23, LedMatrixAddress1.4 (D2), RAM1.8 (A2), RAM2.8 (A2), Z80.32 (A_{2})
RAM-A3: DataBus3.15 (B4), J2.24, LedMatrixAddress1.5 (D3), RAM1.7 (A3), RAM2.7 (A3), Z80.33 (A_{3})
RAM-A4: DataBus3.14 (B5), J2.25, LedMatrixAddress1.6 (D4), RAM1.6 (A4), RAM2.6 (A4), Z80.34 (A_{4})
RAM-A5: DataBus3.13 (B6), J2.26, LedMatrixAddress1.7 (D5), RAM1.5 (A5), RAM2.5 (A5), Z80.35 (A_{5})
RAM-A6: DataBus3.12 (B7), J2.27, LedMatrixAddress1.8 (D6), RAM1.4 (A6), RAM2.4 (A6), Z80.36 (A_{6})
RAM-A7: DataBus3.11 (B8), J2.28, LedMatrixAddress1.9 (D7), RAM1.3 (A7), RAM2.3 (A7), Z80.37 (A_{7})
RAM-A8: DataBus1.18 (B1), J2.29, LedMatrixAddress2.2 (D0), RAM1.25 (A8), RAM2.25 (A8), Z80.38 (A_{8})
RAM-A9: DataBus1.17 (B2), J2.30, LedMatrixAddress2.3 (D1), RAM1.24 (A9), RAM2.24 (A9), Z80.39 (A_{9})
RAM-A10: DataBus1.16 (B3), J2.31, LedMatrixAddress2.4 (D2), RAM1.21 (A10), RAM2.21 (A10), Z80.40 (A_{10})
RAM-A11: DataBus1.15 (B4), J2.32, LedMatrixAddress2.5 (D3), RAM1.23 (A11), RAM2.23 (A11), Z80.1 (A_{11})
RAM-A12: DataBus1.14 (B5), J2.33, LedMatrixAddress2.6 (D4), RAM1.2 (A12), RAM2.2 (A12), Z80.2 (A_{12})
RAM-A13: DataBus1.13 (B6), J2.34, LedMatrixAddress2.7 (D5), RAM1.26 (A13), RAM2.26 (A13), Z80.3 (A_{13})
RAM-A14: DataBus1.12 (B7), J2.35, LedMatrixAddress2.8 (D6), RAM1.1 (A14), RAM2.1 (A14), Z80.4 (A_{14})
RAM-CS: DataBus1.11 (B8), J2.36, LedMatrixAddress2.9 (D7), RAM1.20 (~CS), U2.1, Z80.5 (A_{15})
RAM-OE: D49.1 (K), RAM1.22 (~OE), RAM2.22 (~OE)
RAM-Q0: DataBus2.18 (B1), J2.1, LedMatrixRead1.2 (D0), LedMatrixWrite1.2 (D0), RAM1.11 (Q0), RAM2.11 (Q0), Z80.14 (D_{0})
RAM-Q1: DataBus2.17 (B2), J2.2, LedMatrixRead1.3 (D1), LedMatrixWrite1.3 (D1), RAM1.12 (Q1), RAM2.12 (Q1), Z80.15 (D_{1})
RAM-Q2: DataBus2.16 (B3), J2.3, LedMatrixRead1.4 (D2), LedMatrixWrite1.4 (D2), RAM1.13 (Q2), RAM2.13 (Q2), Z80.12 (D_{2})
RAM-Q3: DataBus2.15 (B4), J2.4, LedMatrixRead1.5 (D3), LedMatrixWrite1.5 (D3), RAM1.15 (Q3), RAM2.15 (Q3), Z80.8 (D_{3})
RAM-Q4: DataBus2.14 (B5), J2.5, LedMatrixRead1.6 (D4), LedMatrixWrite1.6 (D4), RAM1.16 (Q4), RAM2.16 (Q4), Z80.7 (D_{4})
RAM-Q5: DataBus2.13 (B6), J2.6, LedMatrixRead1.7 (D5), LedMatrixWrite1.7 (D5), RAM1.17 (Q5), RAM2.17 (Q5), Z80.9 (D_{5})
RAM-Q6: DataBus2.12 (B7), J2.7, LedMatrixRead1.8 (D6), LedMatrixWrite1.8 (D6), RAM1.18 (Q6), RAM2.18 (Q6), Z80.10 (D_{6})
RAM-Q7: DataBus2.11 (B8), J2.8, LedMatrixRead1.9 (D7), LedMatrixWrite1.9 (D7), RAM1.19 (Q7), RAM2.19 (Q7), Z80.13 (D_{7})
RAM-WE: D55.1 (K), RAM1.27 (~WE), RAM2.27 (~WE)
RP2040-ADC_AVDD: C2.2, C3.2, C10.2, C15.2, C16.2, C17.2, C18.2, C19.2, C20.2, J3.19, LDO1.2 (VO), R15.2, R17.2, R18.2, RP2040_1.1 (IOVDD), RP2040_1.10 (IOVDD), RP2040_1.22 (IOVDD), RP2040_1.33 (IOVDD), RP2040_1.42 (IOVDD), RP2040_1.43 (ADC_AVDD), RP2040_1.44 (VREG_IN), RP2040_1.48 (USB_VDD), RP2040_1.49 (IOVDD), ShiftRegisterIn2.16 (VCC), ShiftRegisterOut1.10 (~SRCLR), ShiftRegisterOut1.16 (VCC), ShiftRegisterOut2.10 (~SRCLR), ShiftRegisterOut2.16 (VCC), ShiftRegisterOut3.10 (~SRCLR), ShiftRegisterOut3.16 (VCC), U4.1 (V_{CCA}), U4.8 (OE), Y2.4 (VDD); also elsewhere on the board
RP2040-DVDD: C4.2, C5.2, C6.1, RP2040_1.23 (DVDD), RP2040_1.45 (VREG_VOUT), RP2040_1.50 (DVDD); also elsewhere on the board
RP2040-GPIO10-BUSREQ: RP2040_1.13 (GPIO10), U4.2 (A1); also elsewhere on the board
RP2040-GPIO11-BUSACK: RP2040_1.14 (GPIO11), U4.3 (A2); also elsewhere on the board
RP2040-GPIO12: J3.1, RP2040_1.15 (GPIO12); also elsewhere on the board
RP2040-GPIO13: J3.2, RP2040_1.16 (GPIO13); also elsewhere on the board
RP2040-GPIO14: J3.3, RP2040_1.17 (GPIO14); also elsewhere on the board
RP2040-GPIO15: J3.4, RP2040_1.18 (GPIO15); also elsewhere on the board
RP2040-GPIO16: J3.5, RP2040_1.27 (GPIO16); also elsewhere on the board
RP2040-GPIO17: J3.6, RP2040_1.28 (GPIO17); also elsewhere on the board
RP2040-GPIO18: J3.7, RP2040_1.29 (GPIO18); also elsewhere on the board
RP2040-GPIO19: J3.8, RP2040_1.30 (GPIO19); also elsewhere on the board
RP2040-GPIO20: J3.9, RP2040_1.31 (GPIO20); also elsewhere on the board
RP2040-GPIO21: J3.10, RP2040_1.32 (GPIO21); also elsewhere on the board
RP2040-GPIO22: J3.11, RP2040_1.34 (GPIO22); also elsewhere on the board
RP2040-GPIO23: J3.12, RP2040_1.35 (GPIO23); also elsewhere on the board
RP2040-GPIO24: J3.13, RP2040_1.36 (GPIO24); also elsewhere on the board
RP2040-GPIO25: J3.14, RP2040_1.37 (GPIO25); also elsewhere on the board
RP2040-GPIO26-ADC0: J3.15, RP2040_1.38 (GPIO26_ADC0); also elsewhere on the board
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

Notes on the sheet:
Digital I/O Led Matrix
RAM
Special Buttons
Power supply
RP2040 Z80 Connections
Debouncer
Expansion Pins
Z80
Output only Leds
Clock
USB C
Address Output Led Matrix
Power with Capacitors
Pull down resistors
RP2040 SW Pins
Z80-RAM direct connection
RP2040
Special Led Matrix
Pull up resistors
Shift Register and Data Bus
Memory
Flash
RAM Enable

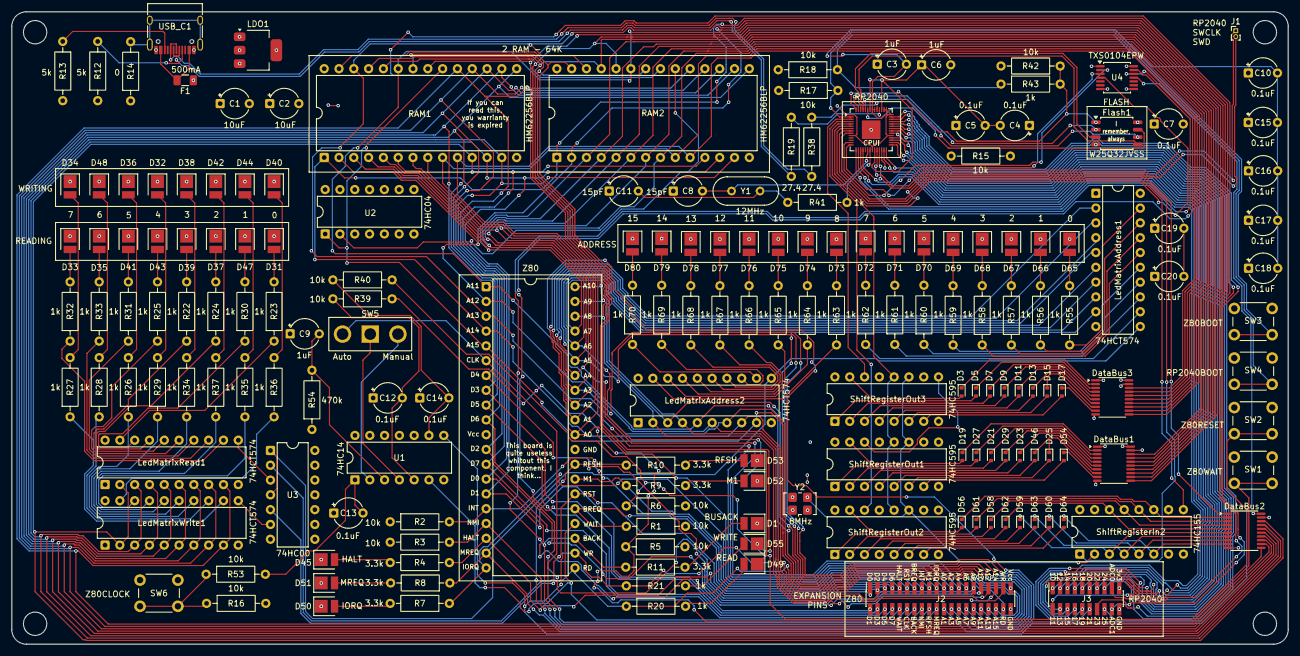
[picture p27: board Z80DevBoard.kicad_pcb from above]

Board: 4 copper layers, 219.0 x 108.5 mm, 179 parts (0 on the bottom side), 227 nets.

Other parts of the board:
RP2040: RP2040; QFN-56-1EP_7x7mm_P0.4mm_EP3.2x3.2mm

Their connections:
CLOCK_FLASH: RP2040.52 (QSPI_SCLK); also elsewhere on the board
FLASH-CS-RP2040-QSPI_SS: RP2040.56 (QSPI_SS); also elsewhere on the board
FLASH-DI-RP2040-QSPI_SD0: RP2040.53 (QSPI_SD0); also elsewhere on the board
FLASH-DO-RP2040-QSPI_SD1: RP2040.55 (QSPI_SD1); also elsewhere on the board
FLASH-HOLD-RESRT-RP2040-QSPI_SD3: RP2040.51 (QSPI_SD3); also elsewhere on the board
FLASH-WP-RP2040-QSPI_SD2: RP2040.54 (QSPI_SD2); also elsewhere on the board
GND: RP2040.57 (GND); also elsewhere on the board
unnamed 139: RP2040.46 (USB_DM); also elsewhere on the board
unnamed 140: RP2040.47 (USB_DP); also elsewhere on the board
RP2040-ADC_AVDD: RP2040.1 (IOVDD), RP2040.10 (IOVDD), RP2040.22 (IOVDD), RP2040.33 (IOVDD), RP2040.42 (IOVDD), RP2040.43 (ADC_AVDD), RP2040.44 (VREG_IN), RP2040.48 (USB_VDD), RP2040.49 (IOVDD); also elsewhere on the board
RP2040-DVDD: RP2040.23 (DVDD), RP2040.45 (VREG_VOUT), RP2040.50 (DVDD); also elsewhere on the board
RP2040-GPIO10-BUSREQ: RP2040.13 (GPIO10); also elsewhere on the board
RP2040-GPIO11-BUSACK: RP2040.14 (GPIO11); also elsewhere on the board
RP2040-GPIO12: RP2040.15 (GPIO12); also elsewhere on the board
RP2040-GPIO13: RP2040.16 (GPIO13); also elsewhere on the board
RP2040-GPIO14: RP2040.17 (GPIO14); also elsewhere on the board
RP2040-GPIO15: RP2040.18 (GPIO15); also elsewhere on the board
RP2040-GPIO16: RP2040.27 (GPIO16); also elsewhere on the board
RP2040-GPIO17: RP2040.28 (GPIO17); also elsewhere on the board
RP2040-GPIO18: RP2040.29 (GPIO18); also elsewhere on the board
RP2040-GPIO19: RP2040.30 (GPIO19); also elsewhere on the board
RP2040-GPIO20: RP2040.31 (GPIO20); also elsewhere on the board
RP2040-GPIO21: RP2040.32 (GPIO21); also elsewhere on the board
RP2040-GPIO22: RP2040.34 (GPIO22); also elsewhere on the board
RP2040-GPIO23: RP2040.35 (GPIO23); also elsewhere on the board
RP2040-GPIO24: RP2040.36 (GPIO24); also elsewhere on the board
RP2040-GPIO25: RP2040.37 (GPIO25); also elsewhere on the board
RP2040-GPIO26-ADC0: RP2040.38 (GPIO26_ADC0); also elsewhere on the board
RP2040-GPIO27-ADC1: RP2040.39 (GPIO27_ADC1); also elsewhere on the board
RP2040-GPIO28-ADC2: RP2040.40 (GPIO28_ADC2); also elsewhere on the board
RP2040-GPIO29-ADC3: RP2040.41 (GPIO29_ADC3); also elsewhere on the board
RP2040-RWRAM-GPIO5-DIR: RP2040.6 (GPIO4); also elsewhere on the board
RP2040-RWRAM-GPIO7-Q7: RP2040.8 (GPIO6); also elsewhere on the board
RP2040-RWRAM-GPIO8-PL: RP2040.9 (GPIO7); also elsewhere on the board
RP2040-SH-GPIO2-SER: RP2040.3 (GPIO1); also elsewhere on the board
RP2040-SH-GPIO3-SER: RP2040.4 (GPIO2); also elsewhere on the board
RP2040-SH-GPIO4-RCLK: RP2040.5 (GPIO3); also elsewhere on the board
RP2040-SWCLK-PIN: RP2040.24 (SWCLK); also elsewhere on the board
RP2040-SWD-PIN: RP2040.25 (SWD); also elsewhere on the board
RP2040-Z80-RESET: RP2040.7 (GPIO5); also elsewhere on the board
RP2040-Z80BOOTMODE: RP2040.2 (GPIO0); also elsewhere on the board
RP2040_XIN: RP2040.20 (XIN); also elsewhere on the board
RP2040_XOUT: RP2040.21 (XOUT); also elsewhere on the board
Vcc-RP2040-RUN: RP2040.26 (RUN); also elsewhere on the board

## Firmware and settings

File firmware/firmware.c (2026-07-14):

#include "firmware.h"
#include "uart.h"
/* #include "mscDisk.h"
#include "tusb.h" */
#include <stdlib.h>

/* DEMO PROGRAM: This part of the code is part of a demo for the Z80DevBoard.
It is not intended to be used as a production firmware.
*/
#include "demo/HelloWorld.h"
#include "demo/NumberSequence.h"

#define CURRENT_DEMO_PROGRAM 0
/* END DEMO PROGRAM PART */

bool wasSerialConnected = false;
bool showLogs = false;

// Send a bus request to the Z80 and wait for the bus acknowledgment.
bool sendBusReqAndWaitBusAck() {
    if (gpio_get(GPIO_Z80_BUSACK) == 0) {
        // BUSREQ already sended and BUSACK already received
        showLogs?printf("[LOG] Received BUSACK.\n"):null;

        return true;
    }

    showLogs?printf("[LOG] Sending BUSREQ.\n"):null;
    showLogs?printf("[INFO] Remember to send a clock signal to the Z80!\n"):null;
    gpio_put(GPIO_Z80_BUSREQ, 0);

    uint32_t start = to_ms_since_boot(get_absolute_time());

    showLogs?printf("[LOG] Awaiting BUSACK.\n"):null;
    
    while (gpio_get(GPIO_Z80_BUSACK) != 0) {
        if (to_ms_since_boot(get_absolute_time()) - start > 3000) {
            showLogs?printf("[ERROR] BUSACK timeout\n"):null;

            releaseBusReq();
            
            return false;
        }
    }

    showLogs?printf("[LOG] Received BUSACK.\n"):null;

    return true;
}

// Release the bus request to the Z80.
bool releaseBusReq() {
    showLogs?printf("[LOG] Releasing BUSREQ.\n"):null;
    
    gpio_put(GPIO_Z80_BUSREQ, 1);

    return true;
}

// Access the RAM at the given address.
bool accessRamAddress(uint16_t address) {
    for (int i = 15; i >= 0; i--)
    {
        gpio_put(GPIO_RAM_ADDRESS, ((address >> i) & 1));
        gpio_put(GPIO_SHIFT_CLOCK, 1);
        gpio_put(GPIO_SHIFT_CLOCK, 0);
    }

    return true;
}

// Read a byte from the RAM.
uint8_t readRamCell() {
    uint8_t data = 0;

    gpio_put(GPIO_RAM_OPERATION, 0);
    sleep_us(1); // Wait for the RAM to prepare the data

    for (int i = 7; i >= 0; i--)
    {
        data |= (gpio_get(GPIO_RAM_DATA_READ) << i);
        gpio_put(GPIO_RAM_DATA_SHIFT, 1);
        gpio_put(GPIO_RAM_DATA_SHIFT, 0);
    }

    return data;
}

// Write a byte to the RAM.
bool writeRamCell(uint8_t data) {
    gpio_put(GPIO_RAM_OPERATION, 1);
    sleep_us(1); // Wait for the RAM to prepare the data

    for (int i = 7; i >= 0; i--)
    {
        gpio_put(GPIO_RAM_DATA, ((data >> i) & 1));
        gpio_put(GPIO_SHIFT_CLOCK, 1);
        gpio_put(GPIO_SHIFT_CLOCK, 0);
    }

    return true;
}

// Reset the Z80 to start executing the program loaded in the RAM.
void resetZ80() {
    gpio_put(GPIO_Z80_RESET, 0);
    sleep_ms(100);
    gpio_put(GPIO_Z80_RESET, 1);
}

// Read the Z80 program from the USB to the RAM.
void readZ80ProgramFromUsb(uint8_t *prog_buf) {
    /* mscDiskInit();

    showLogs?printf("[LOG] MSC disk ready.\n"):null;
    showLogs?printf("[INFO] Copy PROGRAM.BIN on the Z80DevBoard drive.\n"):null;

    // Wait for the disk to be written
    while (!mscDiskWritten()) {
        tud_task(); // Handle USB events
        sleep_ms(10);
    }

    sleep_ms(500); // Wait for the disk to be written completely
    
    mscDiskRead(prog_buf);

    showLogs?printf("[LOG] Program received from USB disk.\n"):null; */
}

// Load the Z80 program from the USB to the flash memory.
void Z80ProgramLoadHandler() {
    uint8_t *prog_buf = malloc(FLASH_LAST_32K_SIZE);

    // readZ80ProgramFromUsb(prog_buf);

    // TEMP
    memset(prog_buf, 0x00, FLASH_LAST_32K_SIZE);
    // END_TEMP

    /* DEMO PROGRAM: This part of the code is part of a demo for the Z80DevBoard.
    It is not intended to be used as a production firmware.
    */
   switch (CURRENT_DEMO_PROGRAM) {
        case 0:
            memcpy(prog_buf, HelloWorld_bin, HelloWorld_bin_len);
            break;
        case 1:
            memcpy(prog_buf, NumberSequence_bin, NumberSequence_bin_len);
            break;
        default:
            memcpy(prog_buf, HelloWorld_bin, HelloWorld_bin_len);
            break;
    }
    /* END DEMO PROGRAM PART */
    
    saveZ80ProgramInFlash(prog_buf);

    free(prog_buf);

    resetZ80();
}

// Load the Z80 program from the flash memory to the RAM.
void loadZ80ProgramInRam() {
    uint8_t *ram_buf = malloc(FLASH_LAST_32K_SIZE);

    loadZ80ProgramFromFlash(ram_buf);

    if (!sendBusReqAndWaitBusAck())
    {
        printf("[ERROR] BUSACK not recived. Aborting Z80 program loading in RAM.\n");
        
        free(ram_buf);

        releaseBusReq();
        resetZ80();
        
        return;
    }

    for (uint32_t i = 0; i < FLASH_LAST_32K_SIZE; i++)
    {
        uint8_t data = ram_buf[i];

        if (!accessRamAddress((uint16_t)i)) {
            break;
        }

        if (!writeRamCell(data)) {
            break;
        }
    }

    free(ram_buf);

    releaseBusReq();
    resetZ80();
}

// Print the serial banner to the USB terminal.
void printSerialBanner() {
    printf("+---------------------------------+\n");
    printf("|           Z80DevBoard           |\n");
    printf("|                                 |\n");
    printf("|        Official Firmware        |\n");
    printf("|         Serial Terminal         |\n");
    printf("+---------------------------------+\n\n");
}

/* 
    This function is runned only once at the start of the program.
*/
void setup() {
    // Initialize the GPIO pins
    gpio_init(GPIO_Z80_PROGRAM_LOAD);
    gpio_set_dir(GPIO_Z80_PROGRAM_LOAD, GPIO_IN);
    gpio_init(GPIO_RAM_ADDRESS);
    gpio_set_dir(GPIO_RAM_ADDRESS, GPIO_OUT);
    gpio_init(GPIO_RAM_DATA);
    gpio_set_dir(GPIO_RAM_DATA, GPIO_OUT);
    gpio_init(GPIO_SHIFT_CLOCK);
    gpio_set_dir(GPIO_SHIFT_CLOCK, GPIO_OUT);
    gpio_init(GPIO_RAM_OPERATION);
    gpio_set_dir(GPIO_RAM_OPERATION, GPIO_OUT);
    gpio_init(GPIO_Z80_RESET);
    gpio_set_dir(GPIO_Z80_RESET, GPIO_OUT); // Default to output, but may be used also as input
    gpio_init(GPIO_RAM_DATA_READ);
    gpio_set_dir(GPIO_RAM_DATA_READ, GPIO_IN);
    gpio_init(GPIO_RAM_DATA_SHIFT);
    gpio_set_dir(GPIO_RAM_DATA_SHIFT, GPIO_OUT);
    gpio_init(GPIO_Z80_BUSREQ);
    gpio_set_dir(GPIO_Z80_BUSREQ, GPIO_OUT);
    gpio_init(GPIO_Z80_BUSACK);
    gpio_set_dir(GPIO_Z80_BUSACK, GPIO_IN);

    // Expansion pins - decomment for use. Must be commented if not used.
    /* gpio_init(GPIO_EXPANSION_1);
    gpio_set_dir(GPIO_EXPANSION_1, GPIO_OUT);
    gpio_init(GPIO_EXPANSION_2);
    gpio_set_dir(GPIO_EXPANSION_2, GPIO_OUT);
    gpio_init(GPIO_EXPANSION_3);
    gpio_set_dir(GPIO_EXPANSION_3, GPIO_OUT);
    gpio_init(GPIO_EXPANSION_4);
    gpio_set_dir(GPIO_EXPANSION_4, GPIO_OUT);
    gpio_init(GPIO_EXPANSION_5);
    gpio_set_dir(GPIO_EXPANSION_5, GPIO_OUT);
    gpio_init(GPIO_EXPANSION_6);
    gpio_set_dir(GPIO_EXPANSION_6, GPIO_OUT);
    gpio_init(GPIO_EXPANSION_7);
    gpio_set_dir(GPIO_EXPANSION_7, GPIO_OUT);
    gpio_init(GPIO_EXPANSION_8);
    gpio_set_dir(GPIO_EXPANSION_8, GPIO_OUT);
    gpio_init(GPIO_EXPANSION_9);
    gpio_set_dir(GPIO_EXPANSION_9, GPIO_OUT);
    gpio_init(GPIO_EXPANSION_10);
    gpio_set_dir(GPIO_EXPANSION_10, GPIO_OUT);
    gpio_init(GPIO_EXPANSION_11);
    gpio_set_dir(GPIO_EXPANSION_11, GPIO_OUT);
    gpio_init(GPIO_EXPANSION_12);
    gpio_set_dir(GPIO_EXPANSION_12, GPIO_OUT);
    gpio_init(GPIO_EXPANSION_13);
    gpio_set_dir(GPIO_EXPANSION_13, GPIO_OUT);
    gpio_init(GPIO_EXPANSION_14);
    gpio_set_dir(GPIO_EXPANSION_14, GPIO_OUT); */

    gpio_put(GPIO_Z80_BUSREQ, 1);
    gpio_put(GPIO_Z80_RESET, 1);
    gpio_put(GPIO_SHIFT_CLOCK, 0);
    gpio_put(GPIO_RAM_OPERATION, 0);

    uartInitUsb();

    bool connectedSerial = stdio_usb_connected();
    
    if (connectedSerial && !wasSerialConnected) {
        printSerialBanner();
    }

    wasSerialConnected = connectedSerial;

    if (gpio_get(GPIO_Z80_PROGRAM_LOAD) == 0) {
        wasSerialConnected?printf("[SYSTEM] Z80 New Program Loading...\n"):null;

        Z80ProgramLoadHandler();

        wasSerialConnected?printf("[SYSTEM] New Z80 Program Loaded!\n"):null;
    }

    wasSerialConnected?printf("[SYSTEM] Loading Z80 Program in RAM...\n"):null;

    loadZ80ProgramInRam();

    wasSerialConnected?printf("[SYSTEM] Z80 Program Loaded in RAM!\n"):null;
}

/* 
    This function is runned in a loop after the setup function.
*/
void loop() {
    // Check if the USB terminal is connected
    bool connectedSerial = stdio_usb_connected();

    if (connectedSerial && !wasSerialConnected) {
        printSerialBanner();
    }

    wasSerialConnected = connectedSerial;

    // Check if a command is received from the USB terminal
    char cmd[UART_CMD_MAX_LEN];

    if (uartReadLine(cmd, sizeof(cmd))) {
        printf("> %s\n", cmd);

        uartProcessCommand(cmd);
    }
    else {
        sleep_ms(10);
    }
}

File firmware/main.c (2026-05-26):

/* 
 *  RP2040 connections:
 *  GPIO0 - Input 0 save Z80 new program from USB to flash
 *  GPIO1 - Output of the address of the RAM (serial 16 bit)
 *  GPIO2 - Output of the data of the RAM (serial 8 bit)
 *  GPIO3 - Output of the rotation clock of the shift registers
 *  GPIO4 - Output of the direction of the operation to RAM (1 for write, 0 for read)
 *  GPIO5 - Output of the RESET signal to Z80
 *  GPIO6 - Input of the byte of data read from RAM (serial 8 bit)
 *  GPIO7 - Output of the moment when read the RAM (0 for read, 1 for shift)
 *  GPIO8 - DISCONNECTED
 *  GPIO9 - DISCONNECTED
 *  GPIO10 - Output of the BUSREQ signal to Z80
 *  GPIO11 - Input of the BUSACK signal from Z80
 *  GPIO12 - Expansion Pin
 *  GPIO13 - Expansion Pin
 *  GPIO14 - Expansion Pin
 *  GPIO15 - Expansion Pin
 *  GPIO16 - Expansion Pin
 *  GPIO17 - Expansion Pin
 *  GPIO18 - Expansion Pin
 *  GPIO19 - Expansion Pin
 *  GPIO20 - Expansion Pin
 *  GPIO21 - Expansion Pin
 *  GPIO22 - Expansion Pin
 *  GPIO23 - Expansion Pin
 *  GPIO24 - Expansion Pin
 *  GPIO25 - Expansion Pin
 *  GPIO26-ADC0 - Expansion Pin
 *  GPIO27-ADC1 - Expansion Pin
 *  GPIO28-ADC2 - Expansion Pin
 *  GPIO29-ADC3 - Expansion Pin
 */

#include "firmware.h"
#include <stdbool.h>

int main() {
    setup();

    while (true)
    {
        loop();
    }

    return 0;
}

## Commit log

2025-11-27 First run. Added the Z80 (Z8400).
    [Z80DevBoard.kicad_pcb, Z80DevBoard.kicad_sch]
2025-11-27 Added the ram and the leds. Added some buttons.
    [Z80DevBoard.kicad_sch]
2025-11-28 Fixed the pin of the Z80.
    [Z80DevBoard.kicad_sch]
2025-11-28 Changed some colors in the color separators. Added the labels for each connection. Reorganized the labels and the leds.
    [Z80DevBoard.kicad_sch]
2025-11-28 Added the footprints. Started the connections.
    [Z80DevBoard.kicad_pcb, Z80DevBoard.kicad_sch]
2025-11-29 Added the RP2040. Added the flash. Finished the Z80-led connections.
    [Z80DevBoard.kicad_pcb, Z80DevBoard.kicad_sch]
2025-11-29 Added the shift register.
    [Z80DevBoard.kicad_sch]
2025-11-29 Made the paper A2, Added the data bus. Added the 74HC165.
    [Z80DevBoard.kicad_sch]
2025-11-29 Added the read data from ram hardware. Added resistors for leds and some diodes. Reorganized the spaces.
    [Z80DevBoard.kicad_sch]
2025-11-29 Added some footprints. Made the connections between the shift register and the RP2040.
    [Z80DevBoard.kicad_sch]
2025-11-29 Added the last footprints.
    [Z80DevBoard.kicad_sch]
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2025-11-30 Added the footprints. Started working on the connections.
    [Z80DevBoard.kicad_pcb]
2025-12-01 Finished the 74HC595, the 74HC165 and the SN74LVC245APW connections.
    [Z80DevBoard.kicad_pcb]
2025-12-01 Fixed the connections.
    [Z80DevBoard.kicad_pcb]
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2025-12-02 Added the last resistors.
    [Z80DevBoard.kicad_pcb]
2025-12-02 Finished the connections between the Z80 and the RAM.
    [Z80DevBoard.kicad_pcb]
2025-12-02 Fixed the GND of the Z80.
    [Z80DevBoard.kicad_pcb]
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2025-12-03 Updated some connections from the first level connections to the second level connections.
    [Z80DevBoard.kicad_pcb]
2025-12-03 Started the connections with the RP2040. Started the vcc, gnd and 3v3 connections.
    [Z80DevBoard.kicad_pcb]
2025-12-03 Connected some pins of the RP2040. Connected the data bus to the RAM.
    [Z80DevBoard.kicad_pcb]
2025-12-04 Defined the boards. Positioned the last components. Do some connections. Semplified some old connections.
    [Z80DevBoard.kicad_pcb]
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2025-12-04 Prepared the last pins of the RP2040 to be connected.
    [Z80DevBoard.kicad_pcb]
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2025-12-05 Added the values of the resistors and of the condensators.
    [Z80DevBoard.kicad_pcb]
2025-12-05 Added the buttons names. Fixed some texts. Updated the gerber files.
    [Z80DevBoard-B_Cu.gbr, Z80DevBoard-B_Mask.gbr, Z80DevBoard-B_Paste.gbr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]
2025-12-05 Added the info about the author and the github.
    [Z80DevBoard.kicad_pcb]
2025-12-05 Added the graphics in the back. Updated the gerber files.
    [Z80DevBoard-B_Cu.gbr, Z80DevBoard-B_Mask.gbr, Z80DevBoard-B_Paste.gbr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]
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2025-12-16 Fixed the borders of the board.
    [Z80DevBoard.kicad_pcb]
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2025-12-19 Added the vcc and 3v3 layer. Fixed the GND layer.
    [Z80DevBoard.kicad_pcb]
2025-12-19 Fixed vcc and 3v3 connections. Fixed GND layer. Removed old connections.
    [Z80DevBoard.kicad_pcb]
2025-12-19 Fixed the oscillators. Fixed the crystal. Fixed the connections between the RP2040 and the Flash. Updated README.
    [Z80DevBoard.kicad_pcb, Z80DevBoard.kicad_sch]
2025-12-21 Added the manual clock for the Z80. Fixed all the components. Started fixing some connections.
    [Z80DevBoard.kicad_pcb, Z80DevBoard.kicad_sch]
2025-12-21 Fixed some connections. Recreated the gerber files.
    [Z80DevBoard-B_Cu.gbr, Z80DevBoard-B_Mask.gbr, Z80DevBoard-B_Paste.gbr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]
2025-12-22 Fixed a connection. Removed some useless connections.
    [Z80DevBoard.kicad_pcb]
2025-12-22 Fixed some connections.
    [Z80DevBoard.kicad_pcb]
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2025-12-23 Added the debouncer. Fixed the board sizes.
    [Z80DevBoard.kicad_pcb, Z80DevBoard.kicad_sch]
2025-12-23 Added some info about the leds on the pcb. Recreated the gerber files. Created the drill files.
    [Z80DevBoard-B_Cu.gbr, Z80DevBoard-B_Mask.gbr, Z80DevBoard-B_Paste.gbr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]
2025-12-23 Updated the back silkscreen. Recreated the gerber files. Update readme.
    [Z80DevBoard-B_Cu.gbr, Z80DevBoard-B_Mask.gbr, Z80DevBoard-B_Paste.gbr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]
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2025-12-23 Changed the automatic clock of the Z80. Fixed the clock of the data bus. Fixed a connection. Updated component list. Recreated gerber files.
    [Z80DevBoard-B_Cu.gbr, Z80DevBoard-B_Mask.gbr, Z80DevBoard-B_Paste.gbr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]
2025-12-24 Fixed the GND layer. Update images. Recreated gerber and drill files.
    [Z80DevBoard-B_Cu.gbr, Z80DevBoard-B_Mask.gbr, Z80DevBoard-B_Paste.gbr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]
2026-02-06 Added a second sram to manage up to 64kb of memory instead of just 32.
    [Z80DevBoard.kicad_sch]
2026-02-06 Inserted the second ram. Fixed the connections to the first ram. Started the connections to the second ram.
    [Z80DevBoard.kicad_pcb]
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2026-03-01 Remade the led matrix. Added two 74HCT574 and one 74HC00.
    [Z80DevBoard.kicad_sch]
2026-03-01 Prepared the new led matrix. Fixed some connections.
    [Z80DevBoard.kicad_pcb, Z80DevBoard.kicad_sch]
2026-03-01 Connected the two 74HCT574. Started working on the Z80 D pins connections.
    [Z80DevBoard.kicad_pcb]
2026-03-01 Finished the new led matrix. Added some sqares with components info. Fixed the components names.
    [Z80DevBoard.kicad_pcb]
2026-03-02 Fixed the read/write numbers.
    [Z80DevBoard.kicad_pcb]
2026-03-03 Added the buffers also for the addresses leds.
    [Z80DevBoard.kicad_pcb, Z80DevBoard.kicad_sch]
2026-03-03 Fixed the z80 connections. Prepared the lex matrix.
    [Z80DevBoard.kicad_pcb, Z80DevBoard.kicad_sch]
2026-03-03 Fixed the led matrix. Fixed some connections.Optimized the space.
    [Z80DevBoard.kicad_pcb]
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2026-03-04 Finished the space for the address led matrix. Started the address led matrix connections.
    [Z80DevBoard.kicad_pcb]
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2026-03-04 Fixed some DRC rules.
    [Z80DevBoard.kicad_pcb]
2026-03-04 Updated the documentation. Changed the hardware license. Rebuild the gerber files. Updated the images.
    [Z80DevBoard-B_Cu.gbr, Z80DevBoard-B_Mask.gbr, Z80DevBoard-B_Paste.gbr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]
2026-03-05 Added two pins socket to support expansion boards and advanced projects.
    [Z80DevBoard.kicad_sch]
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2026-03-05 Prepared the RP2040 pins for the socket connections.
    [Z80DevBoard.kicad_pcb]
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2026-03-05 Started the connection fixing.
    [Z80DevBoard.kicad_pcb]
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2026-03-10 Made some connections between the Z80 and the expansion pins. Fixed the GND and Vcc position in the J2 pins.
    [Z80DevBoard.kicad_pcb, Z80DevBoard.kicad_sch]
2026-03-10 Finished the connection between the expansion pins and the Z80.
    [Z80DevBoard.kicad_pcb]
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2026-03-12 Fixed some little details. Updated the bus clock.
    [Z80DevBoard.kicad_pcb, Z80DevBoard.kicad_sch]
2026-03-24 Fixed the RP2040 clock capacitors. Added 2 resistors to the RP2040's XIN-XOUT.
    [Z80DevBoard.kicad_pcb, Z80DevBoard.kicad_sch]
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2026-03-25 Fixed some details.
    [Z80DevBoard.kicad_pcb]
2026-03-25 Fixed some resistors.
    [Z80DevBoard.kicad_pcb, Z80DevBoard.kicad_sch]
2026-03-25 Fixed some connections. Fixed some resistors values.
    [Z80DevBoard.kicad_pcb, Z80DevBoard.kicad_sch]
2026-03-26 Added the name of the Z80 pins. Added the Flash square.
    [Z80DevBoard.kicad_pcb]
2026-03-26 Added the pin info for the Z80. Fixed the pin names for the expansion pins.
    [Z80DevBoard.kicad_pcb]
2026-03-26 Added the debauncers for the Reset and the Wait buttons. Added a TXS0102DCT for the busack and busreq connections between the Z80 and the RP2040.
    [Z80DevBoard.kicad_pcb, Z80DevBoard.kicad_sch]
2026-03-26 Connected the wires to the 74HC14. Made some connections to the expansion pins.
    [Z80DevBoard.kicad_pcb]
2026-03-30 Finished the connections between the TXS0102DCT and the RP2040 and the Z80. Fixed some little details.
    [Z80DevBoard.kicad_pcb]
2026-03-30 Fixed the capacitors sizes.
    [Z80DevBoard.kicad_pcb, Z80DevBoard.kicad_sch]
2026-03-30 Fixed the size of the footprint of the fuse.
    [Z80DevBoard.kicad_pcb, Z80DevBoard.kicad_sch]
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2026-03-31 Fixed the size of the capacitors.
    [Z80DevBoard.kicad_pcb, Z80DevBoard.kicad_sch]
2026-03-31 Fixed the size of the Z80 and expansion pins names.
    [Z80DevBoard.kicad_pcb]
2026-03-31 Finished fixing the graphical texts. Fixed some details.
    [Z80DevBoard.kicad_pcb]
2026-03-31 Fixed the switch button.
    [Z80DevBoard.kicad_pcb, Z80DevBoard.kicad_sch]
2026-03-31 Fixed the capacitor's footprint.
    [Z80DevBoard.kicad_pcb, Z80DevBoard.kicad_sch]
2026-03-31 Fixed some footprints and connections.
    [Z80DevBoard.kicad_pcb, Z80DevBoard.kicad_sch]
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2026-03-31 Updated the gerber files. Made the gerber.zip folder.
    [Z80DevBoard-B_Cu.gbr, Z80DevBoard-B_Mask.gbr, Z80DevBoard-B_Paste.gbr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]
2026-03-31 Started working on the firmware. Replaced the TXS0102DCT with an TXS0104EPW to handle the Z80 RESET. Updated the BOM.
    [BOM.csv, Z80DevBoard.kicad_pcb, Z80DevBoard.kicad_sch]
2026-03-31 Updated the images. Updated the gerber files. Updated the step file. Testing the firmware compiler.
    [Z80DevBoard-B_Cu.gbr, Z80DevBoard-B_Mask.gbr, Z80DevBoard-B_Paste.gbr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]
2026-04-01 Modify component prices and URLs in BOM.csv
    .
    [BOM.csv]
2026-04-13 Fixed the alimentation of the RP2040, the alimentation of the Flash, the connections for the firmware loading, the crystal.
    [BOM.csv, Z80DevBoard.kicad_sch]
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2026-04-18 Updated the footprint of the expansion pins to be SMD.
    [Z80DevBoard.kicad_pcb, Z80DevBoard.kicad_sch]
2026-04-19 Cleaned the connections of the RP2040. Connected the resistors and most of the capacitors.
    [Z80DevBoard.kicad_pcb]
2026-04-19 Finished the components placement. Finished the connections between the components.
    [Z80DevBoard.kicad_pcb]
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2026-04-19 Fixed some details. Updated the README file.
    [Z80DevBoard-B_Cu.gbr, Z80DevBoard-B_Mask.gbr, Z80DevBoard-B_Paste.gbr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]
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2026-04-21 Update prices and links for components in BOM.csv
    [BOM.csv]
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2026-05-11 Made the usb-c and the connected info chapters. Updated the KiCad files to KiCad 10.0.
    [Z80DevBoard.kicad_pcb, Z80DevBoard.kicad_sch]
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2026-05-28 Writed the developing an expansion board chapter. Fixed some graphical details in the docs.
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2026-06-26 Fixed the z80 program write in flash. Fixed the serial connection. Fixed some other generic bugs.
    [firmware.c, firmware.h, uart.c]
2026-06-26 Fixed some address access bugs.
    [firmware.c, firmware.h, uart.c]
2026-06-26 Fixed a serial bug. Rebuild the firmware.
    [uart.c]
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2026-06-26 Fixed the busreq and busack bug.
    [firmware.c, firmware.h]
2026-06-30 Fixed some bugs in the firmware. Removed some useless folders.
    [firmware.c, firmware.h, uart.c]
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2026-07-01 Fixed a log bug.
    [firmware.c]
2026-07-03 Fixed the showLogs flag. Created the usb descriptors. Updated gitignore. Rebuild the firmware.
    [firmware.h, uart.c]
2026-07-09 Started fixing the conflict between the USB interface and the serial connection.
    [firmware.c, uart.c]
2026-07-09 Fixed another conflict between serial and usb interfaces.
    [firmware.c, firmware.h, uart.c]
2026-07-09 Fixed the serial connection. Need to introduce the usb Z80 program loading.
    [firmware.c, firmware.h, uart.c]
2026-07-10 Fixed some little details.
    [firmware.c]
2026-07-14 Fixed useless ripetitive busreq in the loading of the Z80 program in RAM.
    [firmware.c]
2026-07-14 Fixed the busreq and busack system. Fixed the never released busreq after a serial command. Removed the --force from the commands (no more needed). Updated TODO.md.
    [firmware.c, firmware.h, uart.c]
2026-07-14 Updated some comments. Fixed some little bugs in mscDisk.
    [firmware.c, firmware.h, uart.c]

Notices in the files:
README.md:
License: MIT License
